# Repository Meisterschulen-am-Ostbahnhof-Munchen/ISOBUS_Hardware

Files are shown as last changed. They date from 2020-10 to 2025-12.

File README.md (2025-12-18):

# ISOBUS Hardware

Welcome to the **ISOBUS Hardware** repository by **Meisterschulen am Ostbahnhof, München**. This repository hosts hardware designs for Open Source ISOBUS ECUs.

## 📂 Projects

### [Hutschienenmoped](./Hutschienenmoped)
The **Hutschienenmoped** is an Open Source ISOBUS ECU designed for DIN rail mounting.

* **📂 Source Code:** [View Directory](./Hutschienenmoped)
* **📖 Documentation:** [Read the Docs](https://install-isobus-environment-docs.readthedocs.io/de/latest/HutschienenMoped.html)

---

### [Hutschienenmoped XL](./Hutschienenmoped-XL)
The **Hutschienenmoped XL** is an extended version of the Open Source ISOBUS ECU.

* **📂 Source Code:** [View Directory](./Hutschienenmoped-XL)
* **🏅 Open Hardware:** Certified under [DE000145](https://certification.oshwa.org/de000145.html)

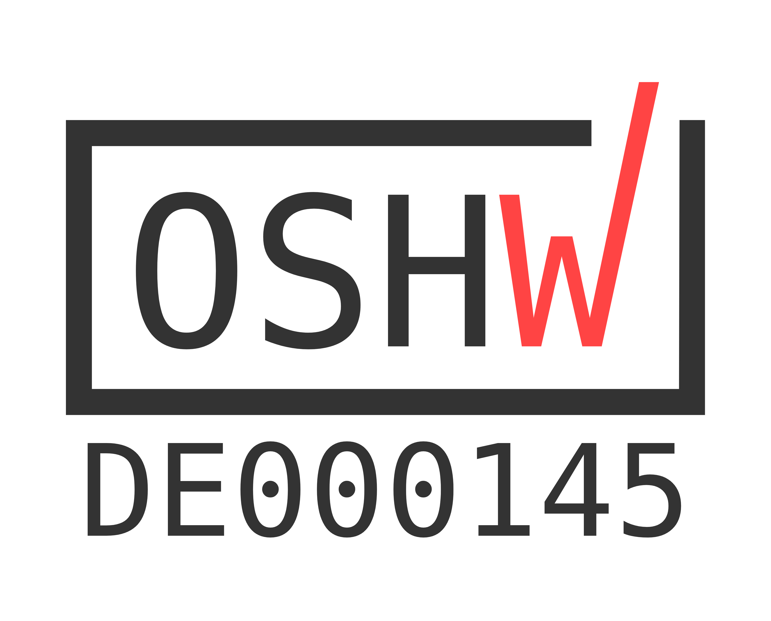
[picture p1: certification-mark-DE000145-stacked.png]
OSHWA Certification DE000145


## 📜 License

This project is licensed under a **Creative Commons Attribution-ShareAlike 4.0 International License (CC BY-SA 4.0)**.

* **Hutschienenmoped** by Meisterschulen am Ostbahnhof, München
* **ISOBUS_Hardware** by Meisterschulen am Ostbahnhof, München



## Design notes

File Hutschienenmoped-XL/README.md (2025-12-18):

# Hutschienenmoped XL

Das **Hutschienenmoped XL** ist ein innovatives Gerät, das speziell für die Integration in ISOBUS-Systeme entwickelt wurde. Es handelt sich dabei um eine Open-Source-ECU (Electronic Control Unit), die mit den Standards **ISO 11783** und **IEC 61499** kompatibel ist. Diese Kompatibilität ermöglicht eine nahtlose Kommunikation und Steuerung von landwirtschaftlichen Maschinen und Anbaugeräten.

### Vorteile
* **Flexibilität:** Durch die Open-Source-Natur des Projekts können Benutzer die Software und Hardware nach ihren Bedürfnissen anpassen und erweitern.
* **Kompatibilität:** Es unterstützt eine Vielzahl von ISOBUS-kompatiblen Geräten, was die Integration in bestehende Systeme erleichtert.
* **Zukunftssicherheit:** Dank der Einhaltung internationaler Standards ist das Gerät zukunftssicher und kann in verschiedenen landwirtschaftlichen Anwendungen eingesetzt werden.

---

## 🛠 CAD & 3D-Design (Fusion 360)

Das Projekt wird derzeit in Fusion 360 migriert. Hier finden Sie die aktuellen Modelle:

* 🔌 **[Hauptplatine (PCB)](https://a360.co/3YcFeBx)**
* 📦 **[Zusammenbau (Assembly)](https://a360.co/4cJ5Ajy)**

### Galerie

Hauptplatine Ansicht 1

Hauptplatine Ansicht 2

Gehäuse Ansicht

---

## 📜 Lizenz

Dieses Projekt ist lizenziert unter einer **Creative Commons Attribution-ShareAlike 4.0 International License (CC BY-SA 4.0)**.

* **Urheber:** [Meisterschulen am Ostbahnhof, München](https://github.com/Meisterschulen-am-Ostbahnhof-Munchen)
* **Projekt:** [Hutschienenmoped](https://github.com/Meisterschulen-am-Ostbahnhof-Munchen/ISOBUS_Hardware)



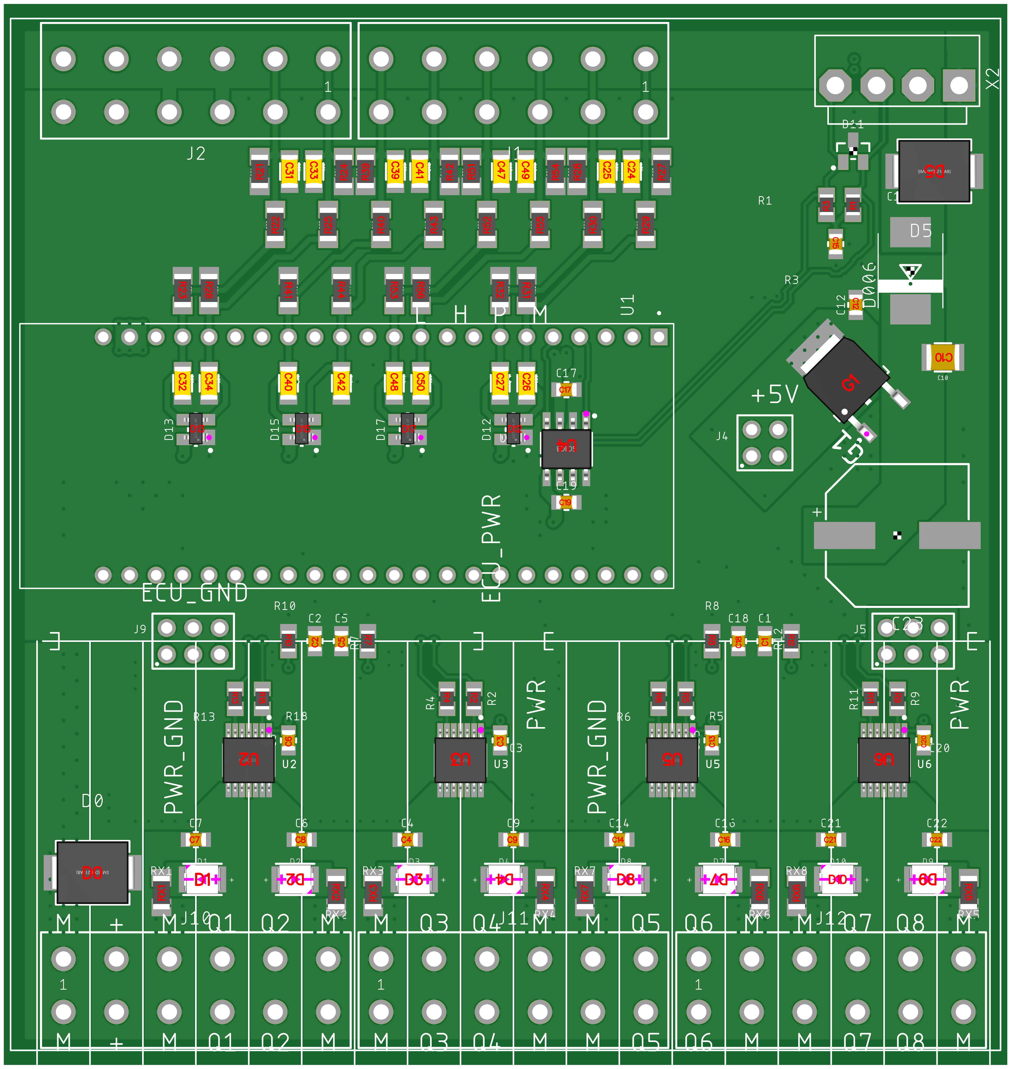
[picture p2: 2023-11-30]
Hutschienenmoped-XL/3ead6b43bb714cc0af7176151830c89e.png

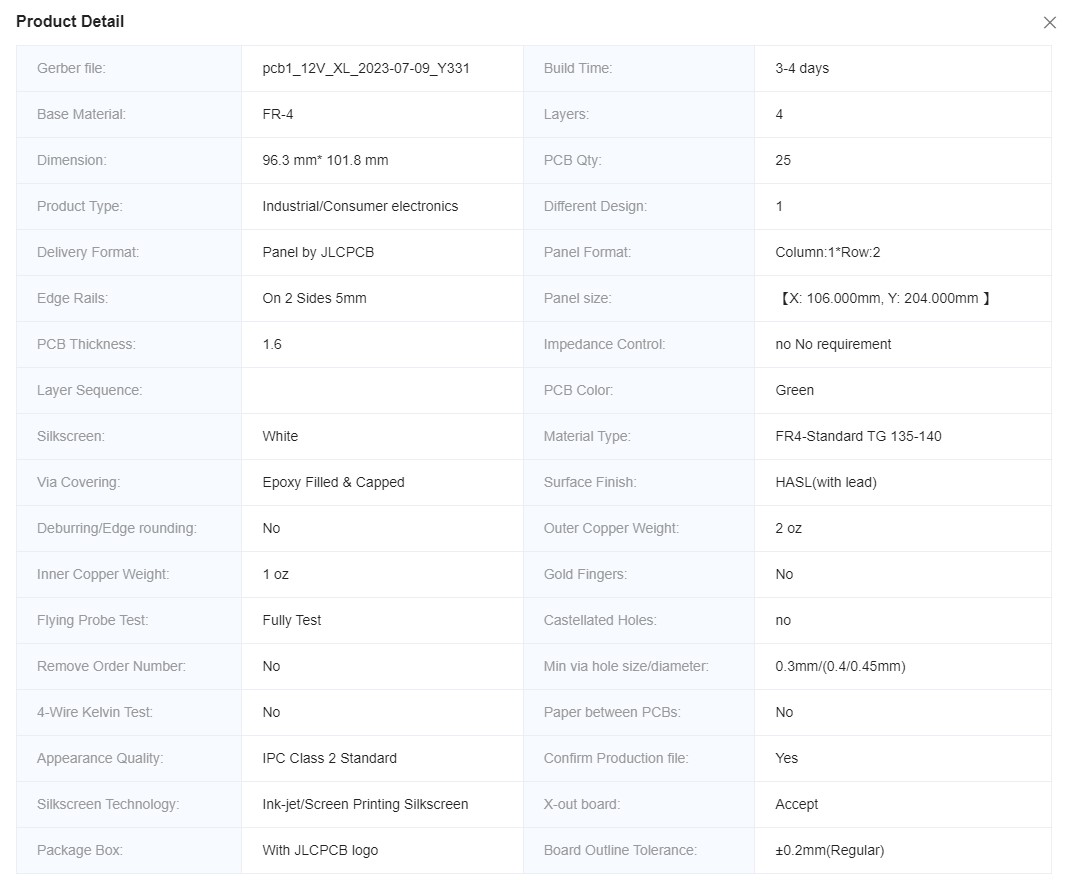
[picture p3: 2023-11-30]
Hutschienenmoped-XL/Screenshot 2023-11-30 084542.jpg

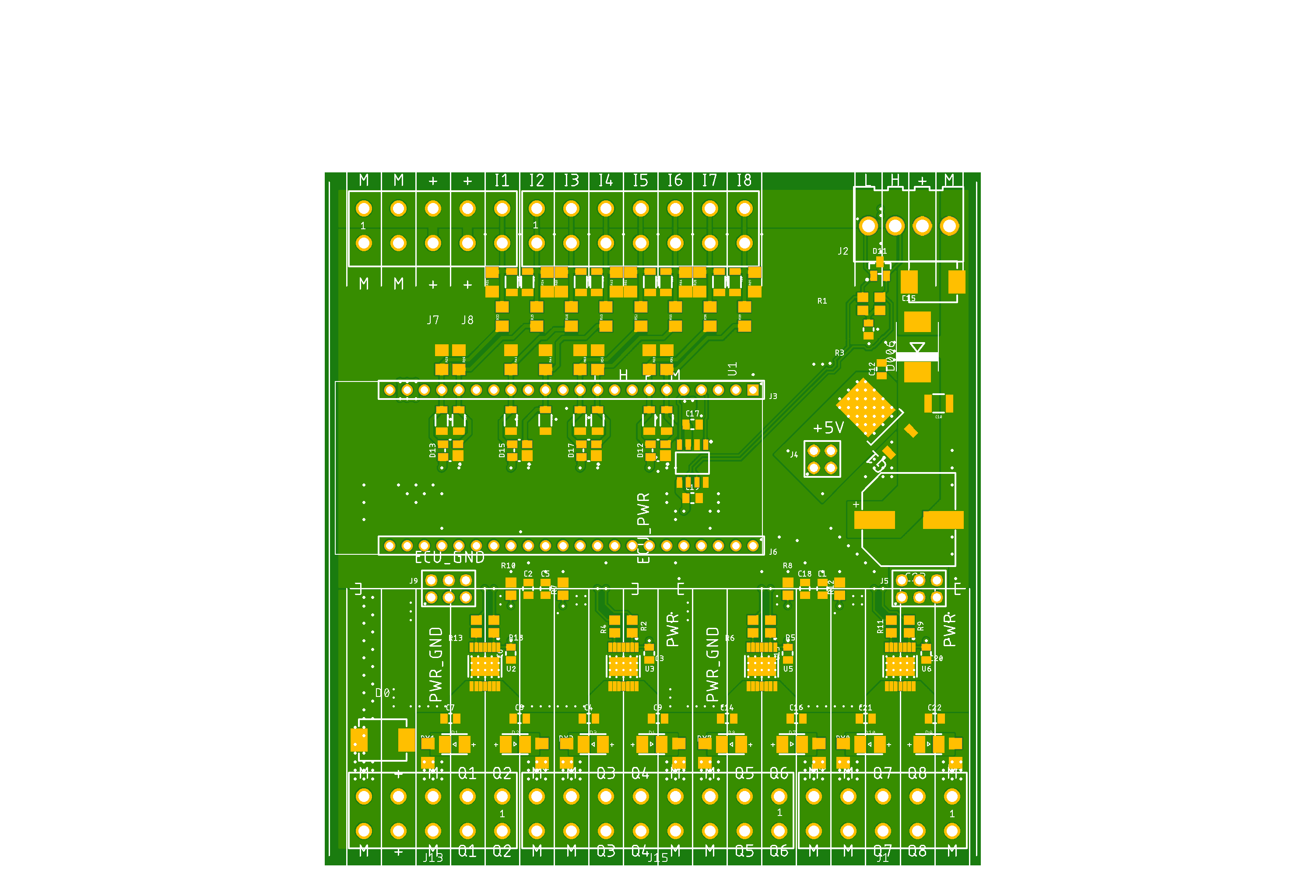
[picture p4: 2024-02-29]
Hutschienenmoped-XL/Hauptplatine/Hauptplatine.png

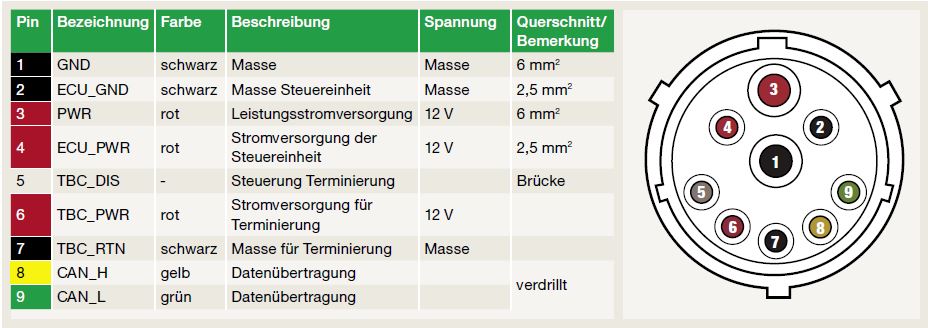
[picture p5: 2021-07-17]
Hutschienenmoped/Übersicht2.jpg

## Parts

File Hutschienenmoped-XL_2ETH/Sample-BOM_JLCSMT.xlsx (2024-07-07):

Comment | Designator | Footprint | JLCPCB Part #（optional）
 | J5, J9 | 61300621121
 | U2, U3, U5, U6 | SOP65P600X115-15N-V
 | G1 | INF-PG-TO252-3-11_N
61300421121 | J4 | 61300421121
61300615721 | W1-J2, W2-J2 | 61300615721
61301015721 | W1-J1, W2-J1 | 61301015721
61302211821 | ESP32-J1, ESP32-J3 | 61302211821
638207222005 | J1, J7, J13 | 638207222005
638207222007 | J8 | 638207222007
638207222008 | J15 | 638207222008
100nF | C1, C2, C3, C5, C6, C13, C17, C18, C19, C20 | WCAP-CSGP_0805_H0.8_R
100nF | C24, C25, C26, C27, C31, C32, C33, C34, C39, C40, C41, C42, C47, C48, C49, C50 | WCAP-CSGP_1206_H0.8
10nF | C4, C7, C8, C9, C14, C16, C21, C22 | WCAP-CSGP_0805_H0.8_R
13K | R14, R15, R23, R26, R31, R32, R41, R44, R53, R56 | R1206
150141VS73100 | D1, D2, D3, D4, D7, D8, D9, D10 | WL-SMTW_3528
1K2 | R21, R24, R27, R28, R39, R42, R51, R54 | R1206
22uF | C12 | WCAP-CSGP_0805_H1.25_R
22uF | C10 | WCAP-CSGP_1210_H2.5
24Vdc | D11 | WE-TVS_SOT23-3L
3.3Vdc | D12, D13, D15, D17 | WE-TVS_SOT143-4L
330 ÂµF | C23 | WCAP-ASLI_12.5X14(DXL)
33V | D0, D5 | WE-TVSP_DO-214AB_BIDIRECTIONAL
470Ohm | RX1, RX2, RX3, RX4, RX5, RX6, RX7, RX8 | R1206
47K | R22, R25, R29, R30, R40, R43, R52, R55 | R1206
47R | R7, R8, R10, R12 | R0805
47nF | C15 | WCAP-CSGP_0805_H0.8_R
4k7 | R2, R4, R5, R6, R9, R11, R13, R18 | R0805
60R | R1, R3 | R0805
645004114822 | J2 | 645004114822
M3 x 2.5mm | MP1, MP2, MP3, MP4, MP5, MP6, MP7, MP8 | WA-SMSI_9774025360
MBRS340T3 | D006 | SMC
TLE9250VSJ | U4 | SOIC127P602X173-8N-V

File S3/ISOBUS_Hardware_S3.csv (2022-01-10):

Qty | Value | Device | Package | Parts | Description | DATASHEET-URL | DESCRIPTION | DF | DIAMETER | GENDER | HEIGHT | I-LEAK | I-OUTPUT | I-RIPPLE | IR | L | MANUFACTURER_NAME | MANUFACTURER_PART_NUMBER | MOUNT | MOUSER_PART_NUMBER | MOUSER_PRICE-STOCK | OPERATING-TEMPERATURE | PACKAGING | PART-NUMBER | PINS | PITCH | ROWS | TECHNICAL-REFERENCE | TYPE | V-INPUT | V-OUTPUT | VALUE | VR
1 |  | MAGI³C-FDSM_SIP-3_173010542_173XXXX42 | MAGI³C-FDSM_173XXXX42 | U1 | MagI³C-FDSM Fixed Step Down Regulator Module | https://www.we-online.de/katalog/datasheet/173010542.pdf |  |  |  |  |  |  | 1A |  |  |  |  |  | THT |  |  |  |  | 173010542 |  |  |  |  |  | 8-42V | 5V
2 |  | R-EU_0204/7 | 0204/7 | R1, R2 | RESISTOR, European symbol
2 | 61304421821 | 6130XX21821_61304421821 | 61304421821 | J1, J2 | WR-PHD 2.54 mm Dual Socket Header | https://www.we-online.com/catalog/datasheet/61304421821.pdf |  |  |  | Socket Header |  |  |  |  | 3A |  |  |  | THT |  |  |  | Tray | 61304421821 | 44 | 2.54mm | Dual |  | Straight |  |  | 61304421821
1 | 220 µF | WCAP-ATG8_6.3X11_860010373010 | WCAP-ATG8_6.3X11(DXL) | C6 | WCAP-ATG8 Aluminium Electrolytic Capacitors | https://www.we-online.com/catalog/datasheet/860010373010.pdf |  | 16% | 6.3mm |  |  | 35.2uA |  | 308mA |  | 11mm |  |  |  |  |  | -40 °C up to +85 °C |  | 860010373010 |  | 2.5mm |  | ATBD110221M016DSPA4B000 |  |  |  | 220 µF | 16V(DC)
1 | DTF13-4P | DTF13-4P | DTF134P | J3 | Automotive Connectors 4P DTF RECP ASM 90 DEG. HEADER |  | Automotive Connectors 4P DTF RECP ASM 90 DEG. HEADER |  |  |  | 20.22mm |  |  |  |  |  | TE Connectivity | DTF13-4P |  | 571-DTF13-4P | https://www.mouser.co.uk/ProductDetail/TE-Connectivity-DEUTSCH/DTF13-4P?qs=vkMqrgFpRaj6YYUKpv5OLg%3D%3D
4 | FG18X7R1H104KNT06 | FG18X7R1H104KNT06 | FG18C0G1H101JNT06 | C1, C2, C4, C5 | Multilayer Ceramic Capacitors MLCC - Leaded RAD 50V 0.1uF X7R 10% LS:2.5mm |  | Multilayer Ceramic Capacitors MLCC - Leaded RAD 50V 0.1uF X7R 10% LS:2.5mm |  |  |  | 5.5mm |  |  |  |  |  | TDK | FG18X7R1H104KNT06 |  | 810-FG18X7R1H104KNT6 | https://www.mouser.co.uk/ProductDetail/TDK/FG18X7R1H104KNT06?qs=qf2ddTMq67WA8sH6FratLA%3D%3D
1 | FG28X7R1H473KNT06 | FG28X7R1H473KNT06 | FG28 | C3 | MLCC with dipped radial lead |  | MLCC with dipped radial lead |  |  |  | 5.5mm |  |  |  |  |  | TDK | FG28X7R1H473KNT06 |  | 810-FG28X7R1H473KNT6 | https://www.mouser.com/Search/Refine.aspx?Keyword=810-FG28X7R1H473KNT6
1 | MCP2562-E_P | MCP2562-E_P | DIP781W56P254L950H533Q8N | IC1 | CAN Transceiver 1Mbps 5V 125degC PDIP8 Microchip MCP2562-E/P, CAN Transceiver 1-channel IEC 61000-4-2, 8-Pin PDIP |  | CAN Transceiver 1Mbps 5V 125degC PDIP8 Microchip MCP2562-E/P, CAN Transceiver 1-channel IEC 61000-4-2, 8-Pin PDIP |  |  |  | 5.334mm |  |  |  |  |  | Microchip | MCP2562-E/P |  | 579-MCP2562-E/P | https://www.mouser.co.uk/ProductDetail/Microchip-Technology/MCP2562-E-P?qs=6qKXPk0vzx1U%252B0h82Z%2Fybg%3D%3D

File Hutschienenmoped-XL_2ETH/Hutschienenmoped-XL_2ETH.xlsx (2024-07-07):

Qty | Value | Device | Package | Parts | Description
2 |  | 6130XX21121_61300621121 | 61300621121 | J5, J9 | WR-PHD 2.54 mm THT Dual Pin Header
4 |  | BTS7030-2EPA | SOP65P600X115-15N-V | U2, U3, U5, U6 | BTS7030-2EPA
1 |  | IFX27001TF_V50 | INF-PG-TO252-3-11_N | G1 | IFX27001TF V50
1 | 61300421121 | 6130XX21121_61300421121 | 61300421121 | J4 | WR-PHD 2.54 mm THT Dual Pin Header
2 | 61300615721 | 6130XX15721_61300615721 | 61300615721 | W1-J2, W2-J2 | WR-PHD 2.54 mm Socket Header Bottom Entry
2 | 61301015721 | 6130XX15721_61301015721 | 61301015721 | W1-J1, W2-J1 | WR-PHD 2.54 mm Socket Header Bottom Entry
2 | 61302211821 | 6130XX11821_61302211821 | 61302211821 | ESP32-J1, ESP32-J3 | WR-PHD 2.54 mm Socket Header
3 | 638207222005 | 638207222005 | 638207222005 | J1, J7, J13 | WR-FAST 5.08 mm THT Male Header Vertical Blade 2863
1 | 638207222007 | 638207222007 | 638207222007 | J8 | WR-FAST 5.08 mm THT Male Header Vertical Blade 2863
1 | 638207222008 | 638207222008 | 638207222008 | J15 | WR-FAST 5.08 mm THT Male Header Vertical Blade 2863
10 | 100nF | WCAP-CSGP_0805_H0.8_885012207098_50V(DC)_R | WCAP-CSGP_0805_H0.8_R | C1, C2, C3, C5, C6, C13, C17, C18, C19, C20 | WCAP-CSGP MLCCs 0805
16 | 100nF | WCAP-CSGP_1206_H0.8_885012208087_50V(DC) | WCAP-CSGP_1206_H0.8 | C24, C25, C26, C27, C31, C32, C33, C34, C39, C40, C41, C42, C47, C48, C49, C50 | WCAP-CSGP MLCCs 1206
8 | 10nF | WCAP-CSGP_0805_H0.8_885012207092_50V(DC)_R | WCAP-CSGP_0805_H0.8_R | C4, C7, C8, C9, C14, C16, C21, C22 | WCAP-CSGP MLCCs 0805
10 | 13K | R-EU_R1206 | R1206 | R14, R15, R23, R26, R31, R32, R41, R44, R53, R56 | RESISTOR, European symbol
8 | 150141VS73100 | WL-SMTW_3528_150141VS73100 | WL-SMTW_3528 | D1, D2, D3, D4, D7, D8, D9, D10 | WL-SMTW SMT Mono-color TOP LED Waterclear
8 | 1K2 | R-EU_R1206 | R1206 | R21, R24, R27, R28, R39, R42, R51, R54 | RESISTOR, European symbol
1 | 22uF | WCAP-CSGP_0805_H1.25_885012107011_10V(DC) | WCAP-CSGP_0805_H1.25_R | C12 | WCAP-CSGP MLCCs 0805
1 | 22uF | WCAP-CSGP_1210_H2.5_885012109014_25V(DC) | WCAP-CSGP_1210_H2.5 | C10 | WCAP-CSGP MLCCs 1210
1 | 24Vdc | WE-TVS_SOT23-3L_824094024 | WE-TVS_SOT23-3L | D11 | WE-TVS TVS Diode â€“ Standard Series
4 | 3.3Vdc | WE-TVS-HS_SOT143-4L_8240136 | WE-TVS_SOT143-4L | D12, D13, D15, D17 | WE-TVS TVS Diode â€“ High Speed Series
1 | 330 ÂµF | WCAP-ASLI_12.5X14_865080662019 | WCAP-ASLI_12.5X14(DXL) | C23 | WCAP-ASLI Aluminium Electrolytic Capacitors
2 | 33V | WE-TVSP_DO-214AB_3000W_BI_824551331 | WE-TVSP_DO-214AB_BIDIRECTIONAL | D0, D5 | WE-TVSP Power TVS Diode
8 | 470Ohm | R-EU_R1206 | R1206 | RX1, RX2, RX3, RX4, RX5, RX6, RX7, RX8 | RESISTOR, European symbol
8 | 47K | R-EU_R1206 | R1206 | R22, R25, R29, R30, R40, R43, R52, R55 | RESISTOR, European symbol
4 | 47R | R-EU_R0805 | R0805 | R7, R8, R10, R12 | RESISTOR, European symbol
1 | 47nF | WCAP-CSGP_0805_H0.8_885012207096_50V(DC)_R | WCAP-CSGP_0805_H0.8_R | C15 | WCAP-CSGP MLCCs 0805
8 | 4k7 | R-EU_R0805 | R0805 | R2, R4, R5, R6, R9, R11, R13, R18 | RESISTOR, European symbol
2 | 60R | R-EU_R0805 | R0805 | R1, R3 | RESISTOR, European symbol
1 | 645004114822 | 645004114822 | 645004114822 | J2 | WR-WTB 3.96 mm Male Vertical Locking Header
8 | M3 x 2.5mm | WA-SMSI_9774XXX360_9774025360R | WA-SMSI_9774025360 | MP1, MP2, MP3, MP4, MP5, MP6, MP7, MP8 | WA-SMSI SMT Steel Spacer with internal Thread M3
1 | MBRS340T3 | MBRS340T3 | SMC | D006 | SCHOTTKY BARRIER RECTIFIER 3.0 AMPERES 20, 30, 40 VOLT
1 | TLE9250VSJ | TLE9250VSJ | SOIC127P602X173-8N-V | U4 | TLE9250VSJ

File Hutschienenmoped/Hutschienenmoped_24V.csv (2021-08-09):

Qty | Value | Device | Package | Parts | Description | ALLIED_NUMBER | ALLIED_PRICE-STOCK | ARTIKEL_NR | CERAMIC-TYPE | CHIP-TECHNOLOGY | CONTACT-RESISTANCE | DATASHEET-URL | DESCRIPTION | DF | DIGI-KEY_PART_NUMBER | EMITTING-COLOR | GENDER | H | HEIGHT | I-V-TYP | IPEAK | IR | KOMPONENTENNUMMER | LAMDA-DOM-TYP | LAMDA-PEAK-TYP | MANUFACTURER_NAME | MANUFACTURER_PART_NUMBER | MATES | MF | MOUNT | MOUSER_PART_NUMBER | MOUSER_PRICE-STOCK | MP | OPERATING-TEMPERATURE | PACKAGE | PACKAGING | PART-NUMBER | PDISS | PHI-V-TYP | PINS | PITCH | PRATED | QMIN | RISO | ROWS | RS_PART_NUMBER | RS_PRICE-STOCK | TCR | TECHNICAL-REFERENCE | TOL-VALUE | TYPE | V-F-TYP | VALUE | VBR | VCLAMP | VIEWING-ANGLE | VR | WE-NUMBER | WORKING-VOLTAGE
1 |  | 6130XX11121_61300411121 | 61300411121 | J2 | WR-PHD 2.54 mm THT Pin Header |  |  |  |  |  |  | https://katalog.we-online.com/em/datasheet/61300411121.pdf |  |  |  |  | Pin Header |  |  |  |  | 3A |  |  |  |  |  | WR-PHD 2.54mm Angled Socket Header /SMT Socket Header/Socket Header |  |  |  |  |  |  |  | Bag | 61300411121 |  |  | 4 |  |  |  |  | Single |  |  |  |  |  | Straight
1 |  | 6130XX11121_61300511121 | 61300511121 | J3 | WR-PHD 2.54 mm THT Pin Header |  |  |  |  |  |  | https://katalog.we-online.com/em/datasheet/61300511121.pdf |  |  |  |  | Pin Header |  |  |  |  | 3A |  |  |  |  |  | WR-PHD 2.54mm Angled Socket Header /SMT Socket Header/Socket Header |  |  |  |  |  |  |  | Bag | 61300511121 |  |  | 5 |  |  |  |  | Single |  |  |  |  |  | Straight
2 |  | 6130XX21121_61300621121 | 61300621121 | J5, J9 | WR-PHD 2.54 mm THT Dual Pin Header |  |  |  |  |  |  | https://katalog.we-online.com/em/datasheet/61300621121.pdf |  |  |  |  | Pin Header |  |  |  |  | 3A |  |  |  |  |  | WR-PHD 2.54mm Angled DualSocket Header/Dual Socket Header/Dual Socket Header Bottom Entry/Dual Socket Header Bottom Entry Large/SMT Dual Socket Header/SMT Dual Socket Header Bottom Entry |  |  |  |  |  |  |  | Bag | 61300621121 |  |  | 6 |  |  |  |  | Dual |  |  |  |  |  | Board Stacker
1 |  | 6130XX21121_61301821121 | 61301821121 | J1 | WR-PHD 2.54 mm THT Dual Pin Header |  |  |  |  |  |  | https://katalog.we-online.com/em/datasheet/61301821121.pdf |  |  |  |  | Pin Header |  |  |  |  | 3A |  |  |  |  |  | WR-PHD 2.54mm Angled DualSocket Header/Dual Socket Header/Dual Socket Header Bottom Entry/Dual Socket Header Bottom Entry Large/SMT Dual Socket Header/SMT Dual Socket Header Bottom Entry |  |  |  |  |  |  |  | Bag | 61301821121 |  |  | 18 |  |  |  |  | Dual |  |  |  |  |  | Board Stacker
2 | 638207222005 | 638207222005 | 638207222005 | J6, J7 | WR-FAST 5.08 mm THT Male Header Vertical Blade 2863 |  |  |  |  |  | 20mOhm | https://www.we-online.com/catalog/datasheet/638207222005.pdf |  |  |  |  | Male |  |  |  |  | 16A |  |  |  |  |  |  |  | THT |  |  |  |  |  |  | 638207222005 |  |  | 5 | 5.08mm |  |  |  |  |  |  |  |  |  | Vertical |  | 638207222005 |  |  |  |  |  | 300V(AC)
4 | 10 nF | WCAP-CSGP_0805_H0.8_885012207092_50V(DC)_R | WCAP-CSGP_0805_H0.8_R | C4, C7, C8, C9 | WCAP-CSGP MLCCs 0805 |  |  |  | X7R Class II |  |  | https://www.we-online.com/catalog/datasheet/885012207092.pdf |  | 0.025 |  |  |  | 0.8mm |  |  |  |  |  |  |  |  |  |  |  |  |  |  |  | -55 °C up to +125 °C |  |  | 885012207092 |  |  |  |  |  | - | 10GOhm |  |  |  |  | X7R0805103K050DFCT10000 | ±10% |  |  | 10 nF |  |  |  | 50V(DC)
4 | 100 nF | WCAP-CSGP_0805_H0.8_885012207098_50V(DC)_R | WCAP-CSGP_0805_H0.8_R | C2, C5, C17, C19 | WCAP-CSGP MLCCs 0805 |  |  |  | X7R Class II |  |  | https://www.we-online.com/catalog/datasheet/885012207098.pdf |  | 0.025 |  |  |  | 0.8mm |  |  |  |  |  |  |  |  |  |  |  |  |  |  |  | -55 °C up to +125 °C |  |  | 885012207098 |  |  |  |  |  | - | 5GOhm |  |  |  |  | X7R0805104K050DFCT10000 | ±10% |  |  | 100 nF |  |  |  | 50V(DC)
1 | 100 nF | WCAP-CSGP_0402_885012205037_16V(DC) | WCAP-CSGP_0402 | C11 | WCAP-CSGP MLCCs 0402 |  |  | 545504 | X7R Class II |  |  |  |  |  |  |  |  |  |  |  |  |  |  |  |  |  |  |  |  |  |  |  |  |  |  |  | 885012205037 |  |  |  |  |  |  |  |  |  |  |  |  | ±10% |  |  | 100 nF |  |  |  | 16V(DC)
4 | 150141VS73100 | WL-SMTW_3528_150141VS73100 | WL-SMTW_3528 | D1, D2, D3, D4 | WL-SMTW SMT Mono-color TOP LED Waterclear |  |  |  |  | AlInGaP |  | https://www.we-online.com/catalog/datasheet/150141VS73100.pdf |  |  |  | Bright Green |  |  |  | 90mcd |  |  |  | 570nm | 572nm |  |  |  |  |  |  |  |  |  |  |  | 150141VS73100 |  | - |  |  |  |  |  |  |  |  |  |  |  |  | 2V | 150141VS73100 |  |  | 120°
1 | 22 µF | WCAP-CSGP_0805_H1.25_885012107011_10V(DC) | WCAP-CSGP_0805_H1.25_R | C12 | WCAP-CSGP MLCCs 0805 |  |  |  | X5R Class II |  |  | https://www.we-online.com/catalog/datasheet/885012107011.pdf |  | 0.1 |  |  |  | 1.25mm |  |  |  |  |  |  |  |  |  |  |  |  |  |  |  | -55 °C up to +85 °C |  |  | 885012107011 |  |  |  |  |  | - | 0,005GOhm |  |  |  |  | X5R0805226M010DFCT10000 | ±20% |  |  | 22 µF |  |  |  | 10V(DC)
1 | 22µF | WCAP-CSGP_1210_H2.5_885012109014_25V(DC) | WCAP-CSGP_1210_H2.5 | C10 | WCAP-CSGP MLCCs 1210 |  |  |  | X5R Class II |  |  | https://www.we-online.com/catalog/datasheet/885012109014.pdf |  | 0.05 |  |  |  | 2.5mm |  |  |  |  |  |  |  |  |  |  |  |  |  |  |  | -55 °C up to +85 °C |  |  | 885012109014 |  |  |  |  |  | - | 0,005G Ohm |  |  |  |  | X5R1210226M025DFCT10000 | ±20% |  |  | 22µF |  |  |  | 25V(DC)
1 | 26.2V / 35pF | WE-TVS_SOT23-3L_824098024 | WE-TVS_SOT23-3L | D6 | WE-TVS TVS Diode Standard Series |  |  | 531887 |  |  |  |  |  |  |  |  |  |  |  |  |  |  | 617684 |  |  |  |  |  |  |  |  |  |  |  |  |  |  |  |  |  |  |  |  |  |  |  |  |  |  |  |  |  | 26.2V / 35pF |  |  |  |  | 824098024
2 | 27R | R-EU_R0805 | R0805 | R7, R10 | RESISTOR, European symbol
2 | 2k2 | R-EU_R0805 | R0805 | R5, R6 | RESISTOR, European symbol
2 | 33V | WE-TVSP_DO-214AB_3000W_BI_824551331 | WE-TVSP_DO-214AB_BIDIRECTIONAL | D0, D5 | WE-TVSP Power TVS Diode |  |  |  |  |  |  | https://www.we-online.com/catalog/datasheet/824551331.pdf |  |  |  |  |  |  |  |  | 56.3A |  |  |  |  |  |  |  |  | SMT |  |  |  |  |  |  | 824551331 | 3000W |  |  |  |  |  |  |  |  |  |  |  |  |  |  | 33V | 38.65V | 53.3V
1 | 47 nF | WCAP-CSGP_0805_H0.8_885012207096_50V(DC)_R | WCAP-CSGP_0805_H0.8_R | C15 | WCAP-CSGP MLCCs 0805 |  |  |  | X7R Class II |  |  | https://www.we-online.com/catalog/datasheet/885012207096.pdf |  | 0.025 |  |  |  | 0.8mm |  |  |  |  |  |  |  |  |  |  |  |  |  |  |  | -55 °C up to +125 °C |  |  | 885012207096 |  |  |  |  |  | - | 10GOhm |  |  |  |  | X7R0805473K050DFCT10000 | ±10% |  |  | 47 nF |  |  |  | 50V(DC)
4 | 470Ohm | WRIS-KWKB_0612_561020132023 | WRIS-KWKB_0612 | RX1, RX2, RX3, RX4 | WRIS-KWKB Thick Film Resistors |  |  |  |  |  |  | https://katalog.we-online.de/pbs/datasheet/561020132023.pdf |  |  |  |  |  |  |  |  |  | 39.9mA |  |  |  |  |  |  |  | SMT |  |  |  |  |  |  | 561020132023 |  |  |  |  | 0.75W |  |  |  |  |  | ±200ppm/ °C | KB06124700J304DAATP0000 |  |  |  | 470Ohm
4 | 4k7 | R-EU_R0805 | R0805 | R2, R4, R13, R18 | RESISTOR, European symbol
2 | 60R | R-EU_R0805 | R0805 | R1, R3 | RESISTOR, European symbol
2 | ITS4040DEPDXUMA1 | ITS4040DEPDXUMA1 | SOP65P600X115-15N | U2, U3 | Power Switch/Driver 1:1 N-Channel 2.6A PG-TSDSO-14 |  |  |  |  |  |  |  | Power Switch/Driver 1:1 N-Channel 2.6A PG-TSDSO-14 |  | ITS4040DEPDXUMA1TR-ND |  |  |  |  |  |  |  |  |  |  |  |  |  | Infineon Technologies |  |  |  | ITS4040DEPDXUMA1 |  | TSSOP-14 Infineon Technologies
1 | S4P-VH | S4P-VH | S4P-VH | X1 | JST VH Series header 3.96mm pitch disconnectable crimp style connectors, horizontal (side entry type), 4 pins
1 | TLE4270-2D-INF-PG-TO252-5-11_L_1 | TLE4270-2D-INF-PG-TO252-5-11_L_1 | INF-PG-TO252-5-11_L_1PRIMARY | G1
1 | TLE9250VSJ | TLE9250VSJ | SOIC127P602X173-8N-V | U4 | TLE9250VSJ |  |  | 545599
2 | TS4148_RYG | TS4148_RYG | DIOC2012X95N | D007, D049 | TAIWAN SEMICONDUCTOR - TS4148 RYG - DIODE, SMALL SIGNAL, 75V, 0.15A, 0805 | 70439260 | https://www.alliedelec.com/taiwan-semiconductor-ts4148-ryg/70439260/ |  |  |  |  |  | TAIWAN SEMICONDUCTOR - TS4148 RYG - DIODE, SMALL SIGNAL, 75V, 0.15A, 0805 |  |  |  |  |  | 0.95mm |  |  |  |  |  |  | Taiwan Semiconductor | TS4148 RYG |  |  |  | 821-TS4148RYG | https://www.mouser.com/Search/Refine.aspx?Keyword=821-TS4148RYG

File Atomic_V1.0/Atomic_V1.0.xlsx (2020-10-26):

Qty | Value | Device | Package | Parts | Description | ARTIKEL_NR | CERAMIC-TYPE | DATASHEET-URL | DF | GENDER | H | I-OUTPUT | IPEAK | IR | KOMPONENTENNUMMER | MATES | MOUNT | N | OC | OPERATING-TEMPERATURE | PACKAGING | PART-NUMBER | PDISS | PINS | QMIN | RISO | ROWS | TECHNICAL-REFERENCE | TOL-VALUE | TYPE | V-INPUT | V-OUTPUT | VALUE | VBR | VCLAMP | VR | WE-NUMBER
1 |  | 6130XX11121_61300411121 | 61300411121 | J1 | WR-PHD 2.54 mm THT Pin Header |  |  | https://katalog.we-online.com/em/datasheet/61300411121.pdf |  | Pin Header |  |  |  | 3A |  | WR-PHD 2.54mm Angled Socket Header /SMT Socket Header/Socket Header |  |  |  |  | Bag | 61300411121 |  | 4 |  |  | Single |  |  | Straight
1 |  | 6130XX11121_61300511121 | 61300511121 | J2 | WR-PHD 2.54 mm THT Pin Header |  |  | https://katalog.we-online.com/em/datasheet/61300511121.pdf |  | Pin Header |  |  |  | 3A |  | WR-PHD 2.54mm Angled Socket Header /SMT Socket Header/Socket Header |  |  |  |  | Bag | 61300511121 |  | 5 |  |  | Single |  |  | Straight
1 |  | MAGIÂ³C-FDSM_SIP-3_173010542_173XXXX42 | MAGIÂ³C-FDSM_173XXXX42 | U1 | MagIÂ³C-FDSM Fixed Step Down Regulator Module |  |  | https://www.we-online.de/katalog/datasheet/173010542.pdf |  |  |  | 1A |  |  |  |  | THT |  |  |  |  | 173010542 |  |  |  |  |  |  |  |  | 8-42V | 5V
2 | 100 nF | WCAP-CSGP_0402_885012205037_16V(DC) | WCAP-CSGP_0402 | C17, C19 | WCAP-CSGP MLCCs 0402 | 545504 | X7R Class II |  |  |  |  |  |  |  |  |  |  |  |  |  |  | 885012205037 |  |  |  |  |  |  | Â±10% |  |  |  | 100 nF |  |  | 16V(DC)
1 | 26.2V / 35pF | WE-TVS_SOT23-3L_824098024 | WE-TVS_SOT23-3L | D6 | WE-TVS TVS Diode Â– Standard Series | 531887 |  |  |  |  |  |  |  |  | 617684 |  |  |  |  |  |  |  |  |  |  |  |  |  |  |  |  |  | 26.2V / 35pF |  |  |  | 824098024
1 | 26V | WE-TVSP_DO-214AC_400W_BI_824501261 | WE-TVSP_DO-214AC_BIDIRECTIONAL | D1 | WE-TVSP Power TVS Diode |  |  | https://katalog.we-online.com/pbs/datasheet/824501261.pdf |  |  |  |  | 9.5A |  |  |  | SMT |  |  |  |  | 824501261 | 400W |  |  |  |  |  |  |  |  |  | 26V | 30.4V | 42.1V
1 | 47 nF | WCAP-CSGP_0402_885012205054_25V(DC) | WCAP-CSGP_0402 | C15 | WCAP-CSGP MLCCs 0402 | 545508 | X7R Class II |  |  |  |  |  |  |  |  |  |  |  |  |  |  | 885012205054 |  |  |  |  |  |  | Â±10% |  |  |  | 47 nF |  |  | 25V(DC)
1 | 47uF | WCAP-CSGP_1210_H2.5_885012109014_25V(DC) | WCAP-CSGP_1210_H2.5 | C1 | WCAP-CSGP MLCCs 1210 |  | X5R Class II | https://www.we-online.com/catalog/datasheet/885012109014.pdf | 0.05 |  | 2.5mm |  |  |  |  |  |  |  |  | -55 Â°C up to +85 Â°C |  | 885012109014 |  |  | - | 0,005G Ohm |  | X5R1210226M025DFCT10000 | Â±20% |  |  |  | 22ÂµF |  |  | 25V(DC)
2 | 60.4R 1% | R-0402_60.4OHMS_1%_AEC-Q200 | WCAP-CSRF_0402 | R21, R22 | RESISTOR, European symbol | 546940 |  |  |  |  |  |  |  |  |  |  |  | SMD 0402 60.4ohms 1% AEC-Q200 |  |  |  |  |  |  |  |  |  |  |  |  |  |  | 60.4R 1%
1 | S4P-VH | S4P-VH | S4P-VH | X1 | JST VH Series header 3.96mm pitch disconnectable crimp style connectors, horizontal (side entry type), 4 pins
1 | SS12L R3 | S1ML | SMA | D2 | DIODE | 505165 |  |  |  |  |  |  |  |  |  |  |  |  | Farnell 1559155
1 | TLE9250VSJ | TLE9250VSJ | SOIC127P602X173-8N-V | U4 | TLE9250VSJ | 545599

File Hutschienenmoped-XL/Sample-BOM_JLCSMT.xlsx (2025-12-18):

Comment | Designator | Footprint | JLCPCB Part #（optional）
 | RESET | 4312560837X6
 | J5, J9 | 61300621121
 | U2, U3 | SOP65P600X115-15N-V
638207222005 | J1, J7, J13 | 638207222005
638207222007 | J8 | 638207222007
638207222008 | J15 | 638207222008
0R | R62, R63 | RESC1608X60
1 nF | C13, C20 | WCAP-CSGP_0603_H0.8_R
100 nF | C11, C26, C27, C28, C32, C34, C40, C42, C48, C50 | WCAP-CSGP_0603_H0.8_R
100 nF | C1, C2, C3, C5, C6, C17, C18, C19, C35, C36 | WCAP-CSGP_0603_H0.8_R
10K | R21, R24, R27, R28, R39, R42, R51, R54 | RESC1608X60
13K | R14, R15, R16, R17, R19, R20, R33, R34 | RESC1608X60
150141VS73100 | D1, D2, D3, D4, D7, D8, D9, D10 | WL-SMTW_3528
1k2 | R35, R36 | RESC1005X40
22 µF | C12 | WCAP-CSGP_0805_H1.25_R
22 µF | C10 | WCAP-CSGP_1210_H2.5
22K | R23, R26, R31, R32, R41, R44, R53, R56 | RESC1608X60
24Vdc | D11 | WE-TVS_SOT23-3L
33 nF | C4, C7, C8, C9, C14, C16, C21, C22, C24, C25, C31, C33, C39, C41, C47, C49 | WCAP-CSGP_0603_H0.8_R
330 µF | C23 | WCAP-ASLI_12.5X14(DXL)
330 µF | C29, C30 | WCAP-ASLI_8X10.5(DXL)
33V | D0, D5 | WE-TVSP_DO-214AB_BIDIRECTIONAL
47 nF | C15 | WCAP-CSGP_0603_H0.8_R
470Ohm | RX1, RX2, RX3, RX4, RX5, RX6, RX7, RX8 | RESC3216X70
47K | R22, R25, R29, R30, R40, R43, R52, R55 | RESC1608X60
47R | R7, R10 | RESC1005X40
4k7 | R2, R4, R5, R6, R9, R11, R13, R18, R37, R38 | RESC1005X40
510R | R45, R46, R47, R48, R49, R50, R57, R58 | RESC3216X70
60R | R1, R3 | RESC2012X65
61300421121 | J4 | 61300421121
61302211821 | ESP32-J1, ESP32-J3 | 61302211821
62100421021 | J3, J6, J10, J11 | 62100421021
645004114822 | J2 | 645004114822
820R | R8, R12 | RESC1005X40
BAS70-04 | D012, D015, D024, D026, D028, D030, D032, D034 | SOT23
BTM9010EP | U1, U5 | BTM9010EP
DMT6007LFG-7 | Q1 | DMP4013LFG7
EDZVT2R3.3B | D013, D017, D025, D027, D029, D031, D033, D035 | SODFL1608X70N
GS1J-L | D014, D016, D018, D019, D020, D021, D022, D023 | DIOM5226X290N
LM74700QDBVTQ1 | IC1 | SOT95P280X145-6N
MBRS340T3 | D006 | SMC
NCV1117DT50RKG | IC2 | NCV1117DT50RKG
SMD3216-090N | U6, U8, U9, U10, U11, U12, U13, U14 | SMD3216-090N
TLE9250VSJ | U4 | SOIC127P602X173-8N-V

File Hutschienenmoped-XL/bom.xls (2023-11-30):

Comment | Designator | Footprint | JLCPCB Part #
100nF | C24,C25,C26,C27,C31,C32,C33,C34,C39,C40,C41,C42,C47,C48,C49,C50 | WCAP-CSGP_1206_H0.8 | C24497
13K | R23,R26,R31,R32,R41,R44,R53,R56 | R1206 | C294765
330?μF | C23 | WCAP-ASLI_12.5X14(DXL) | C5155336
10nF | C4,C7,C8,C9,C14,C16,C21,C22 | WCAP-CSGP_0805_H0.8_R | C1710
4k7 | R2,R4,R5,R6,R9,R11,R13,R18 | R0805 | C17673
22uF | C12 | WCAP-CSGP_0805_H1.25_R | C45783
100nF | C1,C2,C3,C5,C6,C13,C17,C18,C19,C20 | WCAP-CSGP_0805_H0.8_R | C49678
3.3Vdc | D12,D13,D15,D17 | WE-TVS_SOT143-4L | C512377
IFX27001TF_V50 | G1 | INF-PG-TO252-3-11_N | C152661
1K2 | R21,R24,R27,R28,R39,R42,R51,R54 | R1206 | C17891
470Ohm | RX1,RX2,RX3,RX4,RX5,RX6,RX7,RX8 | R1206 | C4502
60R | R1,R3 | R0805 | C2683110
24Vdc | D11 | WE-TVS_SOT23-3L | C3711787
47K | R22,R25,R29,R30,R40,R43,R52,R55 | R1206 | C25833
BTS7030-2EPA | U2,U3,U5,U6 | SOP65P600X115-15N-V | C534839
TLE9250VSJ | U4 | SOIC127P602X173-8N-V | C189937
47R | R7,R8,R10,R12 | R0805 | C17714
33V | D0,D5 | WE-TVSP_DO-214AB_BIDIRECTIONAL | C693622
MBRS340T3 | D006 | SMC | C5338043
22uF | C10 | WCAP-CSGP_1210_H2.5 | C309062
150141VS73100 | D1,D2,D3,D4,D7,D8,D9,D10 | WL-SMTW_3528 | C516138
47nF | C15 | WCAP-CSGP_0805_H0.8_R | C53134

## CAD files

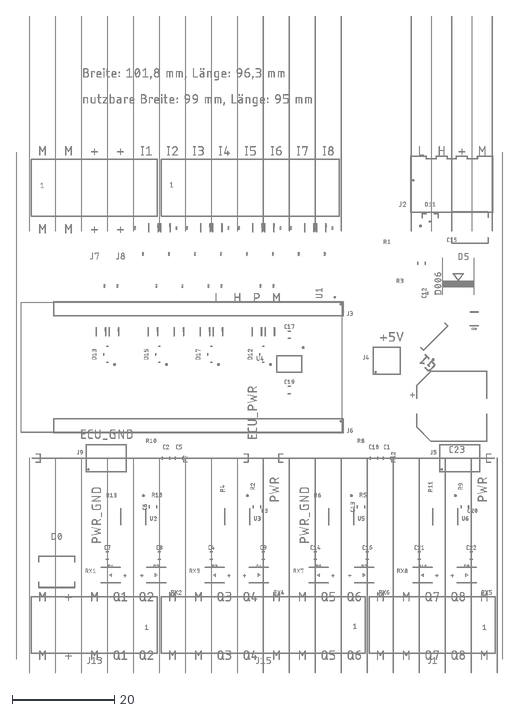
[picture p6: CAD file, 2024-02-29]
Hutschienenmoped-XL/Hauptplatine/Hauptplatine.dxf
95.2 x 128.4

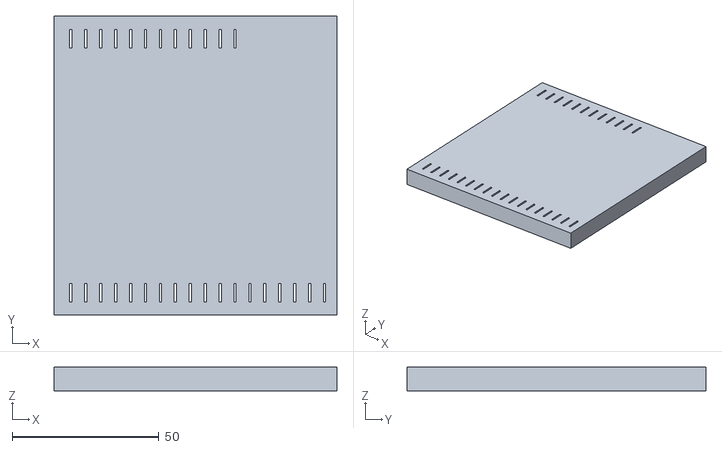
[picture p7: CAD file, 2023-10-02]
Hutschienenmoped-XL/Montagehilfe/Montagehilfe.stl
96.3 x 101.8 x 8.14

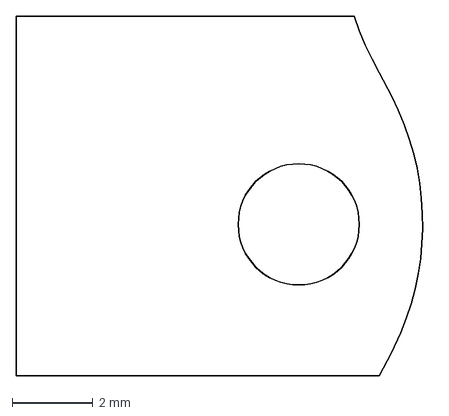
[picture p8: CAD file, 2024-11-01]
Hutschienenmoped-XL/Riegel links oben A (1)/Riegel links oben A (1).dxf
10.3 x 8.90 mm

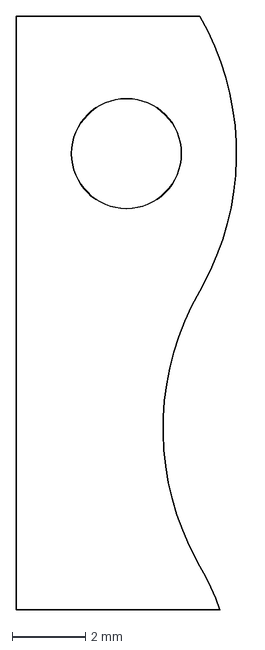
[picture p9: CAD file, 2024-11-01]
Hutschienenmoped-XL/Riegel links oben B (1)/Riegel links oben B (1).dxf
6.33 x 16.2 mm

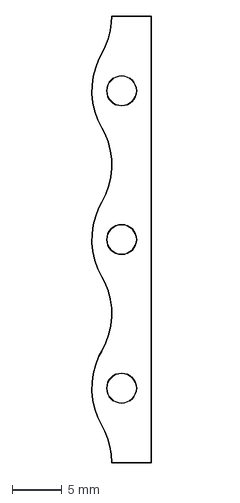
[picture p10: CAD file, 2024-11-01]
Hutschienenmoped-XL/Riegel rechts oben (1)/Riegel rechts oben (1).dxf
6.33 x 45.0 mm

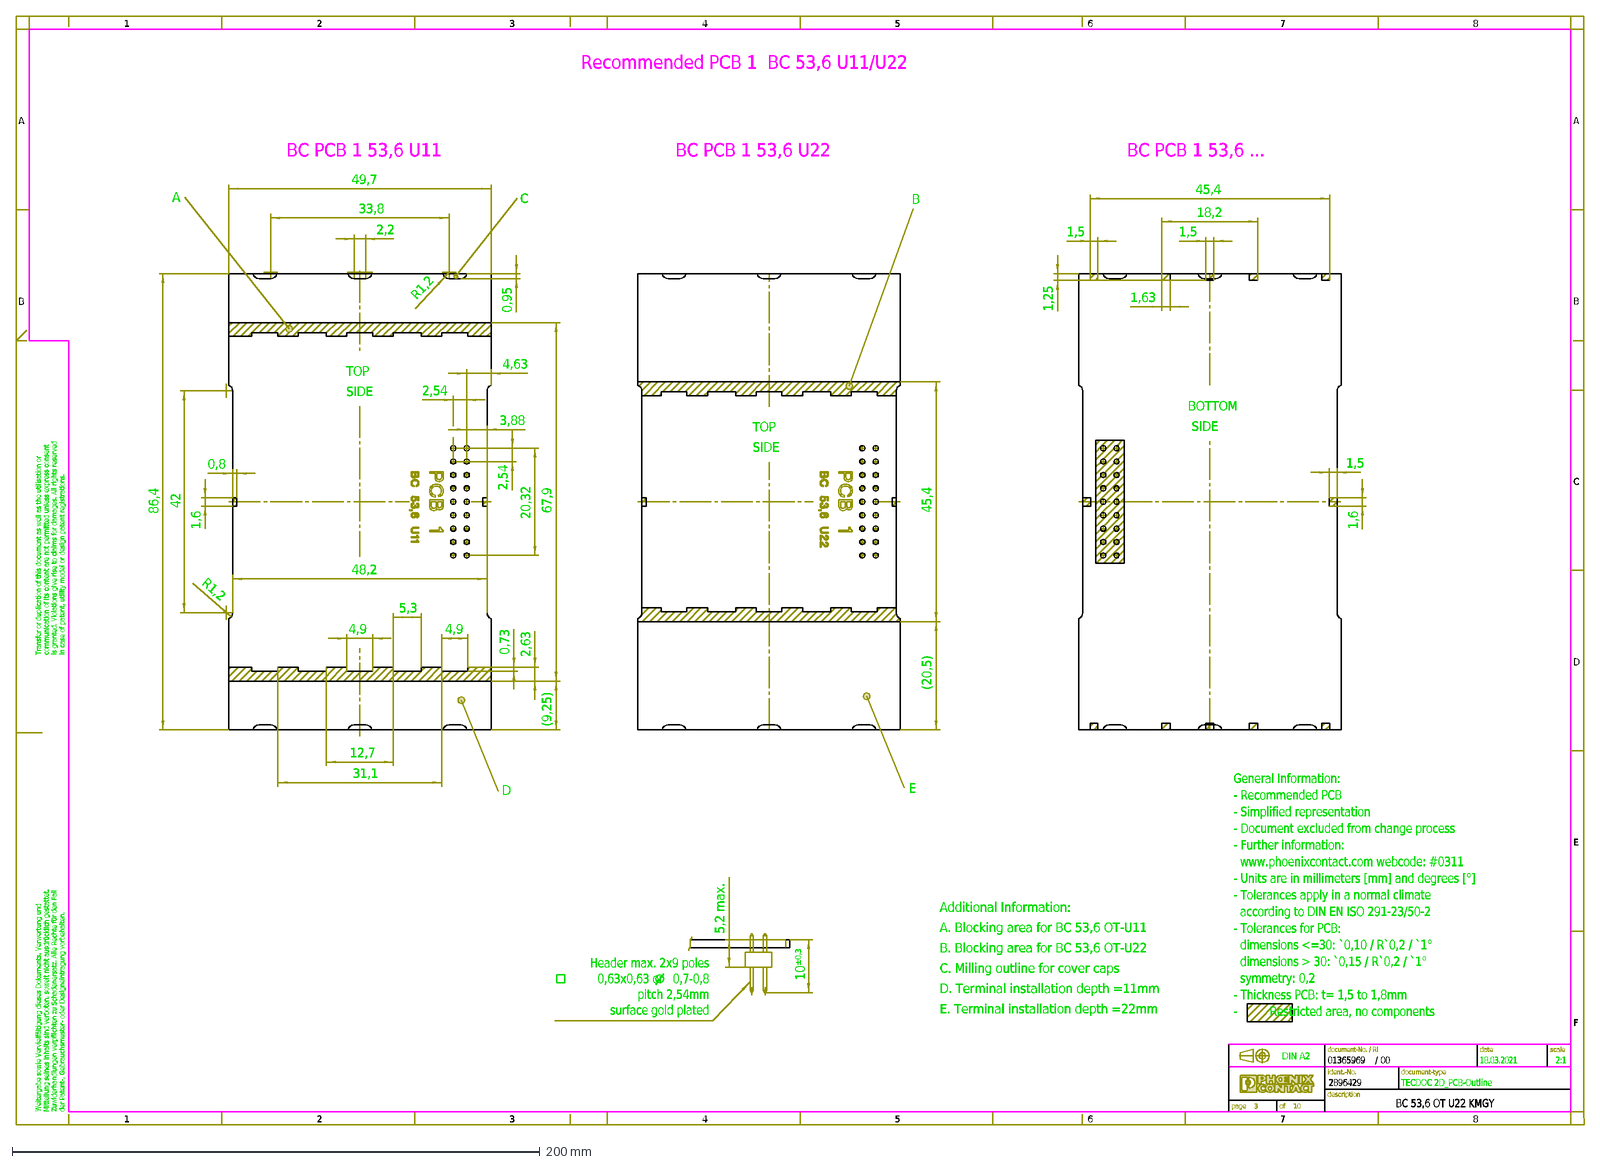
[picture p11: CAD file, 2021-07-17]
Hutschienenmoped/pxc_2896429_01_BC-53-6-OT-U22-KMGY_PCB2D_BC-PCB-1-11-EXAMPLE-BC-35-6-U11_3.dxf
BC PCB 1 53,6 ...
BOTTOM SIDE
1,5
1,63
18,2
45,4
1,6
1,25
E
B
BC PCB 1 53,6 U22
TOP SIDE
(20,5)
D
A
BC PCB 1 53,6 U11
C
4,63
4,9
31,1
(9,25)
67,9
2,54
3,88
42
0,95
86,4
12,7
5,3
0,73
2,63
0,8
48,2
2,2
33,8
20,32
49,7
R1,2
Header max. 2x9 poles 0,63x0,63 or 0,7-0,8 pitch 2,54mm surface gold plated
10±0,3
5,2 max.
1
2
3
4
5
6
7
8
F
in case of patent, utility model or design patent registrations.
is granted. Violations give rise to claims for damages. All rights reserved
communication of its content are not permitted unless express consent
Transfer or duplication of this document as well as the utilisation or
der Patent-, Gebrauchsmuster- oder Designeintragung vorbehalten.
Zuwiderhandlungen verpflichten zu Schadenersatz. Alle Rechte für den Fall
Mitteilung seines Inhalts sind verboten, soweit nicht ausdrücklich gestattet.
Weitergabe sowie Vervielfältigung dieses Dokuments, Verwertung und
/
00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

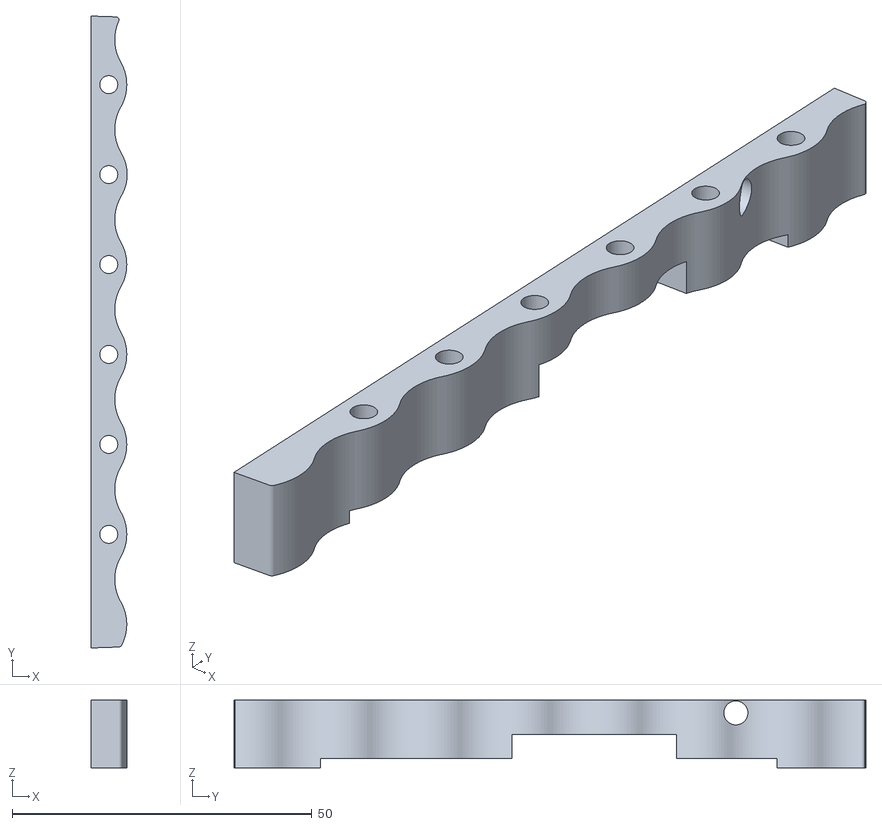
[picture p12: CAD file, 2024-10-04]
XL-accessories/Board_4_Buttons/3D/Riegel Links unten.stl
6.07 x 105.4 x 11.3

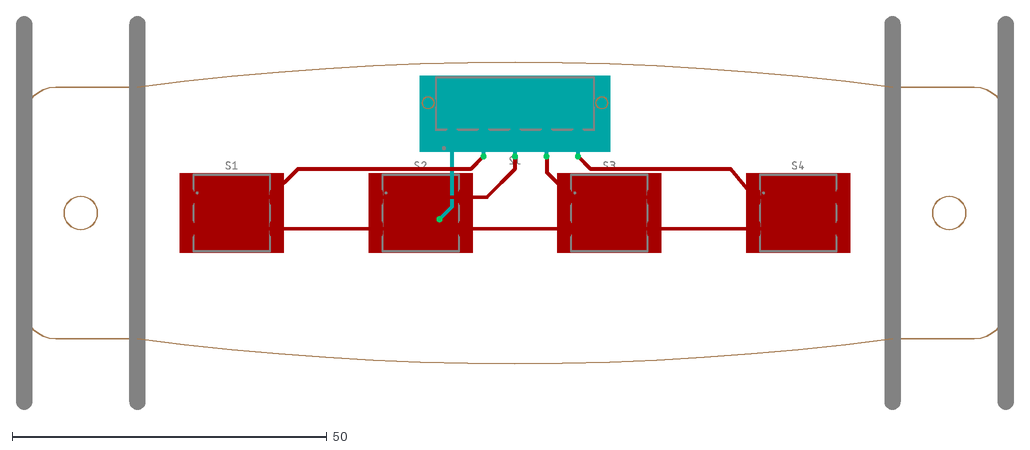
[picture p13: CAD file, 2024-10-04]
XL-accessories/Board_4_Buttons/Board_4_Buttons_WS-TASV_ SMD Plug.dxf
158.5 x 62.5

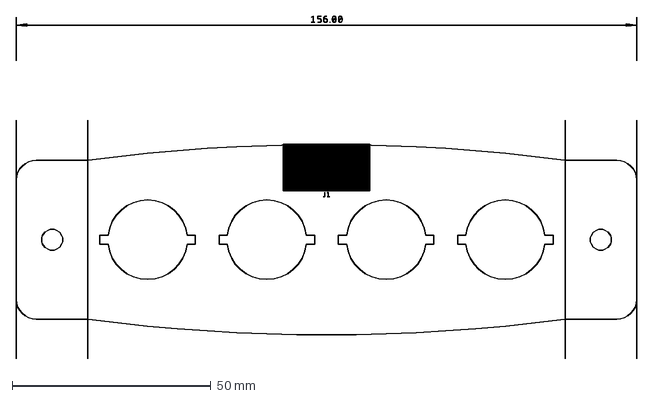
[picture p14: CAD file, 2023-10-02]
XL-accessories/Board_4_Wippen/Board_4_Wippen.dxf
156.0 x 86.3 mm

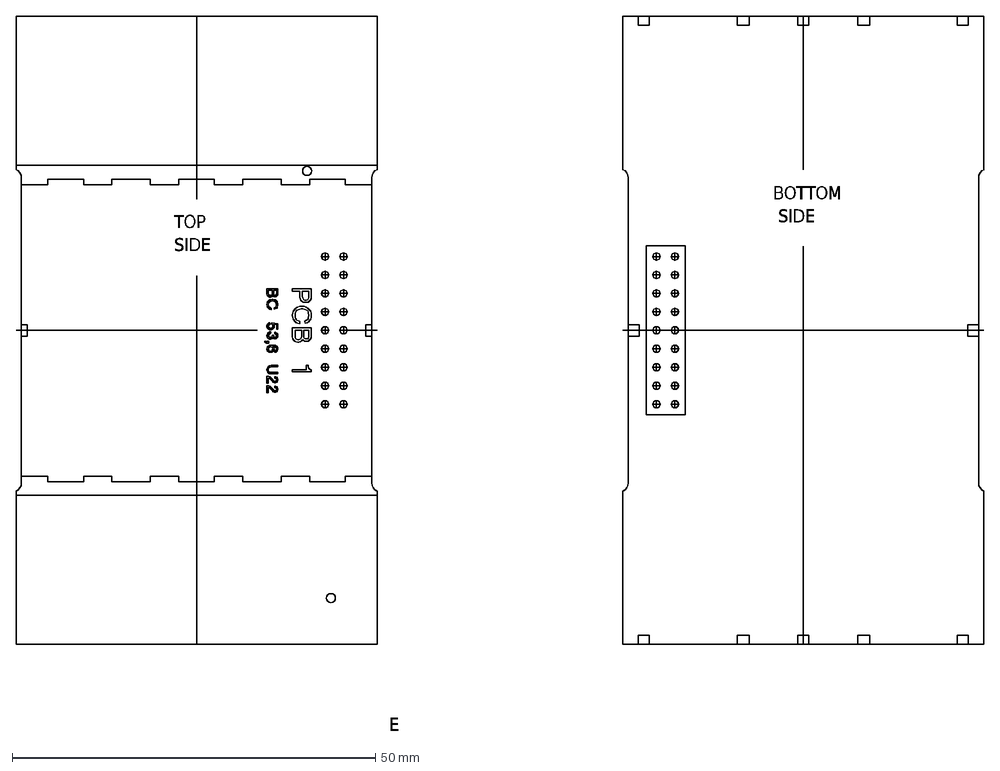
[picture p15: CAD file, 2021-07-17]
Hutschienenmoped/Hutschienenmoped.dxf
BOTTOM
SIDE
E
TOP

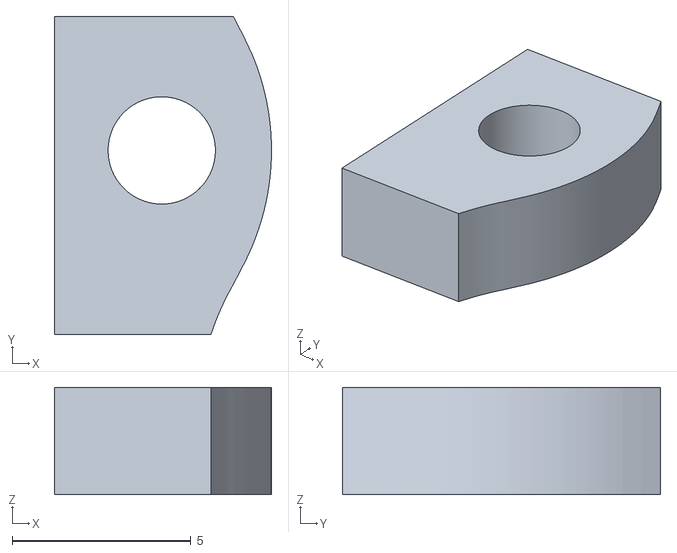
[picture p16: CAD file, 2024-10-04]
XL-accessories/Board_4_Buttons/3D/Riegel rechts oben A.stl
6.07 x 8.90 x 3.00

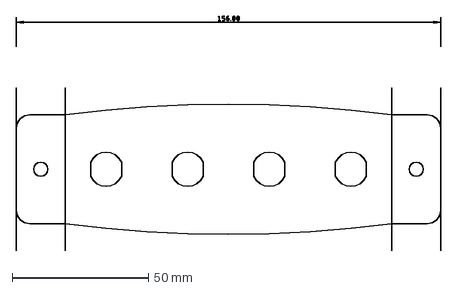
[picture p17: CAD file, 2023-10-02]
XL-accessories/Board_4_Buttons/Board_4_Buttons.dxf
156.0 x 86.3 mm

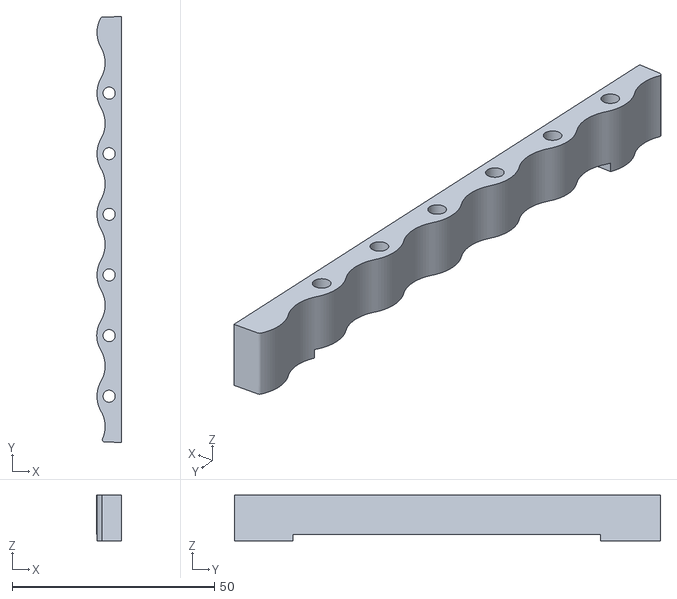
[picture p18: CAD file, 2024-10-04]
XL-accessories/Board_4_Buttons/3D/Riegel Rechts unten.stl
6.07 x 105.4 x 11.3

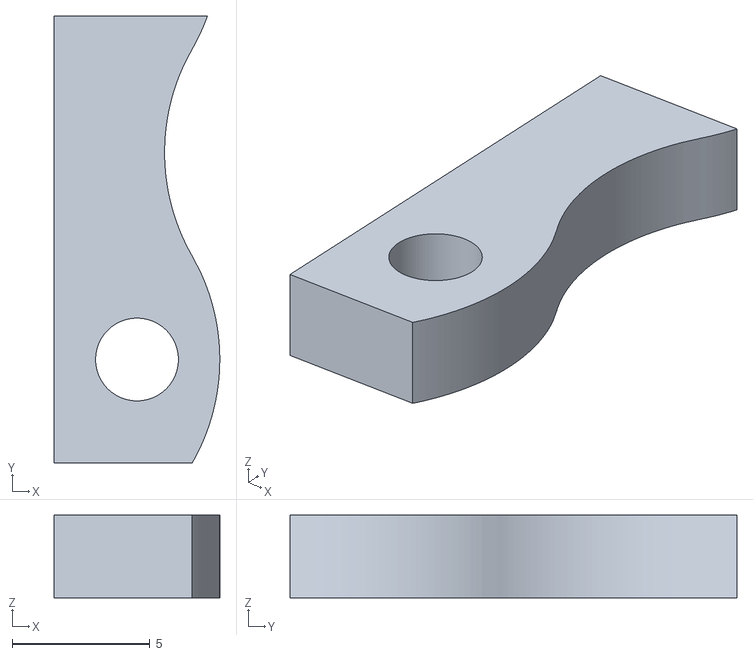
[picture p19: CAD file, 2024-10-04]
XL-accessories/Board_4_Buttons/3D/Riegel rechts oben B.stl
6.00 x 16.2 x 3.00

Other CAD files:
XL-accessories/Board_4_Buttons/3D/Riegel rechts oben.stl

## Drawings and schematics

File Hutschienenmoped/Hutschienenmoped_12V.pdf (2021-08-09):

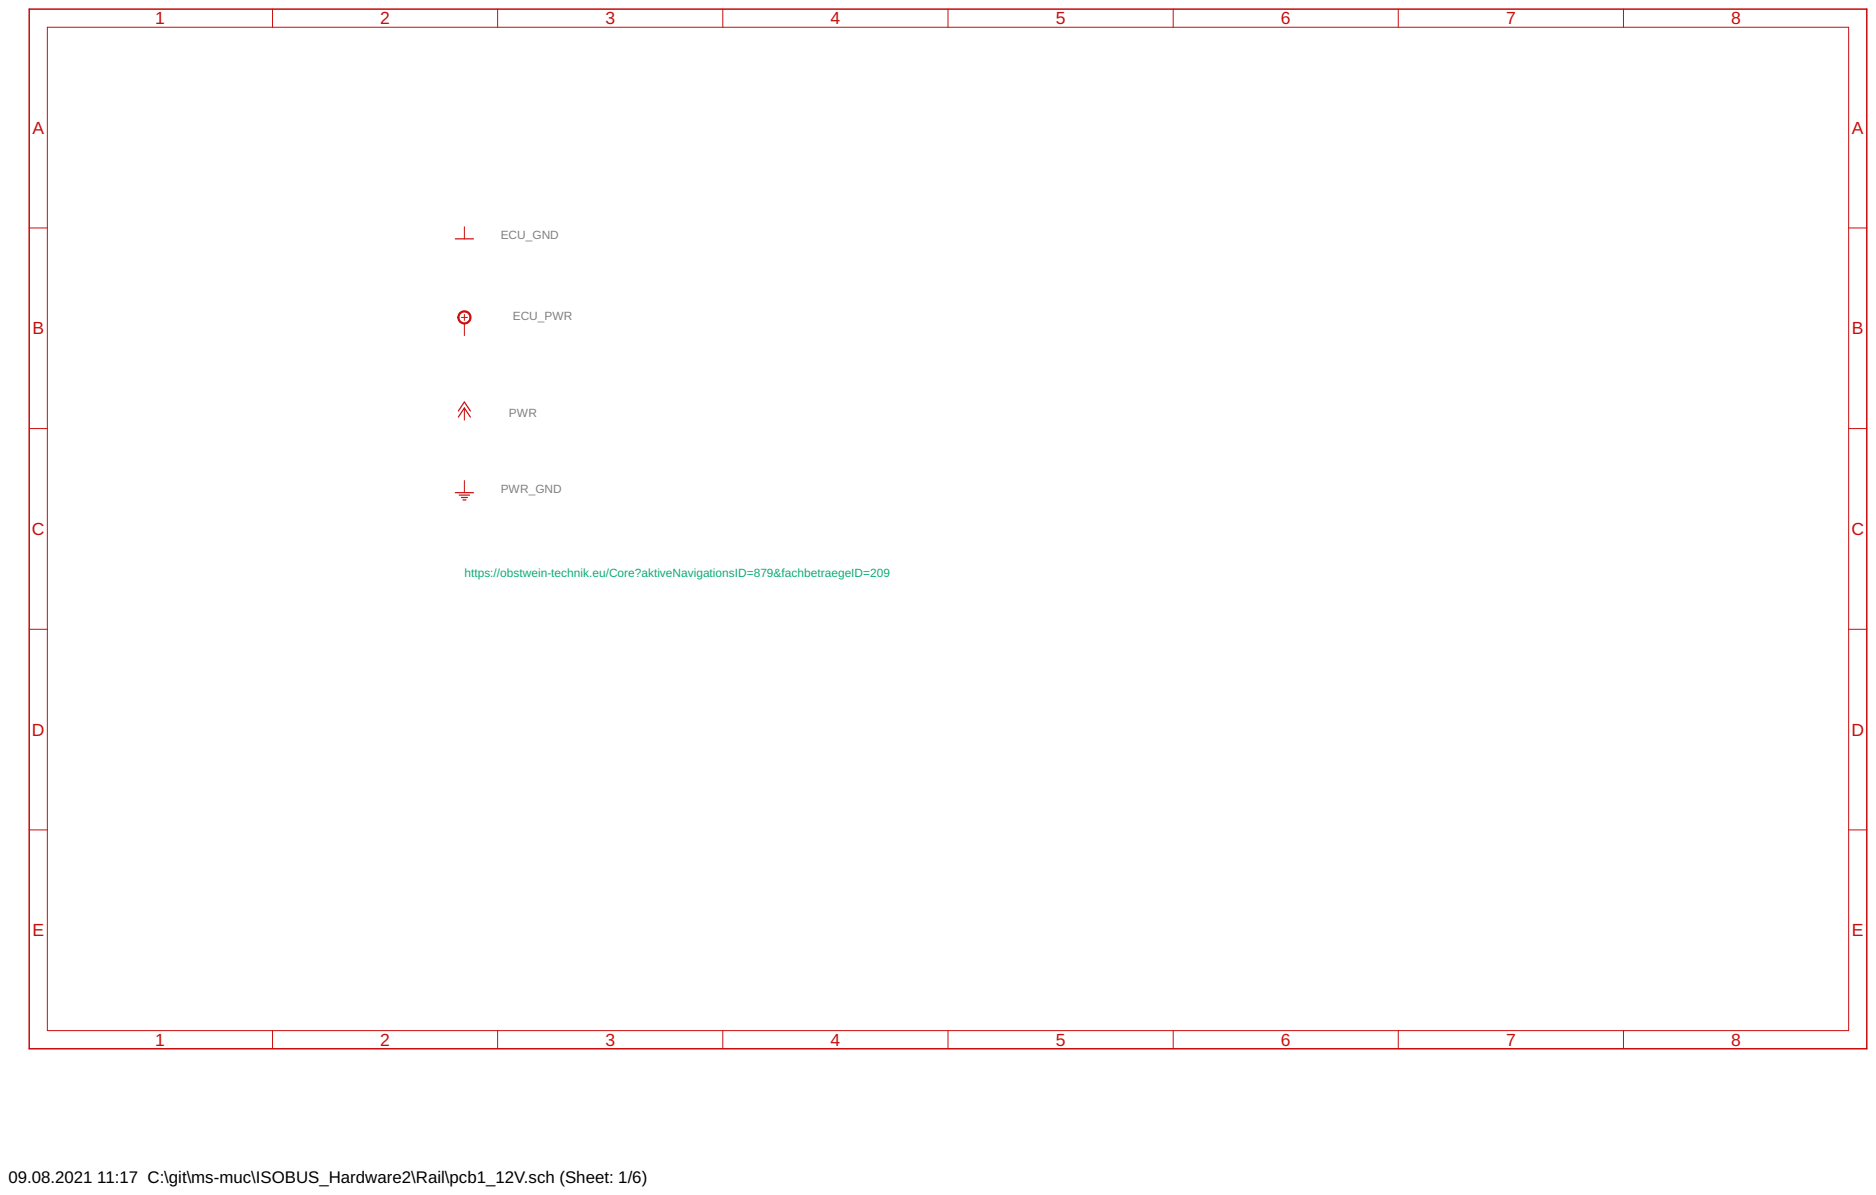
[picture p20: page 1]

https://obstwein-technik.eu/Core?aktiveNavigationsID=879&fachbetraegeID=209

09.08.2021 11:17 C:\git\ms-muc\ISOBUS_Hardware2\Rail\pcb1_12V.sch (Sheet: 1/6)

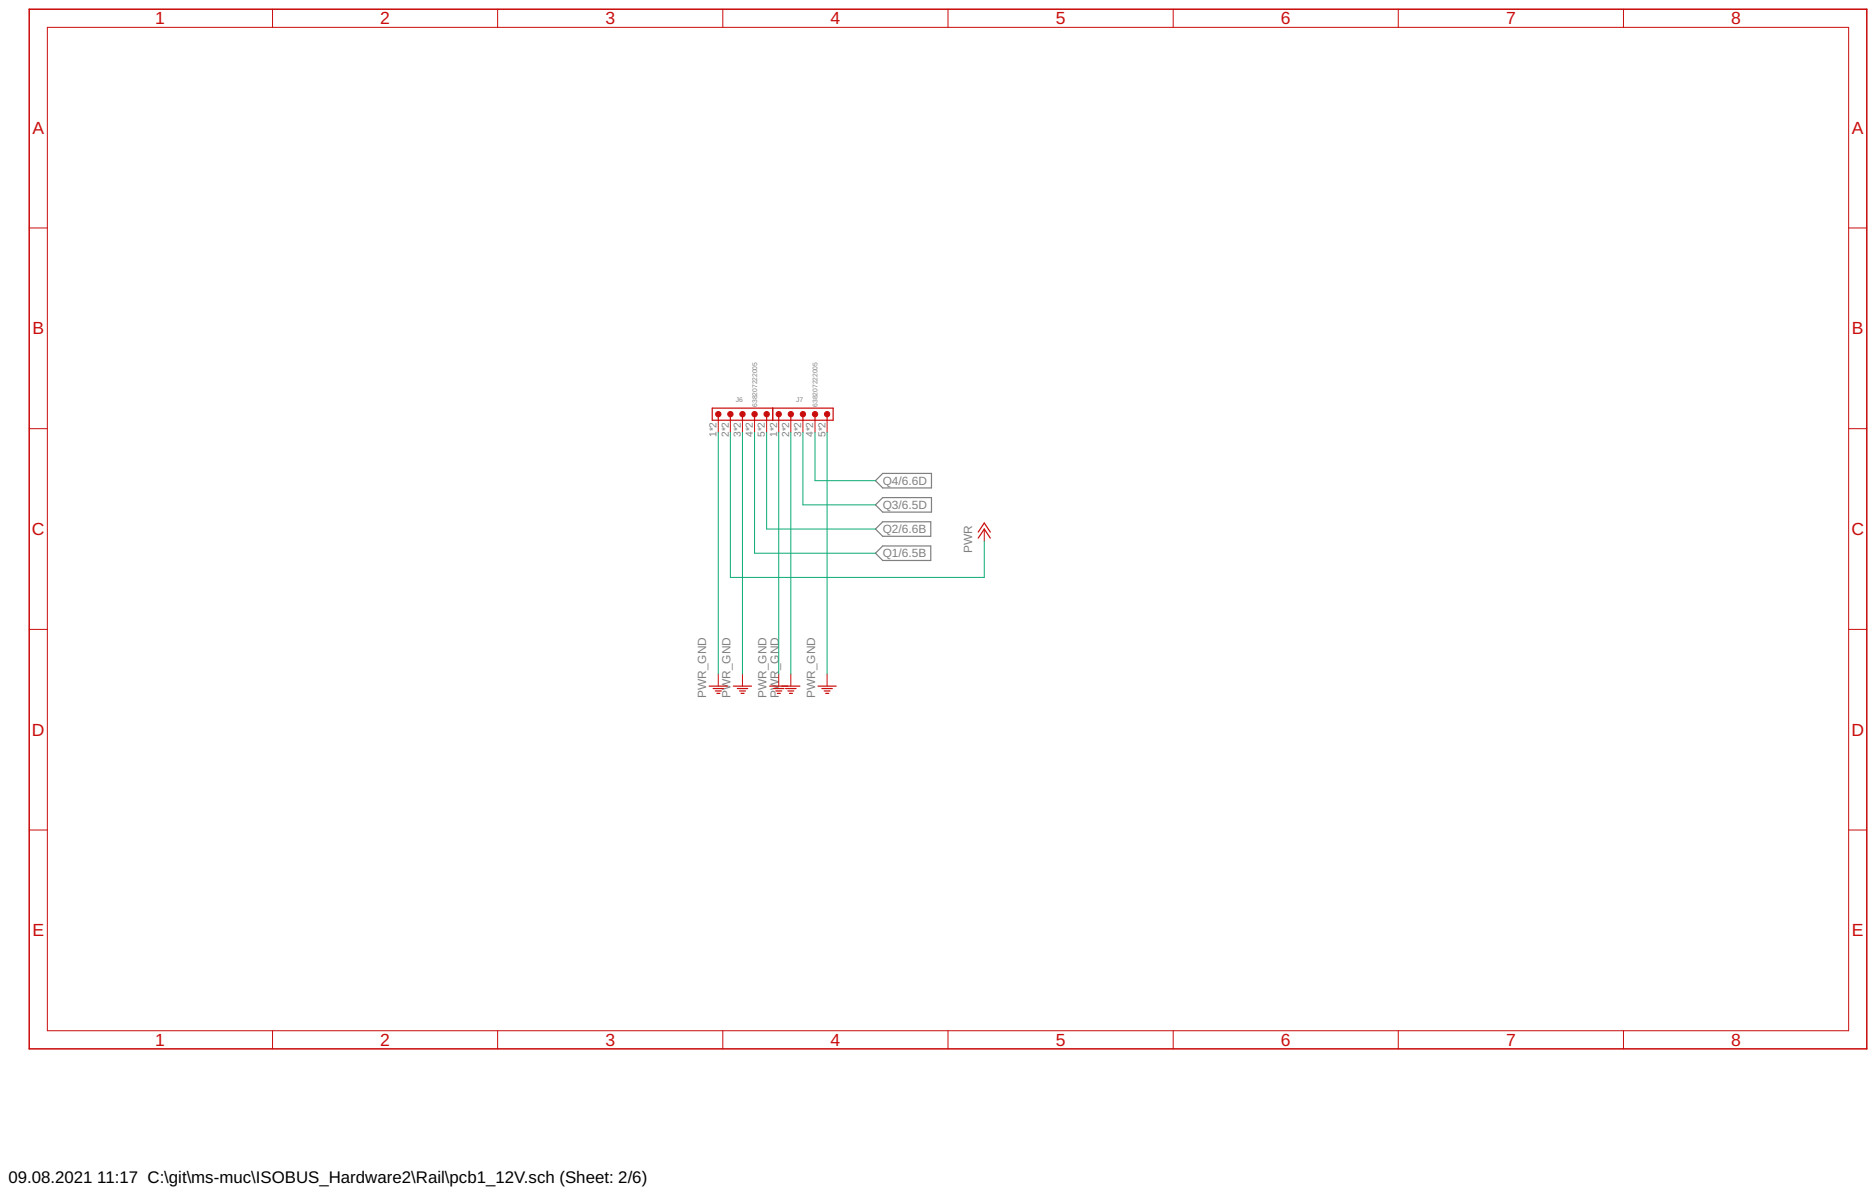
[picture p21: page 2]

09.08.2021 11:17 C:\git\ms-muc\ISOBUS_Hardware2\Rail\pcb1_12V.sch (Sheet: 2/6)

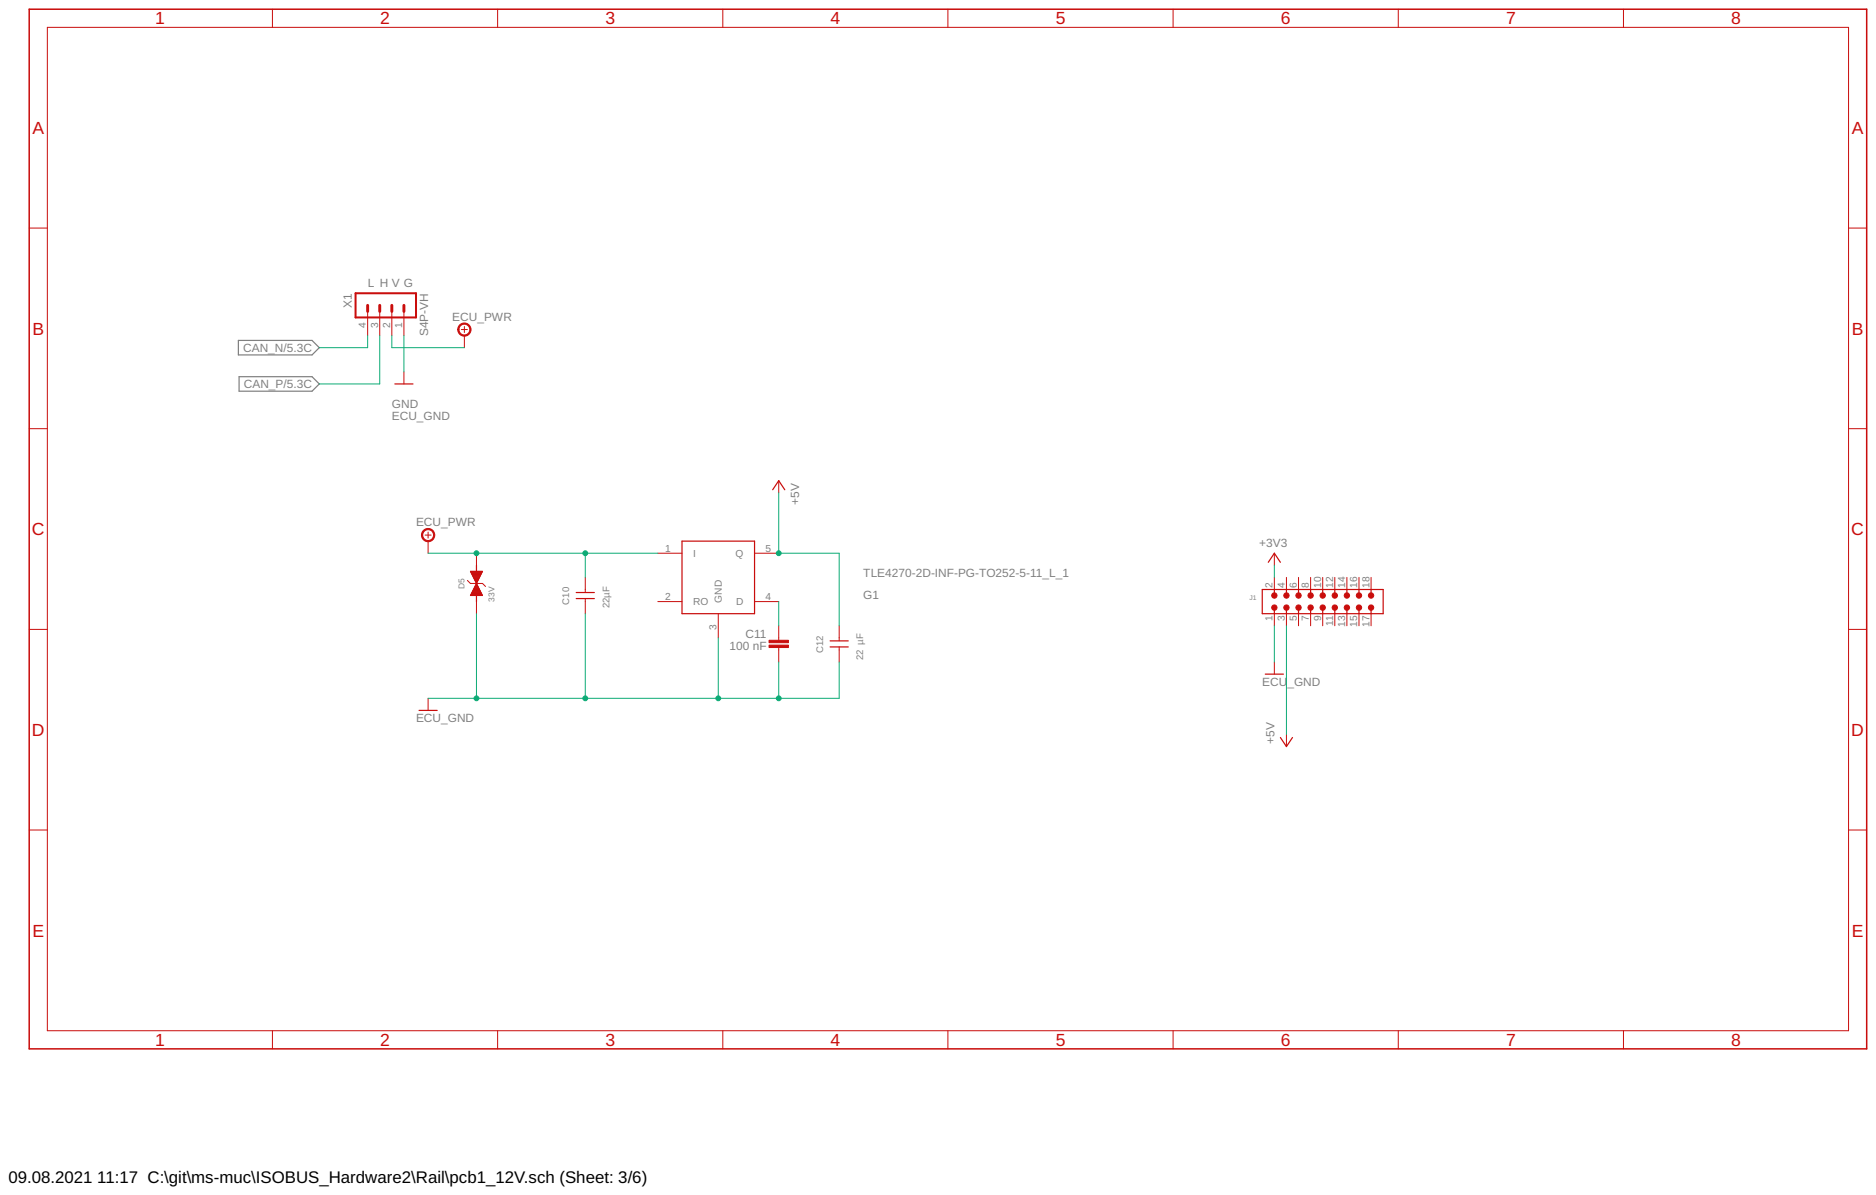
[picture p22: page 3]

09.08.2021 11:17 C:\git\ms-muc\ISOBUS_Hardware2\Rail\pcb1_12V.sch (Sheet: 3/6)

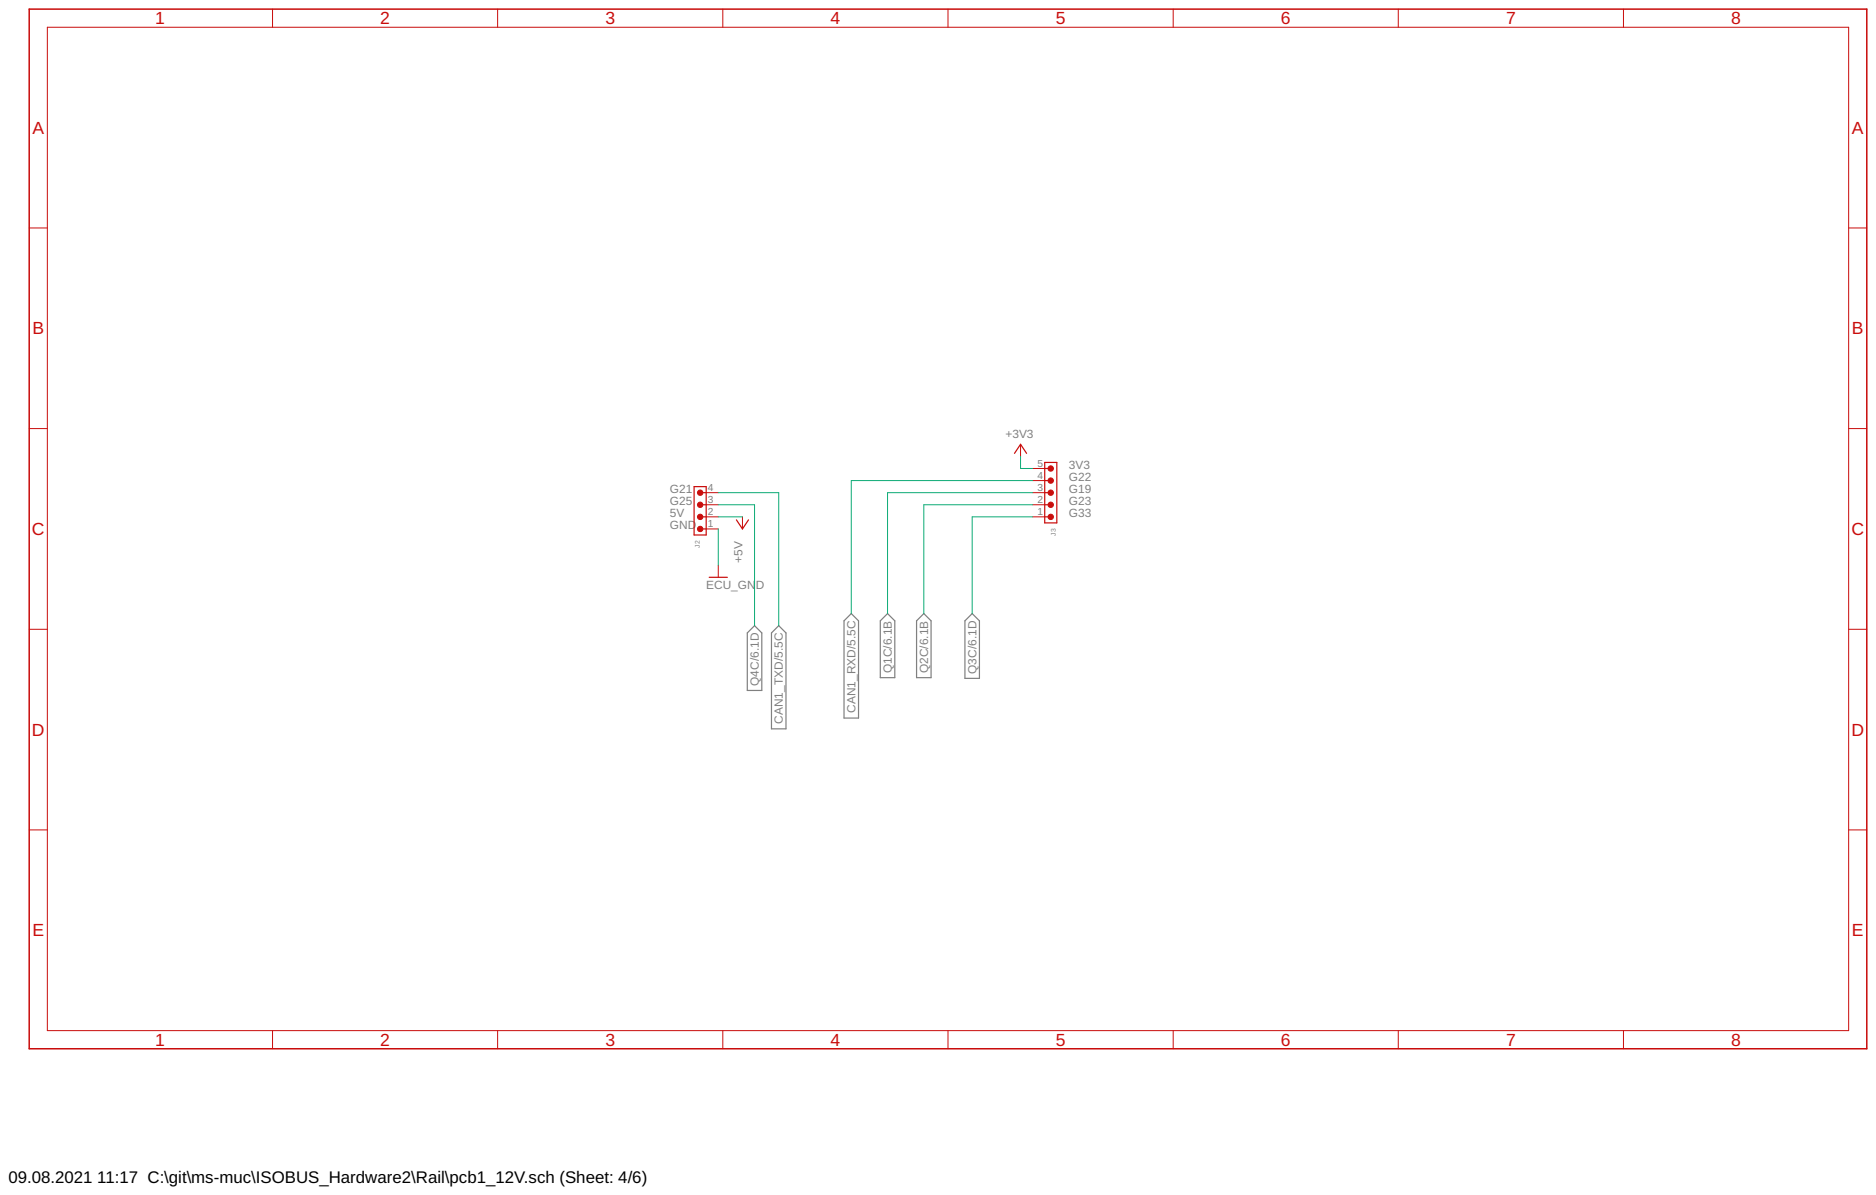
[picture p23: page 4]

09.08.2021 11:17 C:\git\ms-muc\ISOBUS_Hardware2\Rail\pcb1_12V.sch (Sheet: 4/6)

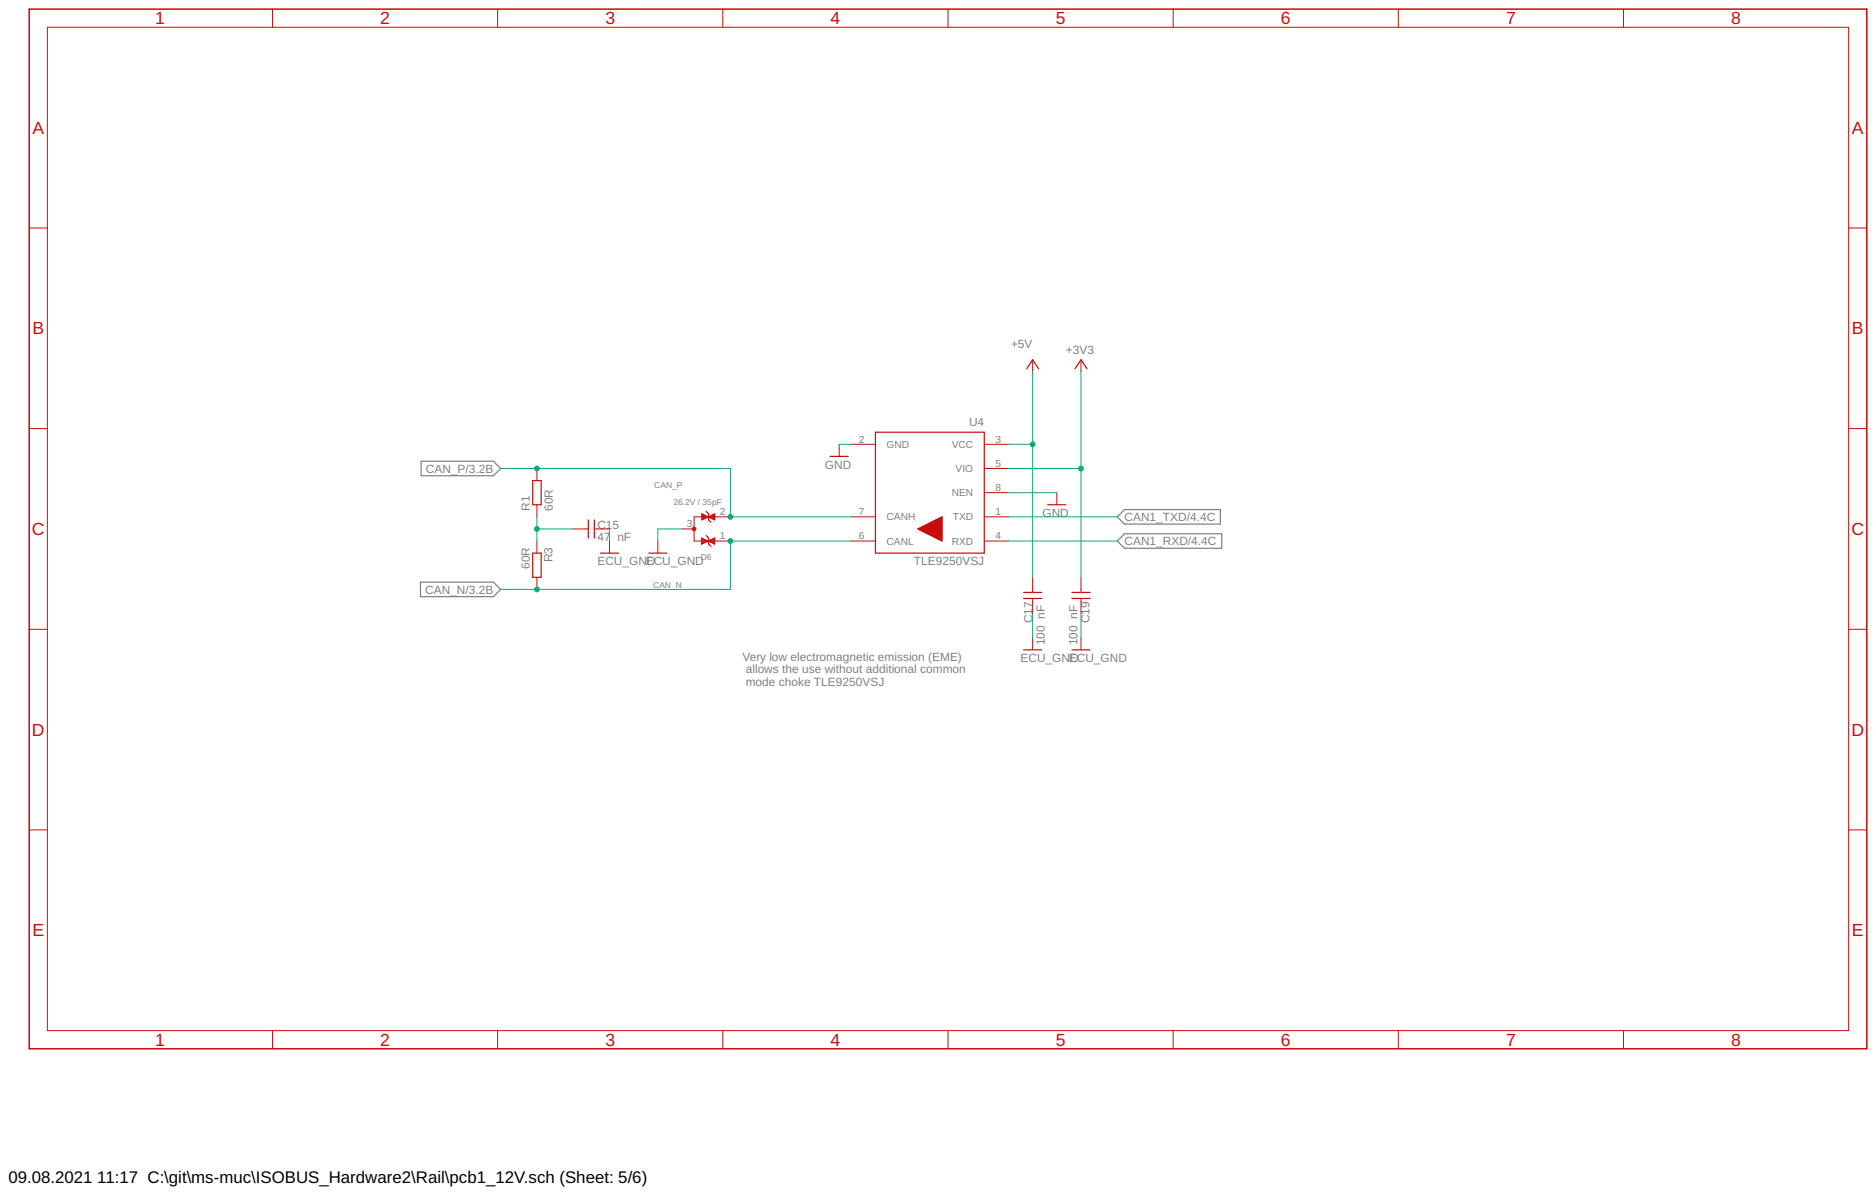
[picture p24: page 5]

Very low electromagnetic emission (EME) allows the use without additional common mode choke TLE9250VSJ

09.08.2021 11:17 C:\git\ms-muc\ISOBUS_Hardware2\Rail\pcb1_12V.sch (Sheet: 5/6)

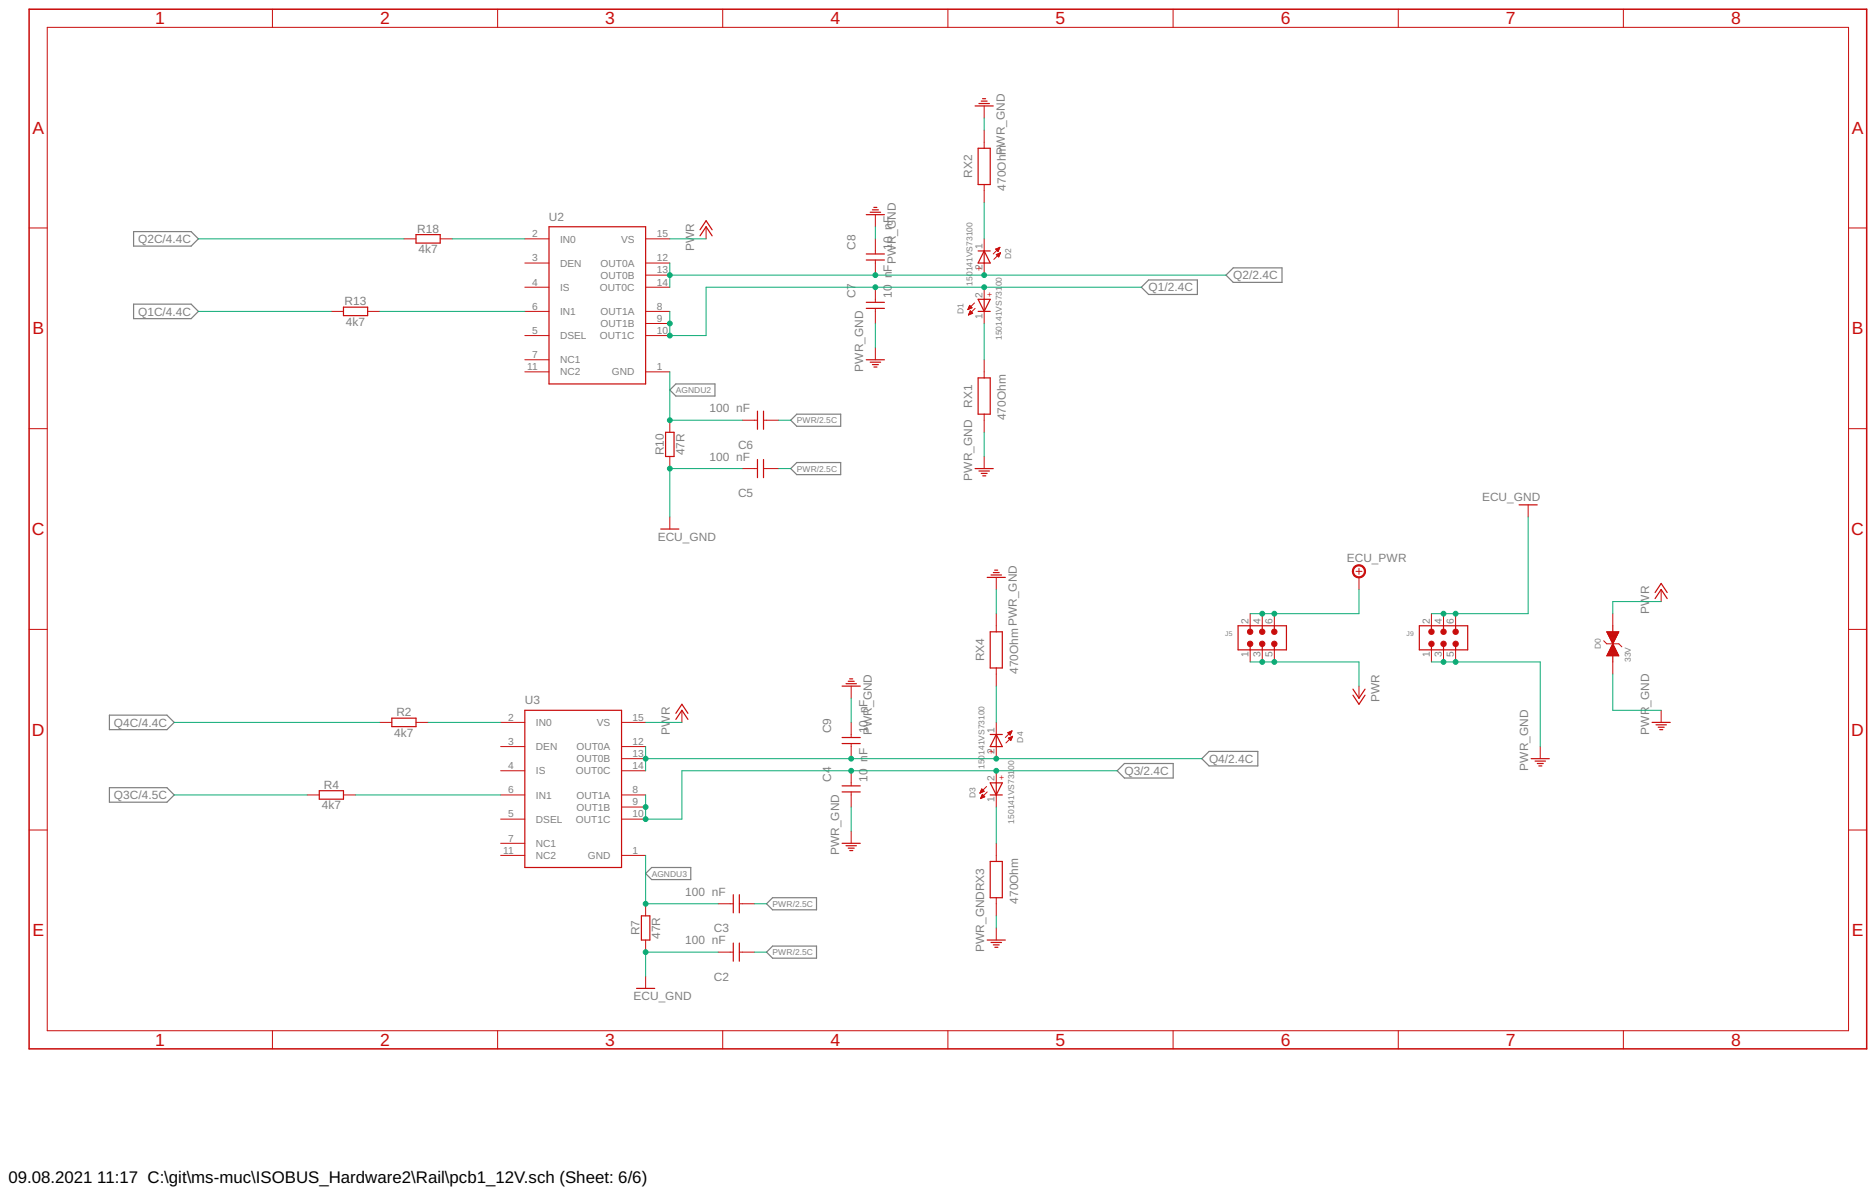
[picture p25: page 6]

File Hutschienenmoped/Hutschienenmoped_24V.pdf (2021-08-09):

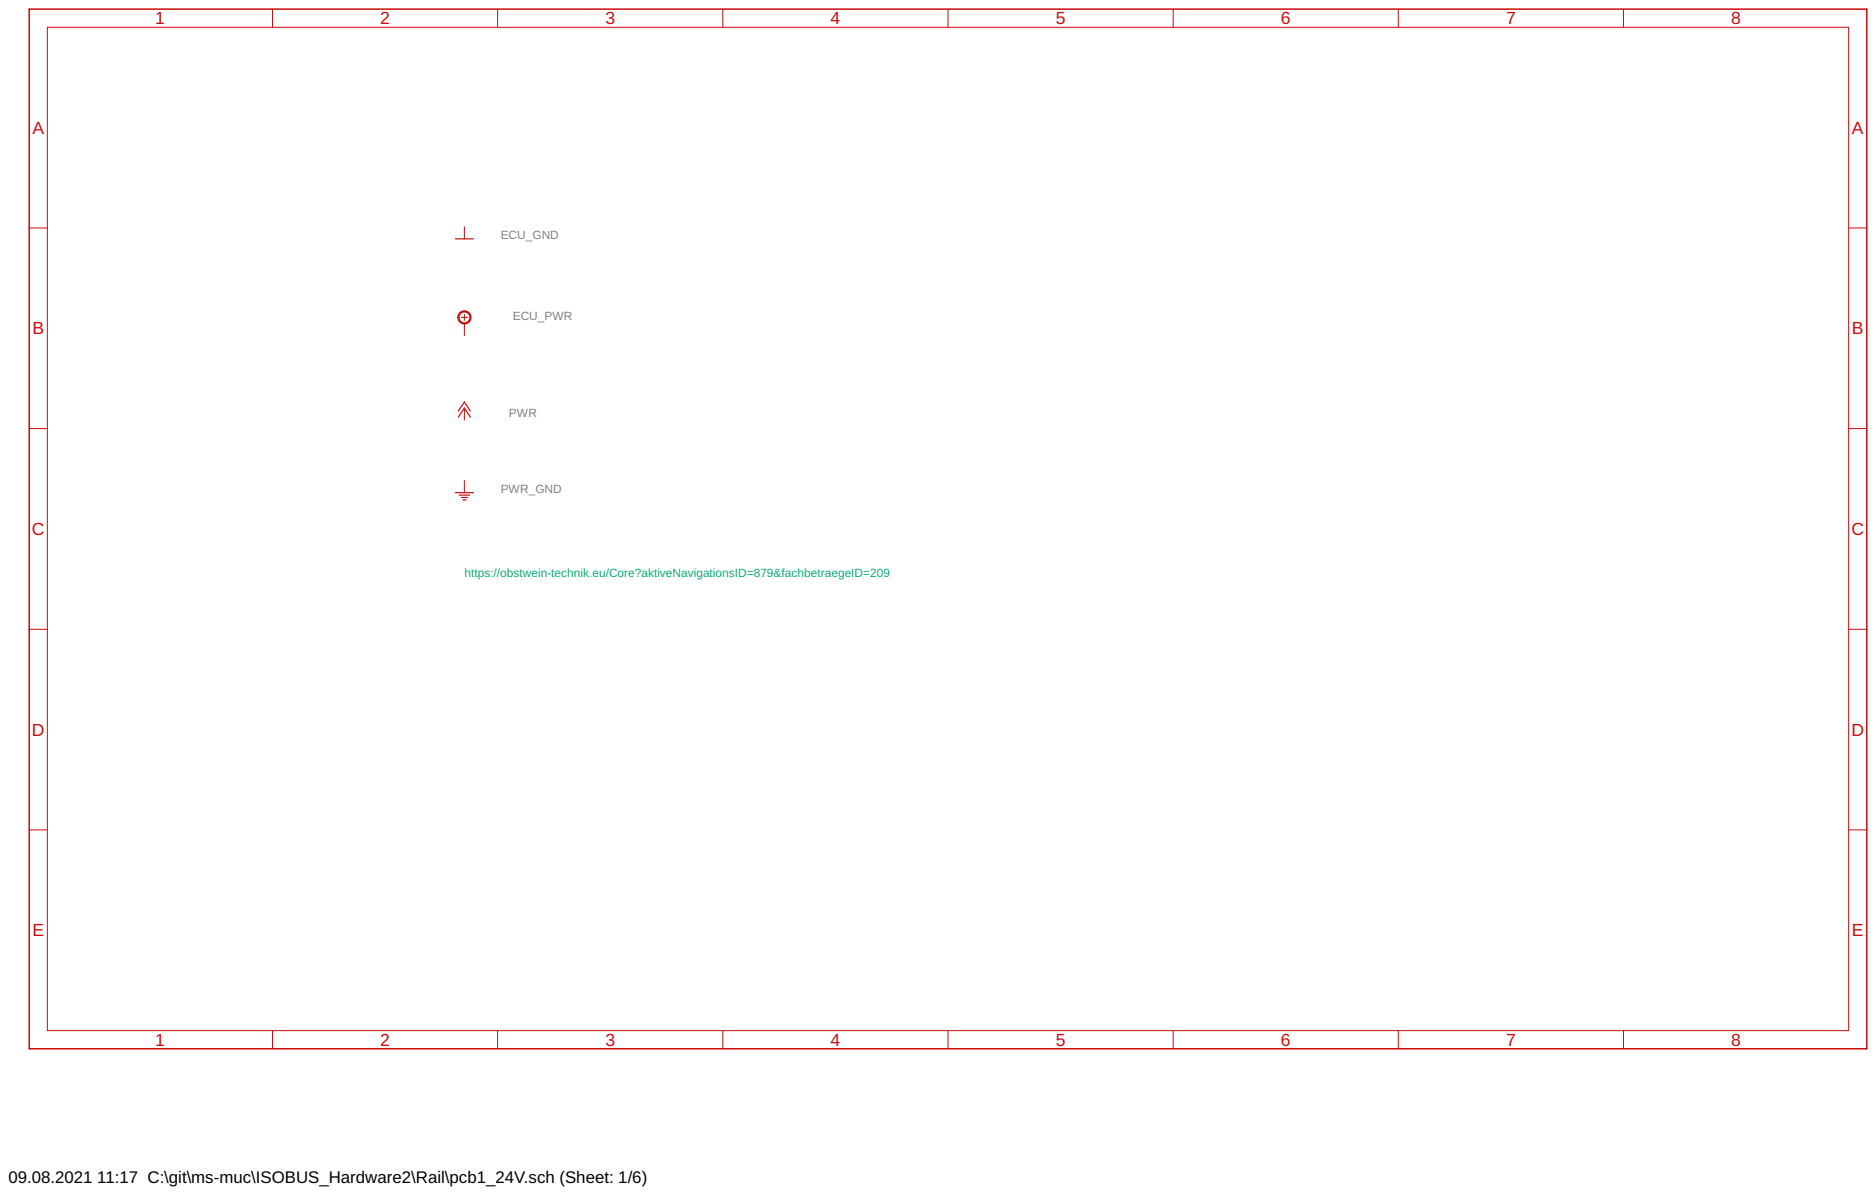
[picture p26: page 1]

https://obstwein-technik.eu/Core?aktiveNavigationsID=879&fachbetraegeID=209

09.08.2021 11:17 C:\git\ms-muc\ISOBUS_Hardware2\Rail\pcb1_24V.sch (Sheet: 1/6)

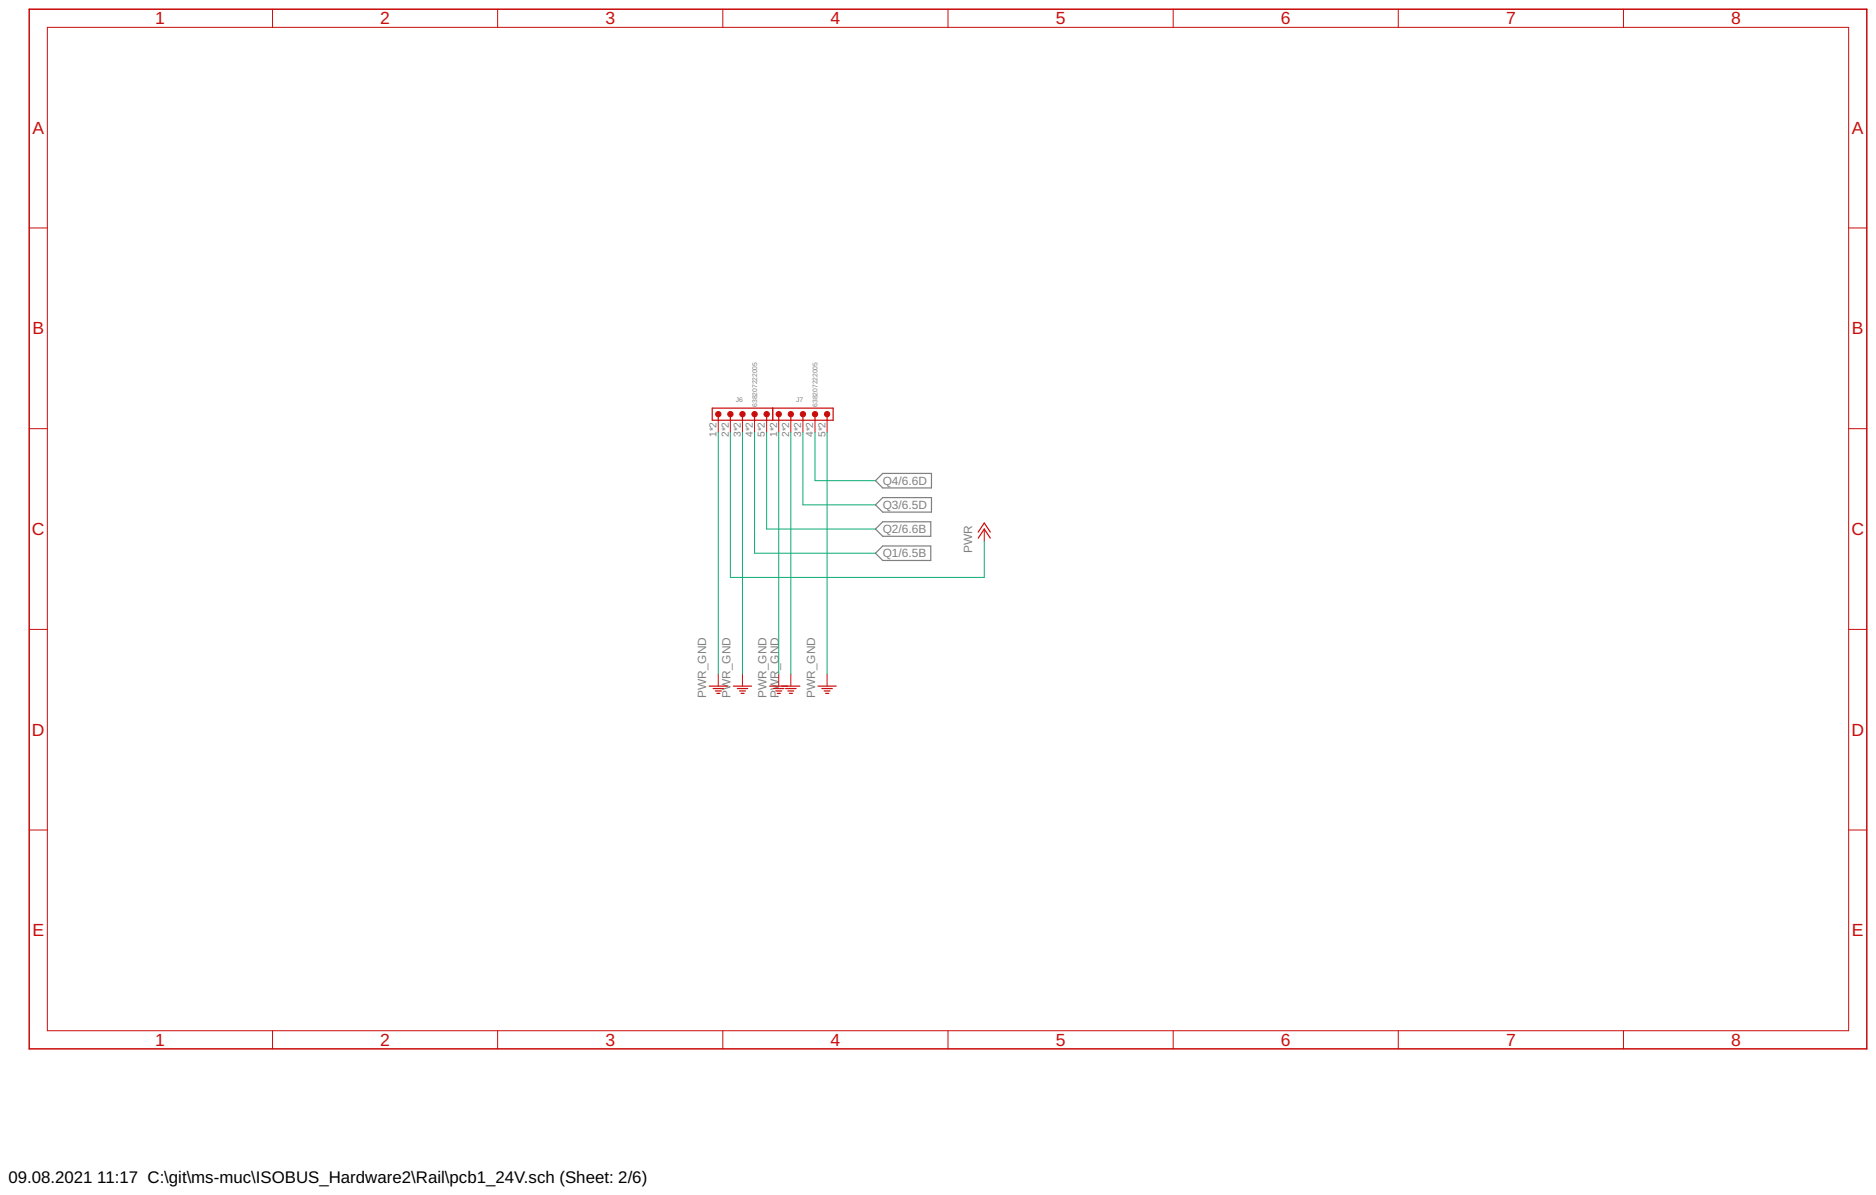
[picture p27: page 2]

09.08.2021 11:17 C:\git\ms-muc\ISOBUS_Hardware2\Rail\pcb1_24V.sch (Sheet: 2/6)

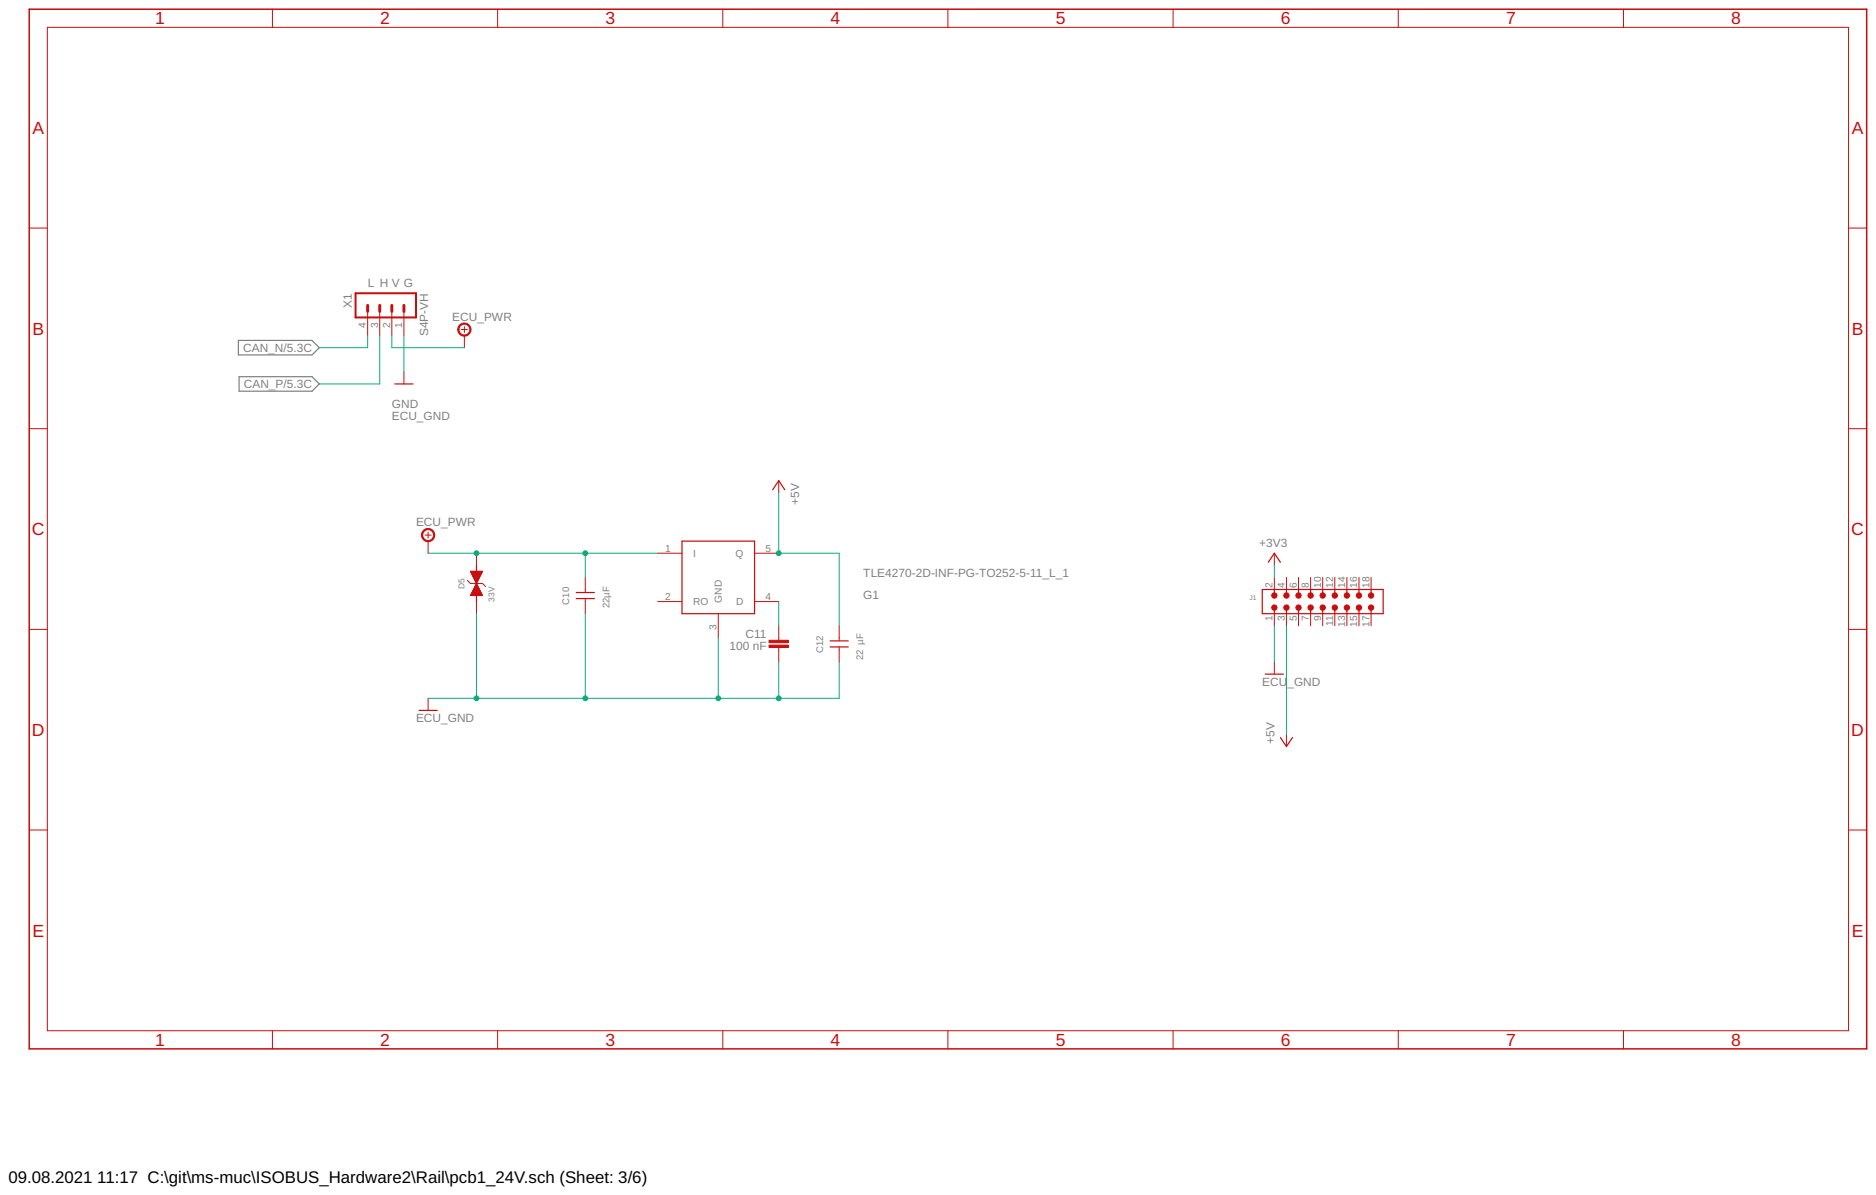
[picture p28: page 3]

09.08.2021 11:17 C:\git\ms-muc\ISOBUS_Hardware2\Rail\pcb1_24V.sch (Sheet: 3/6)

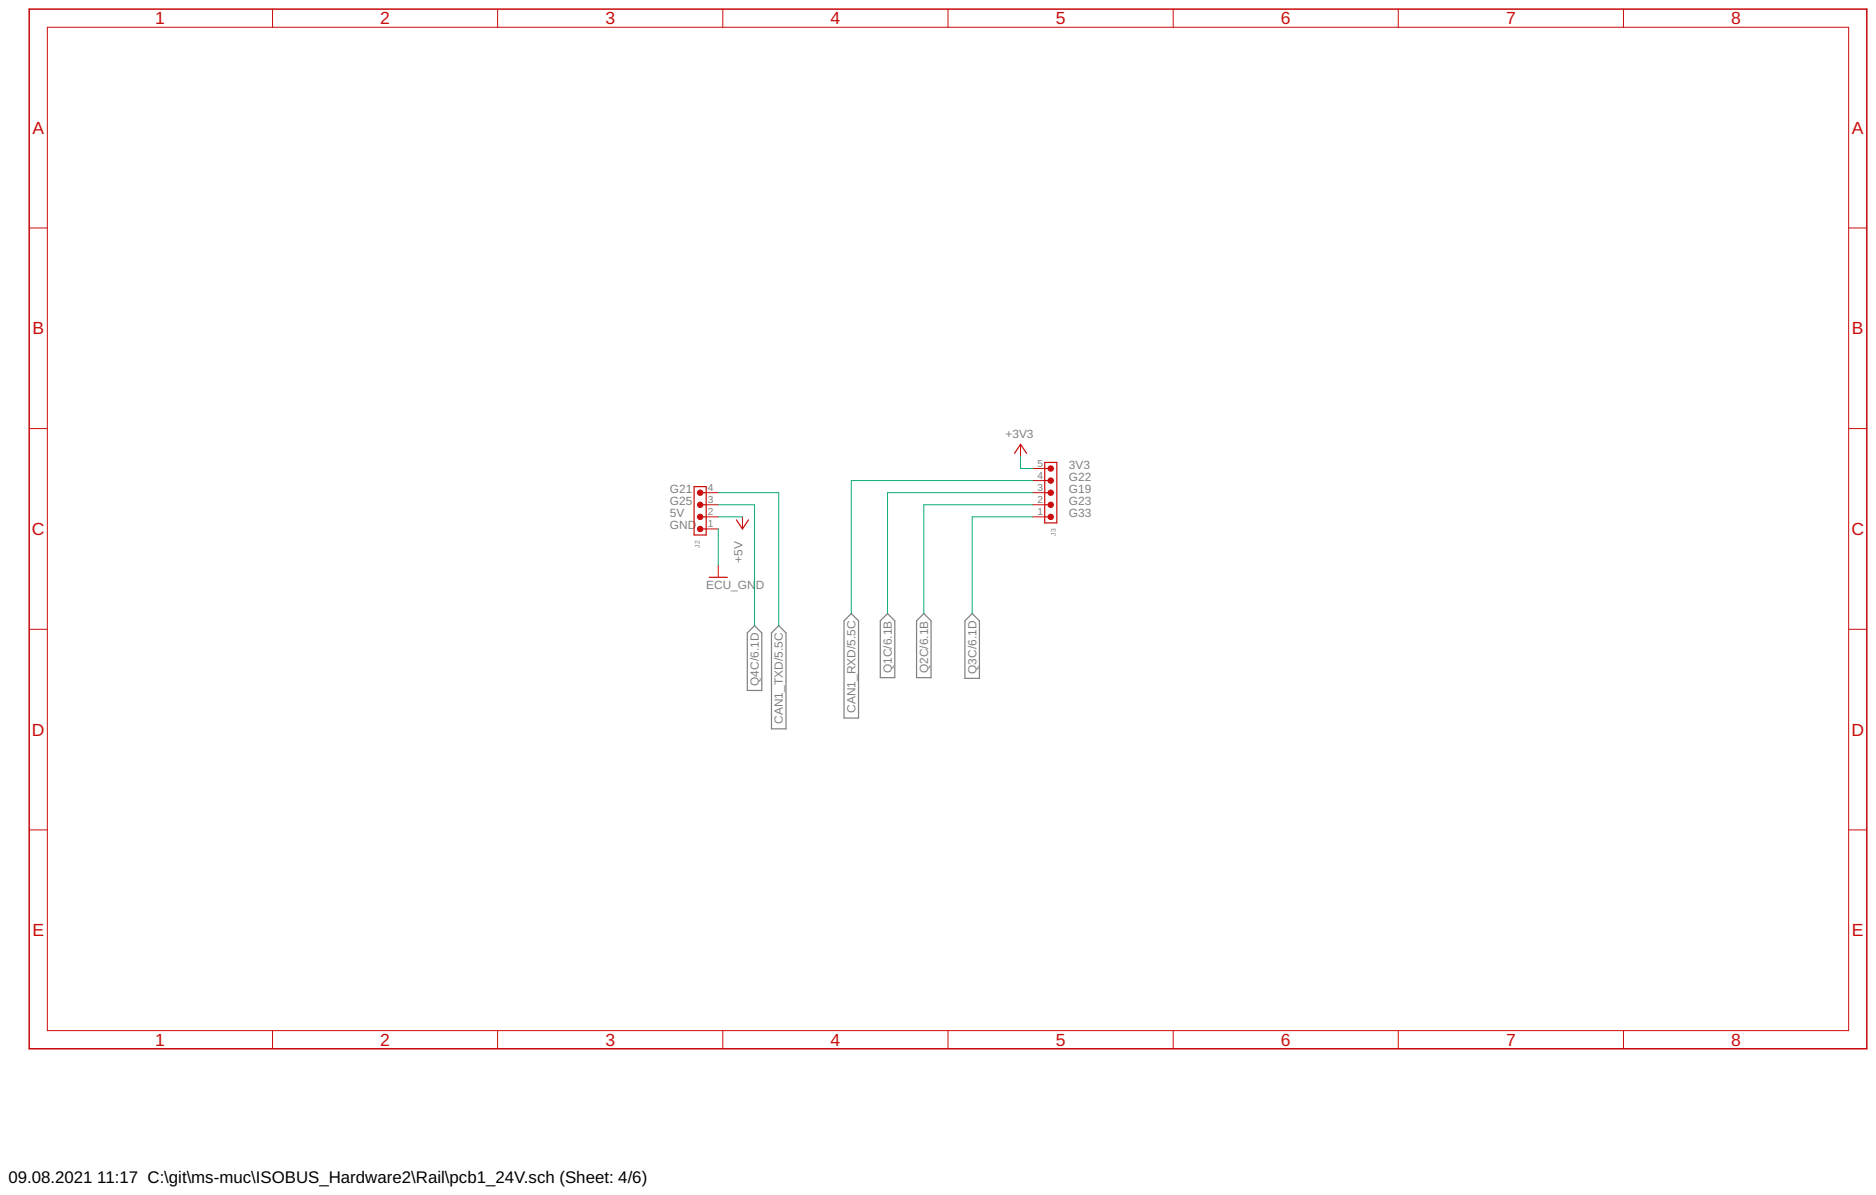
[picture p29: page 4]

09.08.2021 11:17 C:\git\ms-muc\ISOBUS_Hardware2\Rail\pcb1_24V.sch (Sheet: 4/6)

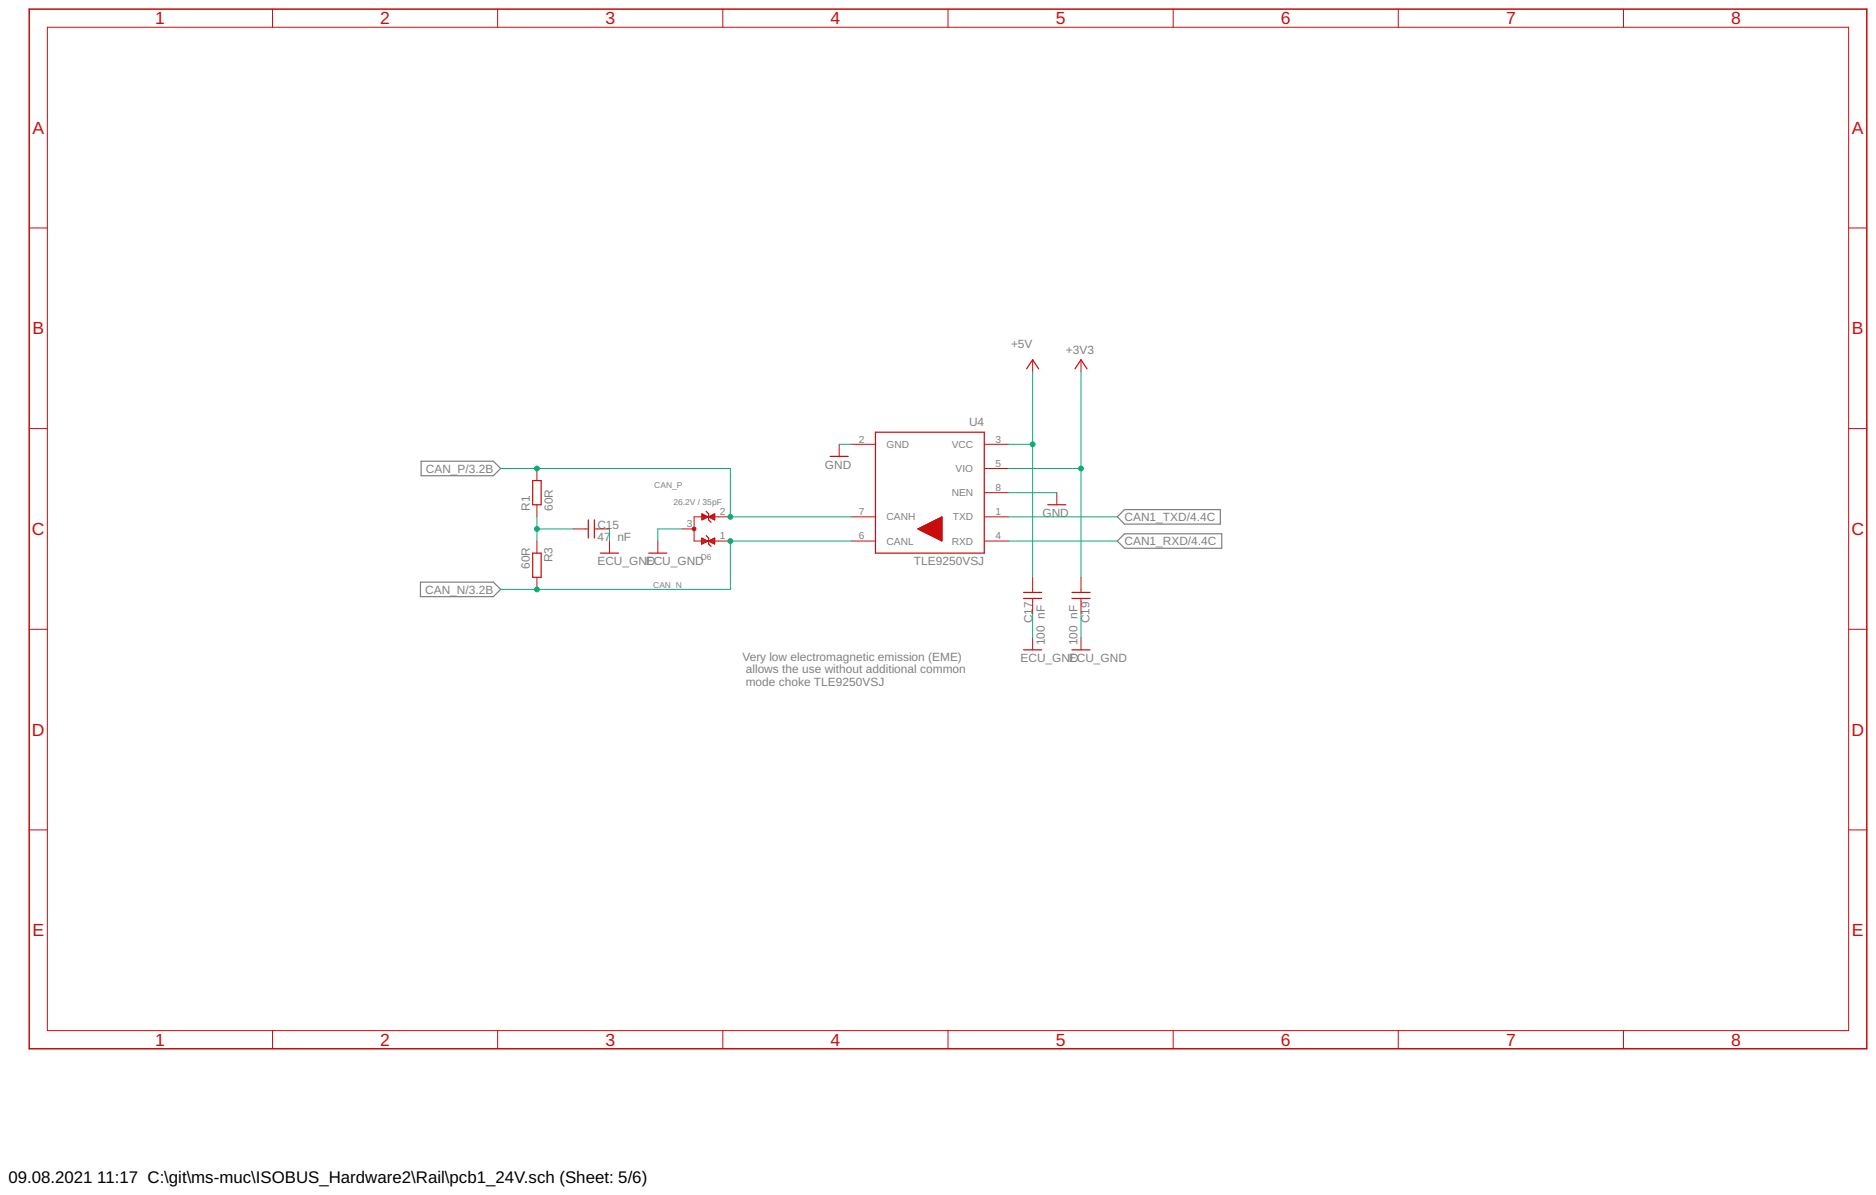
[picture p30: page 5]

Very low electromagnetic emission (EME) allows the use without additional common mode choke TLE9250VSJ

09.08.2021 11:17 C:\git\ms-muc\ISOBUS_Hardware2\Rail\pcb1_24V.sch (Sheet: 5/6)

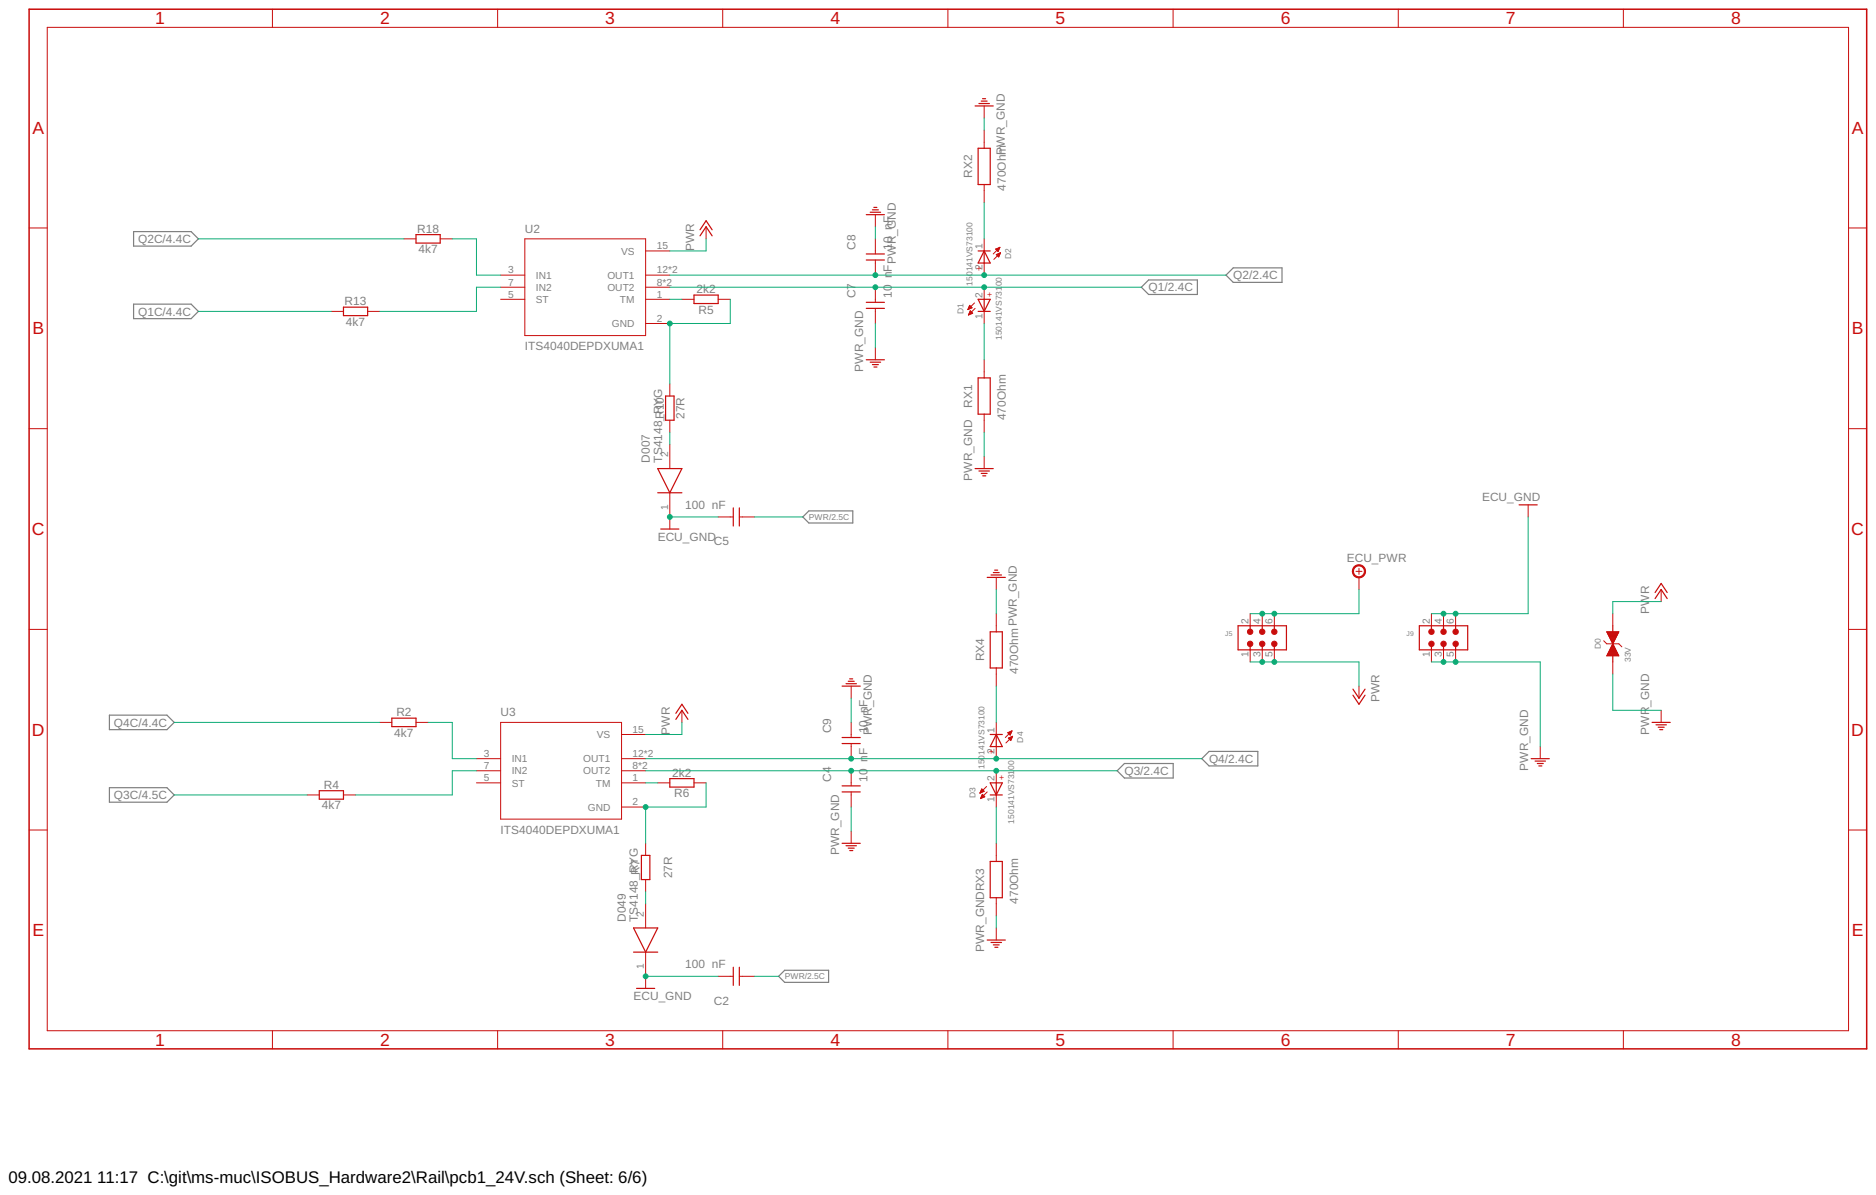
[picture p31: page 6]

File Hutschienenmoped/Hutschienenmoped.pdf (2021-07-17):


https://obstwein-technik.eu/Core?aktiveNavigationsID=879&fachbetraegeID=209

12.07.2021 12:07 C:\git\ms-muc\ISOBUS_Hardware\Rail\pcb1.sch (Sheet: 1/6)


12.07.2021 12:07 C:\git\ms-muc\ISOBUS_Hardware\Rail\pcb1.sch (Sheet: 2/6)


12.07.2021 12:07 C:\git\ms-muc\ISOBUS_Hardware\Rail\pcb1.sch (Sheet: 3/6)


12.07.2021 12:07 C:\git\ms-muc\ISOBUS_Hardware\Rail\pcb1.sch (Sheet: 4/6)


Very low electromagnetic emission (EME) allows the use without additional common mode choke TLE9250VSJ

12.07.2021 12:07 C:\git\ms-muc\ISOBUS_Hardware\Rail\pcb1.sch (Sheet: 5/6)


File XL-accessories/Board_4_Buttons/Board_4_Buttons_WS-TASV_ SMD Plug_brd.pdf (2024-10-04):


16.07.2024 15:32 c:\git\ms\ISOBUS_Hardware\XL-accessories\Board_4_Buttons\Board_4_Buttons_WS-TASV_ SMD Plug.brd

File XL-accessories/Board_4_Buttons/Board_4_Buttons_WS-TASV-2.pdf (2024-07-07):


26.03.2024 12:44 C:\git\ms\ISOBUS_Hardware\XL-accessories\Board_4_Buttons\Board_4_Buttons_WS-TASV-2.brd

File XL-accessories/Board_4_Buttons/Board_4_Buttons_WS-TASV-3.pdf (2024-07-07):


26.03.2024 12:44 C:\git\ms\ISOBUS_Hardware\XL-accessories\Board_4_Buttons\Board_4_Buttons_WS-TASV-3.brd

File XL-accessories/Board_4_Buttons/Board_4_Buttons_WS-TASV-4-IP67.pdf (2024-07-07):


26.03.2024 12:44 C:\git\ms\ISOBUS_Hardware\XL-accessories\Board_4_Buttons\Board_4_Buttons_WS-TASV-4-IP67.brd

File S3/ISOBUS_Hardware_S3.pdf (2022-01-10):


26.11.2021 11:03 C:\git\ms-muc\ISOBUS_Hardware\S3\ISOBUS_Hardware_S3.sch (Sheet: 1/5)


26.11.2021 11:03 C:\git\ms-muc\ISOBUS_Hardware\S3\ISOBUS_Hardware_S3.sch (Sheet: 2/5)


26.11.2021 11:03 C:\git\ms-muc\ISOBUS_Hardware\S3\ISOBUS_Hardware_S3.sch (Sheet: 3/5)


26.11.2021 11:03 C:\git\ms-muc\ISOBUS_Hardware\S3\ISOBUS_Hardware_S3.sch (Sheet: 4/5)


26.11.2021 11:03 C:\git\ms-muc\ISOBUS_Hardware\S3\ISOBUS_Hardware_S3.sch (Sheet: 5/5)

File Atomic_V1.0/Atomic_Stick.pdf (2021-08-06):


06.08.2021 09:49 C:\git\ms-muc\ISOBUS_Hardware\Atomic_V1.0\Atomic_Stick.sch (Sheet: 1/3)


06.08.2021 09:49 C:\git\ms-muc\ISOBUS_Hardware\Atomic_V1.0\Atomic_Stick.sch (Sheet: 2/3)


pas 1 pas 1

Very low electromagnetic emission (EME) allows the use without additional common mode choke TLE9250VSJ

06.08.2021 09:49 C:\git\ms-muc\ISOBUS_Hardware\Atomic_V1.0\Atomic_Stick.sch (Sheet: 3/3)

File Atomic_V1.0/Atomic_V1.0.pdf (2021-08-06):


06.08.2021 09:43 C:\git\ms-muc\ISOBUS_Hardware\Atomic_V1.0\Atomic_V1.0.sch (Sheet: 1/3)


06.08.2021 09:43 C:\git\ms-muc\ISOBUS_Hardware\Atomic_V1.0\Atomic_V1.0.sch (Sheet: 2/3)


Very low electromagnetic emission (EME) allows the use without additional common mode choke TLE9250VSJ

06.08.2021 09:43 C:\git\ms-muc\ISOBUS_Hardware\Atomic_V1.0\Atomic_V1.0.sch (Sheet: 3/3)

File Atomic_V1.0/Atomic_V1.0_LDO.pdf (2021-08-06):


06.08.2021 09:44 C:\git\ms-muc\ISOBUS_Hardware\Atomic_V1.0\Atomic_V1.0_LDO.sch (Sheet: 1/3)


06.08.2021 09:44 C:\git\ms-muc\ISOBUS_Hardware\Atomic_V1.0\Atomic_V1.0_LDO.sch (Sheet: 2/3)


pas 1 pas 1

Very low electromagnetic emission (EME) allows the use without additional common mode choke TLE9250VSJ

06.08.2021 09:44 C:\git\ms-muc\ISOBUS_Hardware\Atomic_V1.0\Atomic_V1.0_LDO.sch (Sheet: 3/3)


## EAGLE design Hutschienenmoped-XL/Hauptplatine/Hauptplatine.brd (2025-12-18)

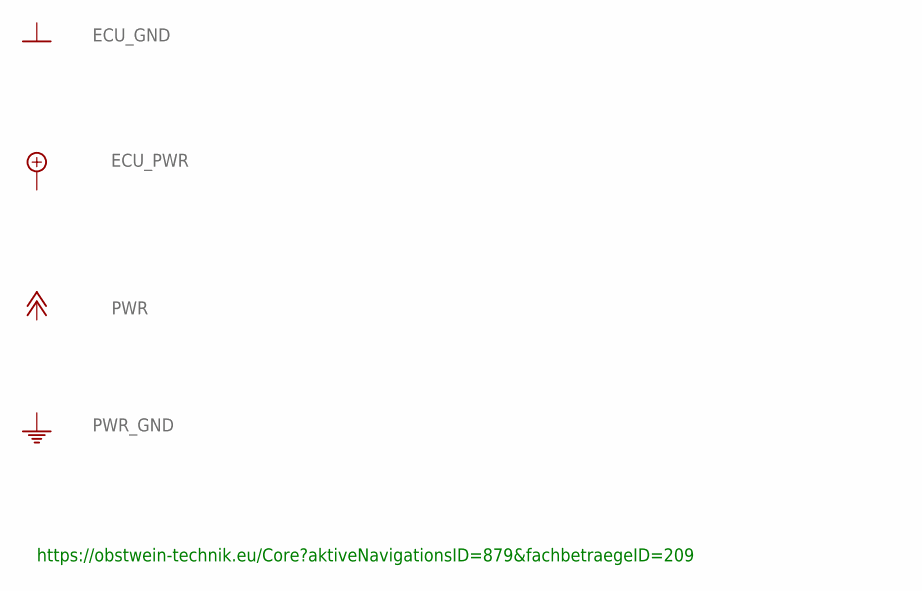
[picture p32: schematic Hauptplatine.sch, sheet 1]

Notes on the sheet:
https://obstwein-technik.eu/Core?aktiveNavigationsID=879&fachbetraegeID=209

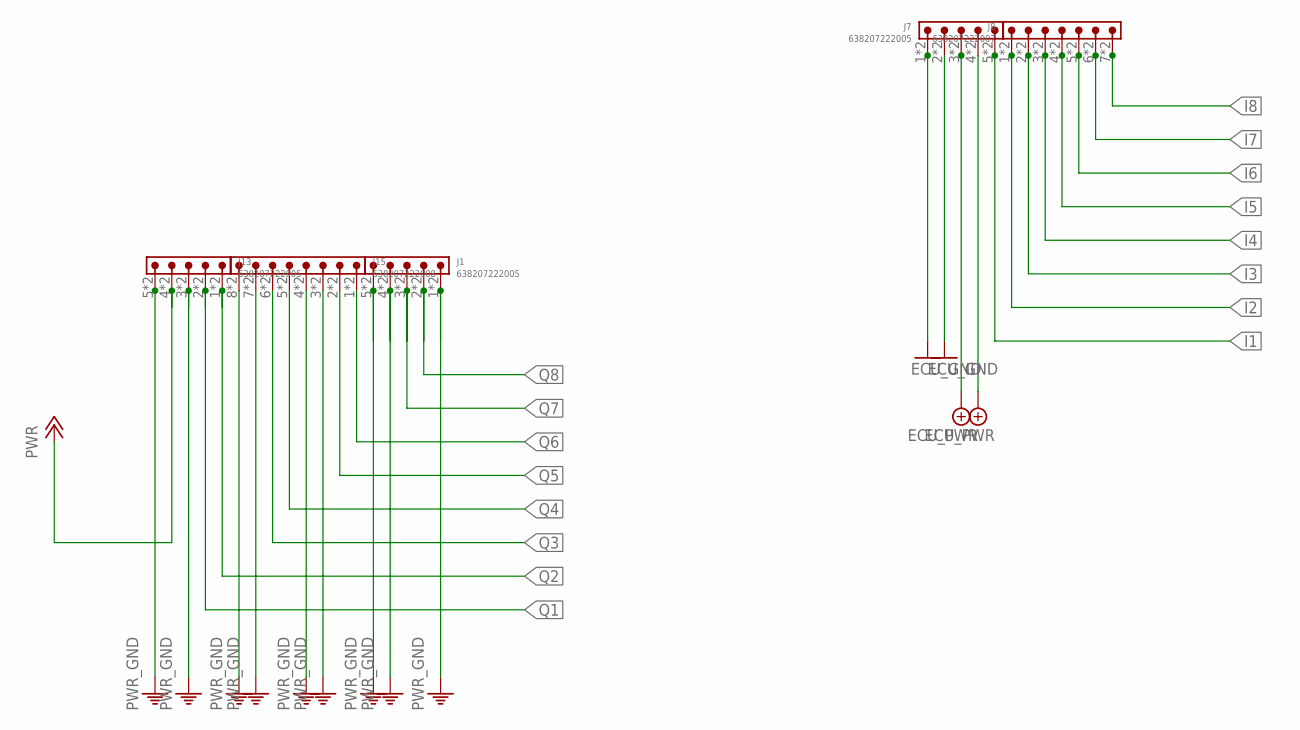
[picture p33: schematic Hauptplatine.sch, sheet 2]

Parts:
J1, J7, J13: 638207222005
J8: 638207222007
J15: 638207222008

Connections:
ECU_GND: J7.1, J7.2, J7.A1 (1), J7.A2 (2); also elsewhere on the board
ECU_PWR: J7.3, J7.4, J7.A3 (3), J7.A4 (4); also elsewhere on the board
I1: J7.5, J7.A5 (5); also elsewhere on the board
I2: J8.1, J8.A1 (1); also elsewhere on the board
I3: J8.2, J8.A2 (2); also elsewhere on the board
I4: J8.3, J8.A3 (3); also elsewhere on the board
I5: J8.4, J8.A4 (4); also elsewhere on the board
I6: J8.5, J8.A5 (5); also elsewhere on the board
I7: J8.6, J8.A6 (6); also elsewhere on the board
I8: J8.7, J8.A7 (7); also elsewhere on the board
PWR: J13.4, J13.A4 (4); also elsewhere on the board
PWR_GND: J1.1, J1.4, J1.5, J1.A1 (1), J1.A4 (4), J1.A5 (5), J13.3, J13.5, J13.A3 (3), J13.A5 (5), J15.3, J15.4, J15.7, J15.8, J15.A3 (3), J15.A4 (4), J15.A7 (7), J15.A8 (8); also elsewhere on the board
Q1: J13.2, J13.A2 (2); also elsewhere on the board
Q2: J13.1, J13.A1 (1); also elsewhere on the board
Q3: J15.6, J15.A6 (6); also elsewhere on the board
Q4: J15.5, J15.A5 (5); also elsewhere on the board
Q5: J15.2, J15.A2 (2); also elsewhere on the board
Q6: J15.1, J15.A1 (1); also elsewhere on the board
Q7: J1.3, J1.A3 (3); also elsewhere on the board
Q8: J1.2, J1.A2 (2); also elsewhere on the board

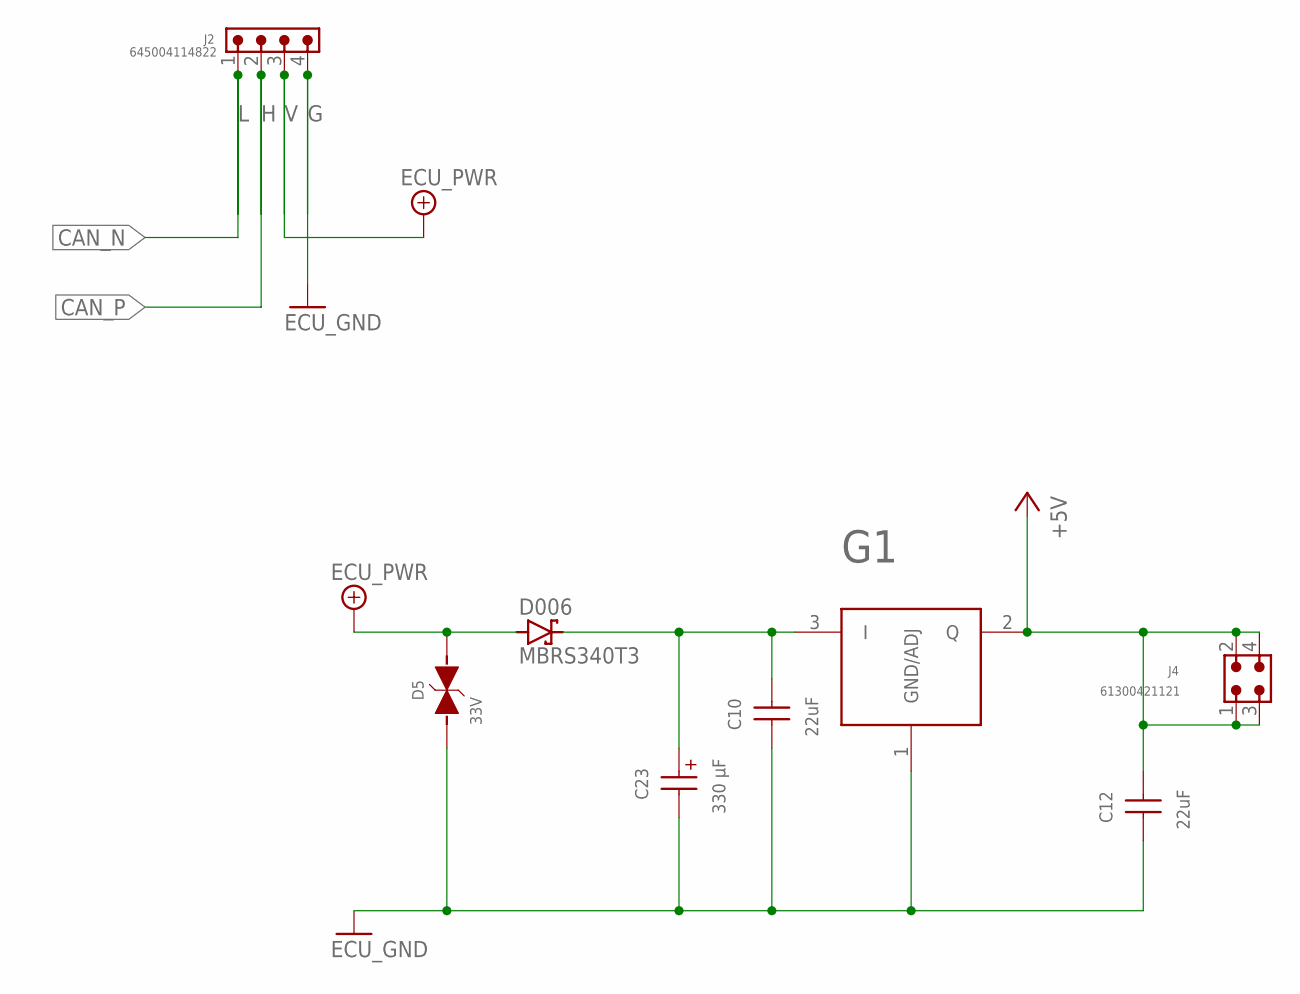
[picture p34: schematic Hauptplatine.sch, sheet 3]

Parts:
C10: 22uF; WCAP-CSGP_1210_H2.5
C12: 22uF; WCAP-CSGP_0805_H1.25_R
C23: 330 µF; WCAP-ASLI_12.5X14(DXL)
D5: 33V; WE-TVSP_DO-214AB_BIDIRECTIONAL
D006: MBRS340T3; SMC
G1: IFX27001TF_V50; INF-PG-TO252-3-11_N
J2: 645004114822
J4: 61300421121

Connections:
+5V: C12.2, G1.2 (Q), J4.1, J4.2, J4.3, J4.4; also elsewhere on the board
CAN_N: J2.1; also elsewhere on the board
CAN_P: J2.2; also elsewhere on the board
ECU_GND: C10.1, C12.1, C23.2 (-), D5.1, G1.1 (GND/ADJ), J2.4; also elsewhere on the board
ECU_PWR: D5.2, D006.A, J2.3; also elsewhere on the board
unnamed: C10.2, C23.1 (+), D006.C, G1.3 (I)

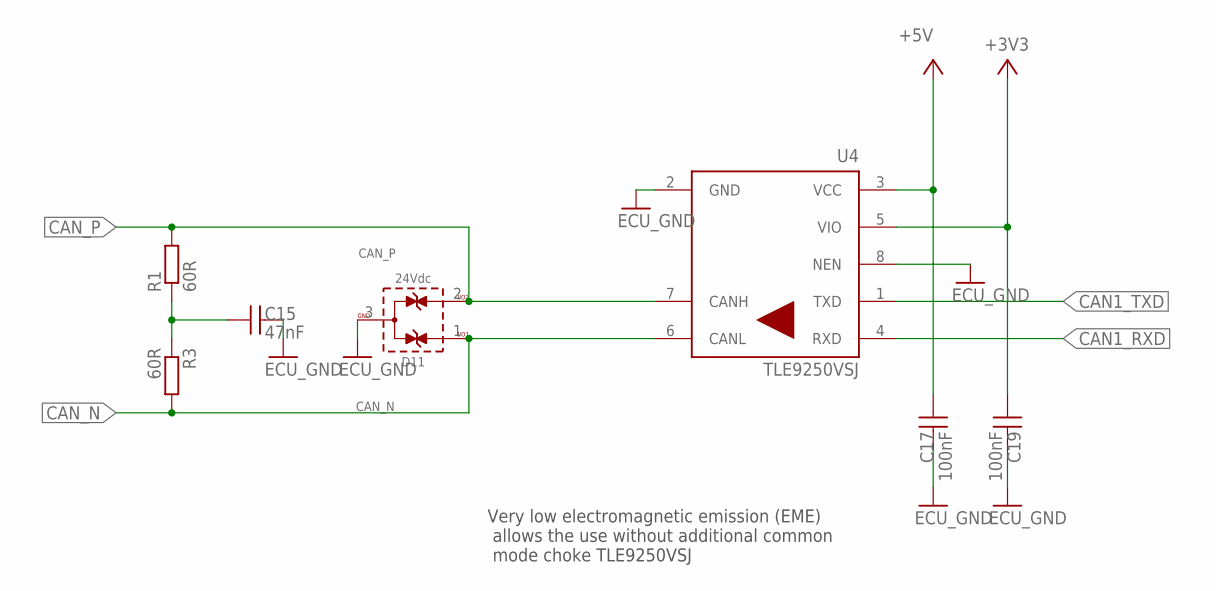
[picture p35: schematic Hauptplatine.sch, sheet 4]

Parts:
C15: 47nF; WCAP-CSGP_0805_H0.8_R
C17, C19: 100nF; WCAP-CSGP_0805_H0.8_R
D11: 24Vdc; WE-TVS_SOT23-3L
R1, R3: 60R; R0805
U4: TLE9250VSJ; SOIC127P602X173-8N-V

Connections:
+3V3: C19.1, U4.5 (VIO); also elsewhere on the board
+5V: C17.1, U4.3 (VCC); also elsewhere on the board
CAN1_RXD: U4.4 (RXD); also elsewhere on the board
CAN1_TXD: U4.1 (TXD); also elsewhere on the board
CAN_N: D11.1 (I/O1), R3.2, U4.6 (CANL); also elsewhere on the board
CAN_P: D11.2 (I/O2), R1.2, U4.7 (CANH); also elsewhere on the board
ECU_GND: C15.2, C17.2, C19.2, D11.3 (GND), U4.2 (GND), U4.8 (NEN); also elsewhere on the board
unnamed: C15.1, R1.1, R3.1

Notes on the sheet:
Very low electromagnetic emission (EME) allows the use without additional common mode choke TLE9250VSJ

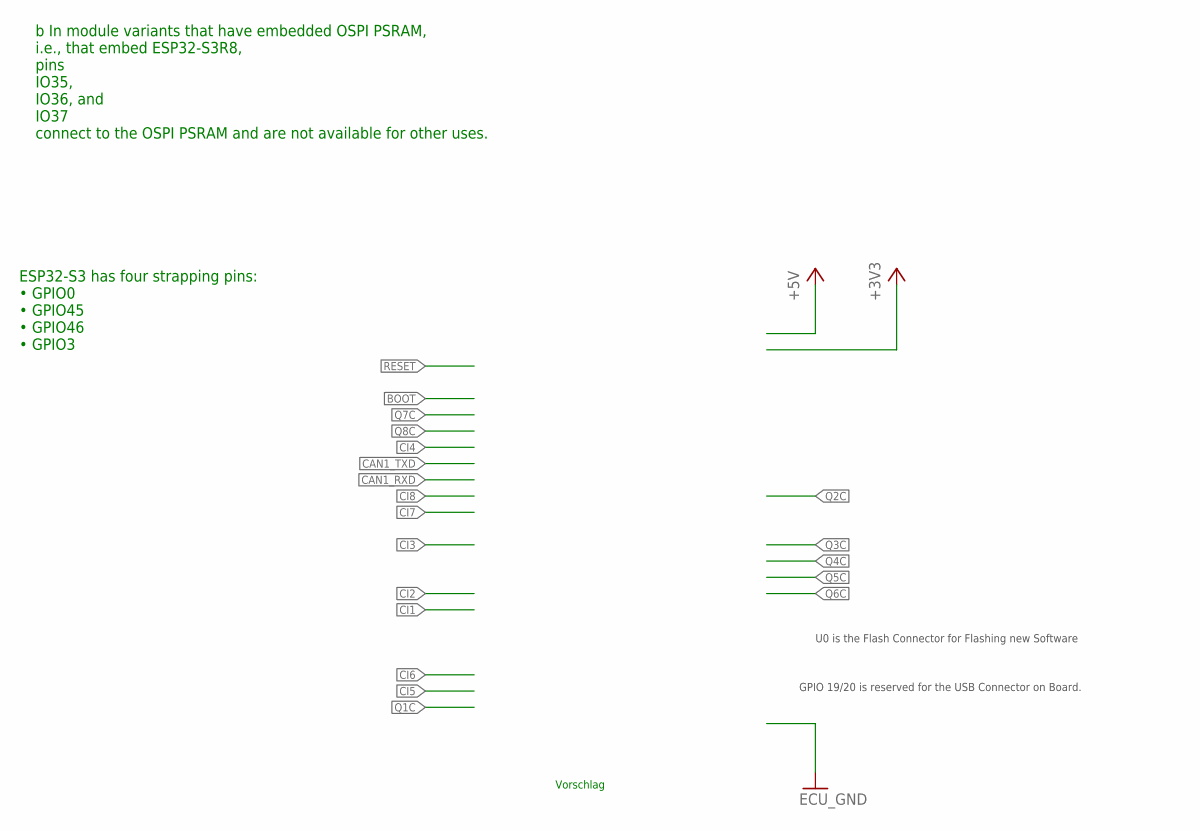
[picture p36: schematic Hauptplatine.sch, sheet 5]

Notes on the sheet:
Vorschlag
ESP32-S3 has four strapping pins: • GPIO0 • GPIO45 • GPIO46 • GPIO3
b In module variants that have embedded OSPI PSRAM, i.e., that embed ESP32-S3R8, pins IO35, IO36, and IO37 connect to the OSPI PSRAM and are not available for other uses.
GPIO 19/20 is reserved for the USB Connector on Board.
U0 is the Flash Connector for Flashing new Software

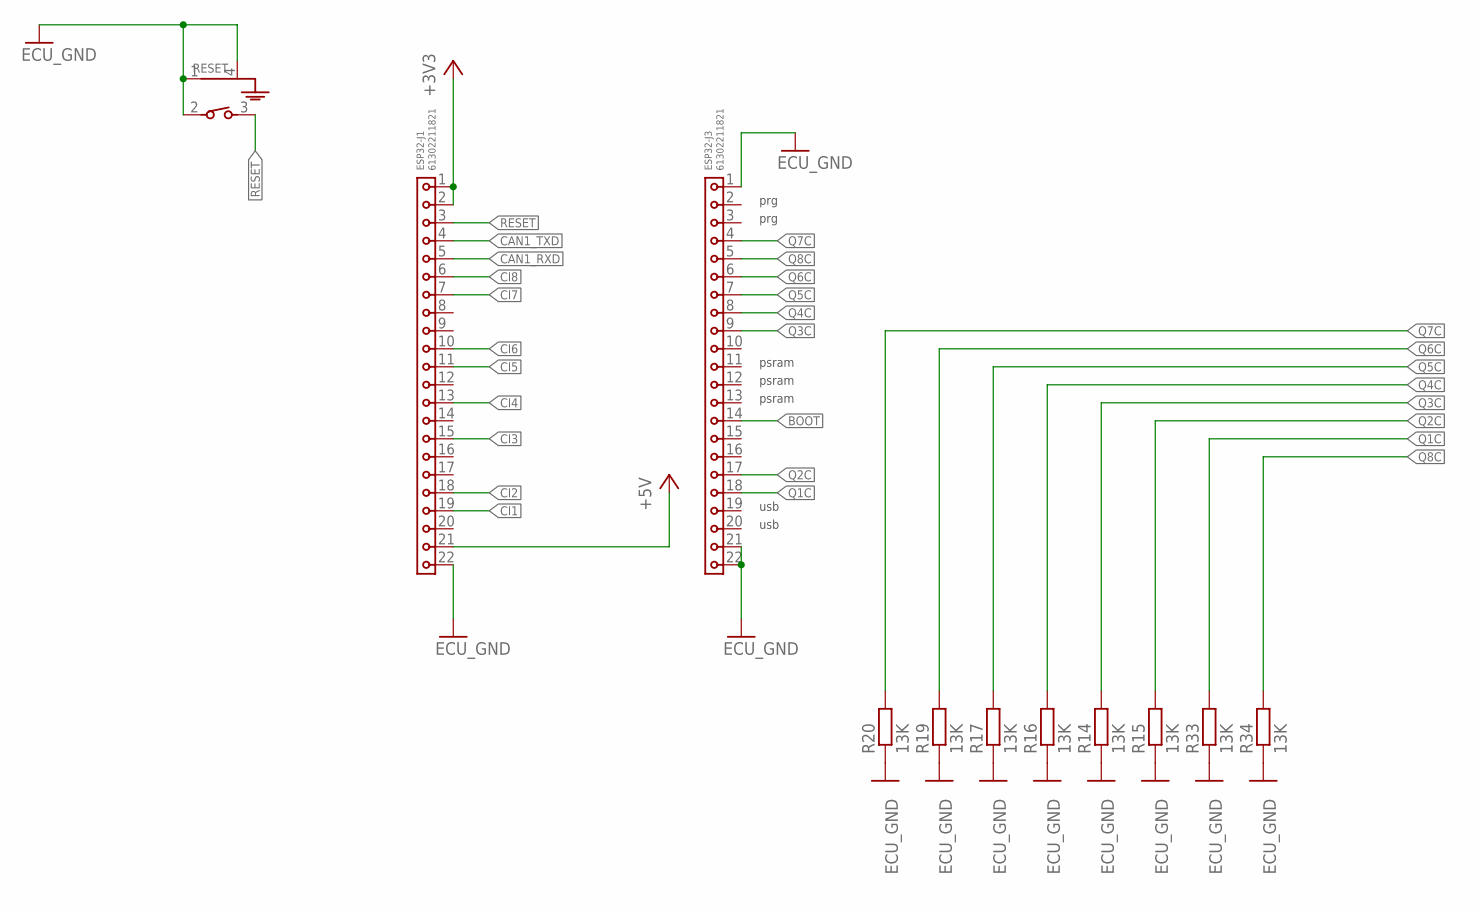
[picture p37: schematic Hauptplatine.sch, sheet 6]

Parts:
ESP32-J1, ESP32-J3: 61302211821
R14, R15, R16, R17, R19, R20, R33, R34: 13K; R1206
RESET: 431256083736; 4312560837X6

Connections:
+3V3: ESP32-J1.1, ESP32-J1.2; also elsewhere on the board
+5V: ESP32-J1.21; also elsewhere on the board
BOOT: ESP32-J3.14
CAN1_RXD: ESP32-J1.5; also elsewhere on the board
CAN1_TXD: ESP32-J1.4; also elsewhere on the board
CI1: ESP32-J1.19; also elsewhere on the board
CI2: ESP32-J1.18; also elsewhere on the board
CI3: ESP32-J1.15; also elsewhere on the board
CI4: ESP32-J1.13; also elsewhere on the board
CI5: ESP32-J1.11; also elsewhere on the board
CI6: ESP32-J1.10; also elsewhere on the board
CI7: ESP32-J1.7; also elsewhere on the board
CI8: ESP32-J1.6; also elsewhere on the board
ECU_GND: ESP32-J1.22, ESP32-J3.1, ESP32-J3.21, ESP32-J3.22, R14.1, R15.1, R16.1, R17.1, R19.1, R20.1, R33.1, R34.1, RESET.1 (GND1), RESET.2, RESET.4 (GND); also elsewhere on the board
Q1C: ESP32-J3.18, R33.2; also elsewhere on the board
Q2C: ESP32-J3.17, R15.2; also elsewhere on the board
Q3C: ESP32-J3.9, R14.2; also elsewhere on the board
Q4C: ESP32-J3.8, R16.2; also elsewhere on the board
Q5C: ESP32-J3.7, R17.2; also elsewhere on the board
Q6C: ESP32-J3.6, R19.2; also elsewhere on the board
Q7C: ESP32-J3.4, R20.2; also elsewhere on the board
Q8C: ESP32-J3.5, R34.2; also elsewhere on the board
RESET: ESP32-J1.3, RESET.3

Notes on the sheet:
usb
prg
psram

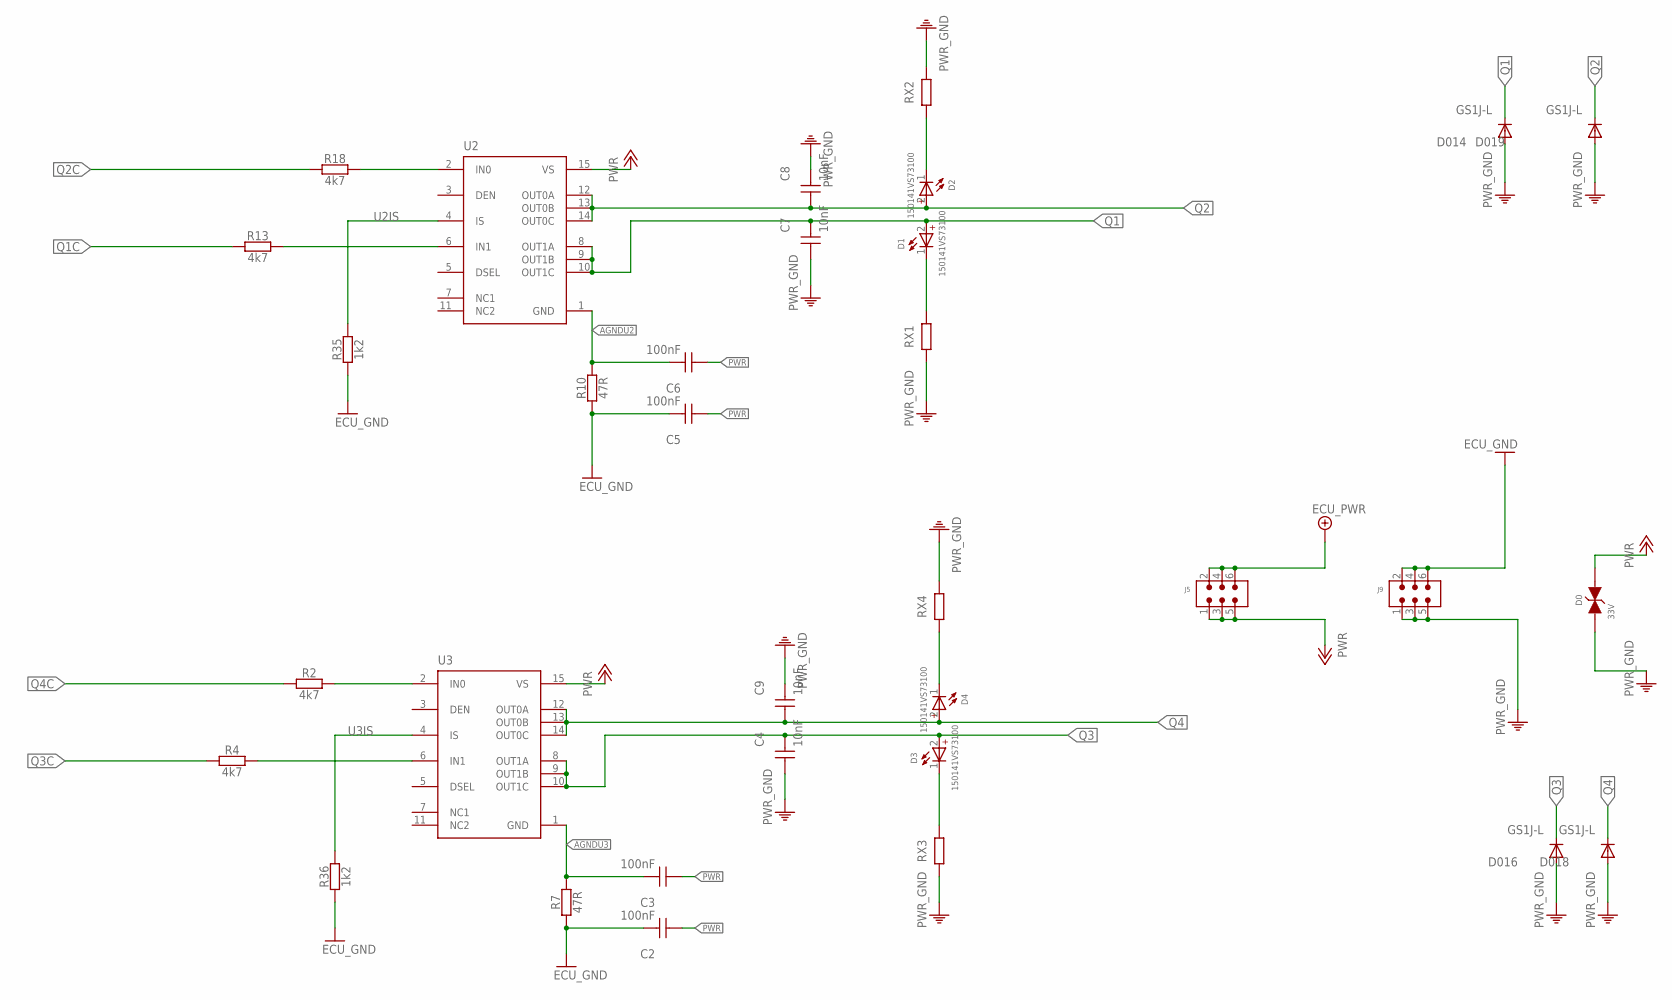
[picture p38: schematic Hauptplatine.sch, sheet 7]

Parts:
C2, C3, C5, C6: 100nF; WCAP-CSGP_0805_H0.8_R
C4, C7, C8, C9: 10nF; WCAP-CSGP_0805_H0.8_R
D0: 33V; WE-TVSP_DO-214AB_BIDIRECTIONAL
D1, D2, D3, D4: 150141VS73100; WL-SMTW_3528
D014, D016, D018, D019: GS1J-L; SMA_DO-214AC
J5, J9: 6130XX21121_61300621121; 61300621121
R2, R4, R13, R18: 4k7; R0805
R7, R10: 47R; R0805
R35, R36: 1k2; R0805
RX1, RX2, RX3, RX4: 470Ohm; R1206
U2, U3: BTS7030-2EPA; SOP65P600X115-15N-V

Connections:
AGNDU2: C6.2, R10.2, U2.1 (GND)
AGNDU3: C3.2, R7.2, U3.1 (GND)
ECU_GND: C2.2, C5.2, J9.2, J9.4, J9.6, R7.1, R10.1, R35.1, R36.1; also elsewhere on the board
ECU_PWR: J5.2, J5.4, J5.6; also elsewhere on the board
unnamed: D4.1 (-), RX4.1
unnamed: R2.2, U3.2 (IN0)
unnamed: R4.2, U3.6 (IN1)
unnamed: D2.1 (-), RX2.1
unnamed: D1.1 (-), RX1.2
unnamed: D3.1 (-), RX3.2
unnamed: R18.2, U2.2 (IN0)
unnamed: R13.2, U2.6 (IN1)
PWR: C2.1, C3.1, C5.1, C6.1, D0.2, J5.1, J5.3, J5.5, U2.15 (VS), U3.15 (VS); also elsewhere on the board
PWR_GND: C4.1, C7.1, C8.2, C9.2, D0.1, D014.A, D016.A, D018.A, D019.A, J9.1, J9.3, J9.5, RX1.1, RX2.2, RX3.1, RX4.2; also elsewhere on the board
Q1: C7.2, D1.2 (+), D014.C, U2.8 (OUT1A), U2.9 (OUT1B), U2.10 (OUT1C); also elsewhere on the board
Q1C: R13.1; also elsewhere on the board
Q2: C8.1, D2.2 (+), D019.C, U2.12 (OUT0A), U2.13 (OUT0B), U2.14 (OUT0C); also elsewhere on the board
Q2C: R18.1; also elsewhere on the board
Q3: C4.2, D3.2 (+), D016.C, U3.8 (OUT1A), U3.9 (OUT1B), U3.10 (OUT1C); also elsewhere on the board
Q3C: R4.1; also elsewhere on the board
Q4: C9.1, D4.2 (+), D018.C, U3.12 (OUT0A), U3.13 (OUT0B), U3.14 (OUT0C); also elsewhere on the board
Q4C: R2.1; also elsewhere on the board
U2IS: R35.2, U2.4 (IS)
U3IS: R36.2, U3.4 (IS)

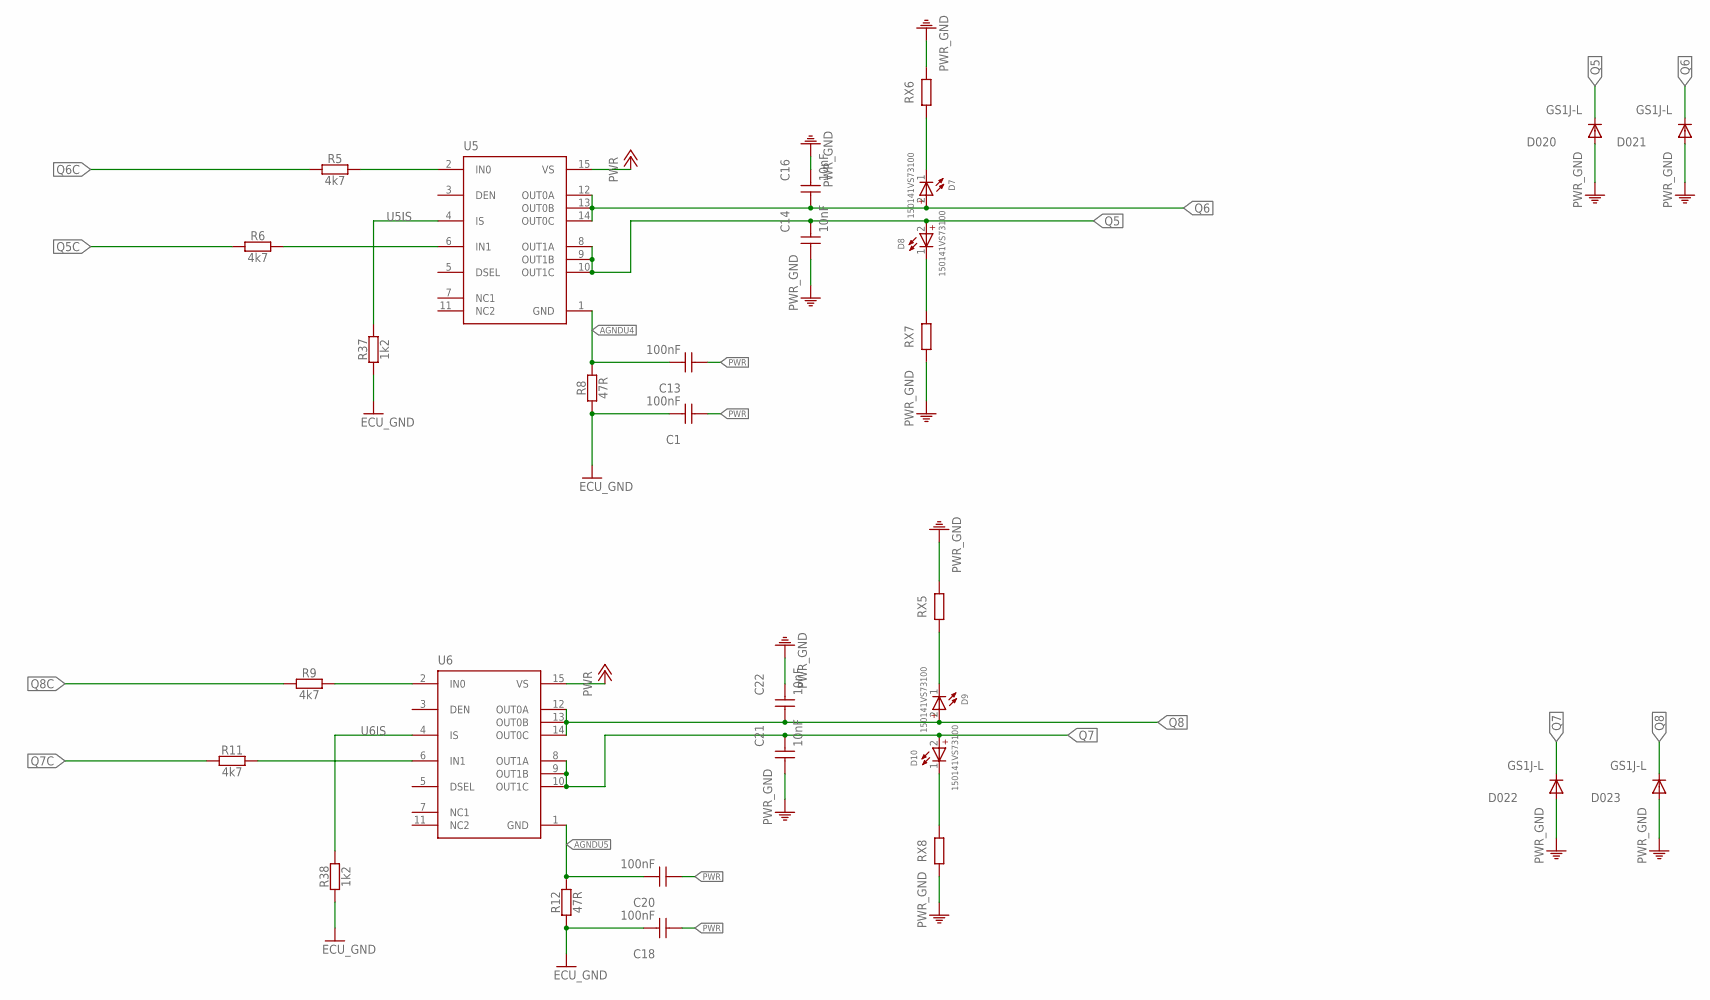
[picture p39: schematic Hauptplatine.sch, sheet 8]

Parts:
C1, C13, C18, C20: 100nF; WCAP-CSGP_0805_H0.8_R
C14, C16, C21, C22: 10nF; WCAP-CSGP_0805_H0.8_R
D7, D8, D9, D10: 150141VS73100; WL-SMTW_3528
D020, D021, D022, D023: GS1J-L; SMA_DO-214AC
R5, R6, R9, R11: 4k7; R0805
R8, R12: 47R; R0805
R37, R38: 1k2; R0805
RX5, RX6, RX7, RX8: 470Ohm; R1206
U5, U6: BTS7030-2EPA; SOP65P600X115-15N-V

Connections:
+6V: D7.1 (-), RX6.1
AGNDU4: C13.2, R8.2, U5.1 (GND)
AGNDU5: C20.2, R12.2, U6.1 (GND)
ECU_GND: C1.2, C18.2, R8.1, R12.1, R37.1, R38.1; also elsewhere on the board
unnamed: R5.2, U5.2 (IN0)
unnamed: R6.2, U5.6 (IN1)
unnamed: R9.2, U6.2 (IN0)
unnamed: R11.2, U6.6 (IN1)
unnamed: D9.1 (-), RX5.1
unnamed: D8.1 (-), RX7.2
unnamed: D10.1 (-), RX8.2
PWR: C1.1, C13.1, C18.1, C20.1, U5.15 (VS), U6.15 (VS); also elsewhere on the board
PWR_GND: C14.1, C16.2, C21.1, C22.2, D020.A, D021.A, D022.A, D023.A, RX5.2, RX6.2, RX7.1, RX8.1; also elsewhere on the board
Q5: C14.2, D8.2 (+), D020.C, U5.8 (OUT1A), U5.9 (OUT1B), U5.10 (OUT1C); also elsewhere on the board
Q5C: R6.1; also elsewhere on the board
Q6: C16.1, D7.2 (+), D021.C, U5.12 (OUT0A), U5.13 (OUT0B), U5.14 (OUT0C); also elsewhere on the board
Q6C: R5.1; also elsewhere on the board
Q7: C21.2, D10.2 (+), D022.C, U6.8 (OUT1A), U6.9 (OUT1B), U6.10 (OUT1C); also elsewhere on the board
Q7C: R11.1; also elsewhere on the board
Q8: C22.1, D9.2 (+), D023.C, U6.12 (OUT0A), U6.13 (OUT0B), U6.14 (OUT0C); also elsewhere on the board
Q8C: R9.1; also elsewhere on the board
U5IS: R37.2, U5.4 (IS)
U6IS: R38.2, U6.4 (IS)

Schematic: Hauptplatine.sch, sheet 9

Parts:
C31, C32, C33, C34: 100nF; WCAP-CSGP_1206_H0.8
D13: 3.3Vdc; WE-TVS_SOT143-4L
R21, R24: 1K2; R1206
R22, R25: 47K; R1206
R23, R26: 22K; R1206

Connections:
+3V3: D13.4 (VDD); also elsewhere on the board
CI1: C32.1, D13.3 (2), R22.1, R23.2; also elsewhere on the board
CI2: C34.1, D13.2 (1), R25.1, R26.2; also elsewhere on the board
ECU_GND: C31.2, C32.2, C33.2, C34.2, D13.1 (GND), R21.1, R23.1, R24.1, R26.1; also elsewhere on the board
I1: C31.1, R21.2, R22.2; also elsewhere on the board
I2: C33.1, R24.2, R25.2; also elsewhere on the board

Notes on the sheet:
Symbol Parameter Min Typ Max Unit CIN Pin capacitance - 2 - pF VIH High-level input voltage 0.75×VDD1 - VDD1+0.3 V (‭2,475‬V - 3.6V) VIL Low-level input voltage –0.3 - 0.25×VDD1 V (-0,3 - ‭0,825‬V)
2.6V bei 12V 3.07 bei 14.2V

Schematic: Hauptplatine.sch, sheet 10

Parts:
C39, C40, C41, C42: 100nF; WCAP-CSGP_1206_H0.8
D15: 3.3Vdc; WE-TVS_SOT143-4L
R39, R42: 1K2; R1206
R40, R43: 47K; R1206
R41, R44: 22K; R1206

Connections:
+3V3: D15.4 (VDD); also elsewhere on the board
CI3: C40.1, D15.3 (2), R40.1, R41.2; also elsewhere on the board
CI4: C42.1, D15.2 (1), R43.1, R44.2; also elsewhere on the board
ECU_GND: C39.2, C40.2, C41.2, C42.2, D15.1 (GND), R39.1, R41.1, R42.1, R44.1; also elsewhere on the board
I3: C39.1, R39.2, R40.2; also elsewhere on the board
I4: C41.1, R42.2, R43.2; also elsewhere on the board

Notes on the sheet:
Symbol Parameter Min Typ Max Unit CIN Pin capacitance - 2 - pF VIH High-level input voltage 0.75×VDD1 - VDD1+0.3 V (‭2,475‬V - 3.6V) VIL Low-level input voltage –0.3 - 0.25×VDD1 V (-0,3 - ‭0,825‬V)
2.6V bei 12V 3.07 bei 14.2V

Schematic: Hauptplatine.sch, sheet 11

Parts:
C47, C48, C49, C50: 100nF; WCAP-CSGP_1206_H0.8
D17: 3.3Vdc; WE-TVS_SOT143-4L
R51, R54: 1K2; R1206
R52, R55: 47K; R1206
R53, R56: 22K; R1206

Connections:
+3V3: D17.4 (VDD); also elsewhere on the board
CI5: C48.1, D17.3 (2), R52.1, R53.2; also elsewhere on the board
CI6: C50.1, D17.2 (1), R55.1, R56.2; also elsewhere on the board
ECU_GND: C47.2, C48.2, C49.2, C50.2, D17.1 (GND), R51.1, R53.1, R54.1, R56.1; also elsewhere on the board
I5: C47.1, R51.2, R52.2; also elsewhere on the board
I6: C49.1, R54.2, R55.2; also elsewhere on the board

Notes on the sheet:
Symbol Parameter Min Typ Max Unit CIN Pin capacitance - 2 - pF VIH High-level input voltage 0.75×VDD1 - VDD1+0.3 V (‭2,475‬V - 3.6V) VIL Low-level input voltage –0.3 - 0.25×VDD1 V (-0,3 - ‭0,825‬V)
2.6V bei 12V 3.07 bei 14.2V

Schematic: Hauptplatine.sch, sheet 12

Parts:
C24, C25, C26, C27: 100nF; WCAP-CSGP_1206_H0.8
D12: 3.3Vdc; WE-TVS_SOT143-4L
R27, R28: 1K2; R1206
R29, R30: 47K; R1206
R31, R32: 22K; R1206

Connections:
+3V3: D12.4 (VDD); also elsewhere on the board
CI7: C27.1, D12.3 (2), R30.1, R32.2; also elsewhere on the board
CI8: C26.1, D12.2 (1), R29.1, R31.2; also elsewhere on the board
ECU_GND: C24.2, C25.2, C26.2, C27.2, D12.1 (GND), R27.1, R28.1, R31.1, R32.1; also elsewhere on the board
I7: C25.1, R28.2, R30.2; also elsewhere on the board
I8: C24.1, R27.2, R29.2; also elsewhere on the board

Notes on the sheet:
Symbol Parameter Min Typ Max Unit CIN Pin capacitance - 2 - pF VIH High-level input voltage 0.75×VDD1 - VDD1+0.3 V (‭2,475‬V - 3.6V) VIL Low-level input voltage –0.3 - 0.25×VDD1 V (-0,3 - ‭0,825‬V)
2.6V bei 12V 3.07 bei 14.2V

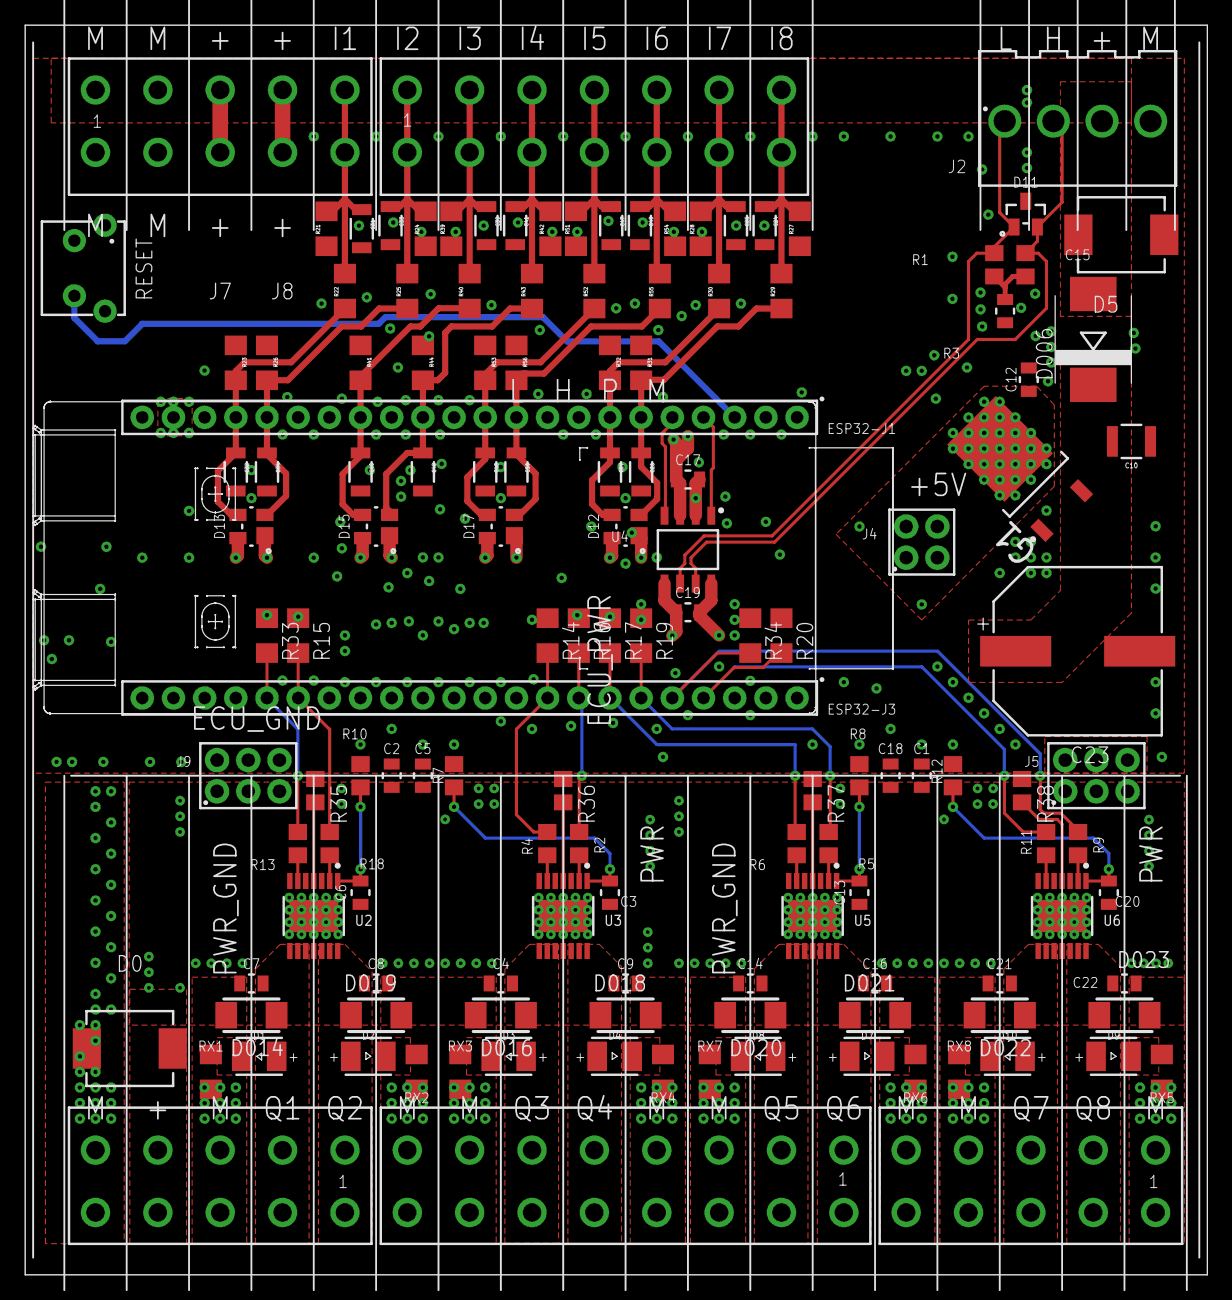
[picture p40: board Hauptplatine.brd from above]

Board: 4 copper layers, 96.3 x 101.8 mm, 138 parts (0 on the bottom side), 69 nets.

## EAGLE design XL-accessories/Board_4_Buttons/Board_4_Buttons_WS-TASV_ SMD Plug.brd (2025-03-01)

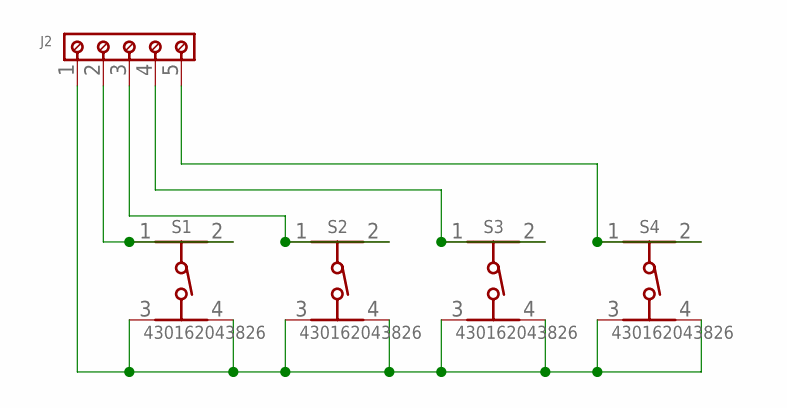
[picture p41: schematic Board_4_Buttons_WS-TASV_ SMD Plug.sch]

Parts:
J2: 691709710305
S1, S2, S3, S4: 430162043826

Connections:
unnamed: J2.1, S1.3 (2), S1.4, S2.3 (2), S2.4, S3.3 (2), S3.4, S4.3 (2), S4.4
unnamed: J2.2, S1.1, S1.2 (3)
unnamed: J2.3, S2.1, S2.2 (3)
unnamed: J2.4, S3.1, S3.2 (3)
unnamed: J2.5, S4.1, S4.2 (3)

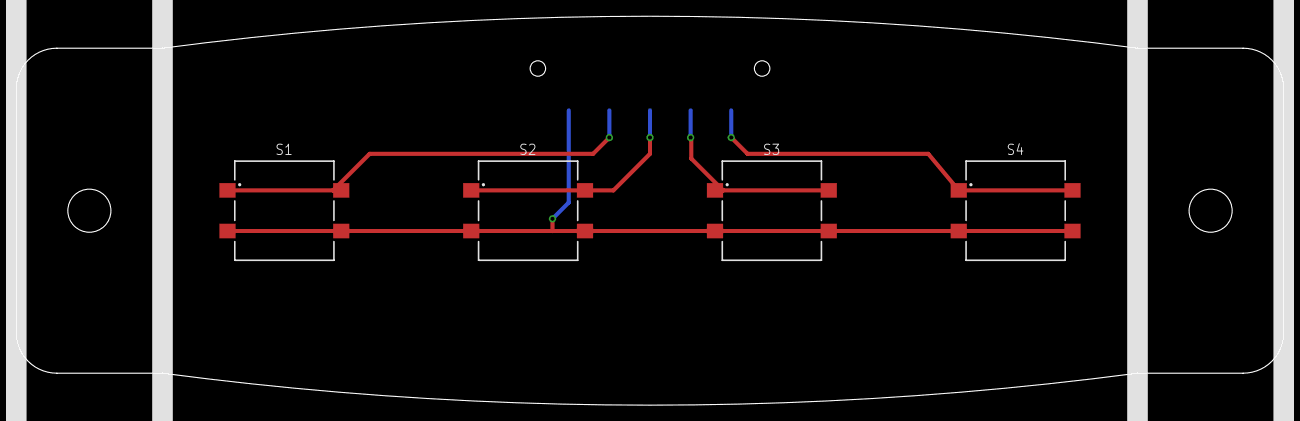
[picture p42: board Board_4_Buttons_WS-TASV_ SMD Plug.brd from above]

Board: 2 copper layers, 156.0 x 47.9 mm, 5 parts (1 on the bottom side), 5 nets.

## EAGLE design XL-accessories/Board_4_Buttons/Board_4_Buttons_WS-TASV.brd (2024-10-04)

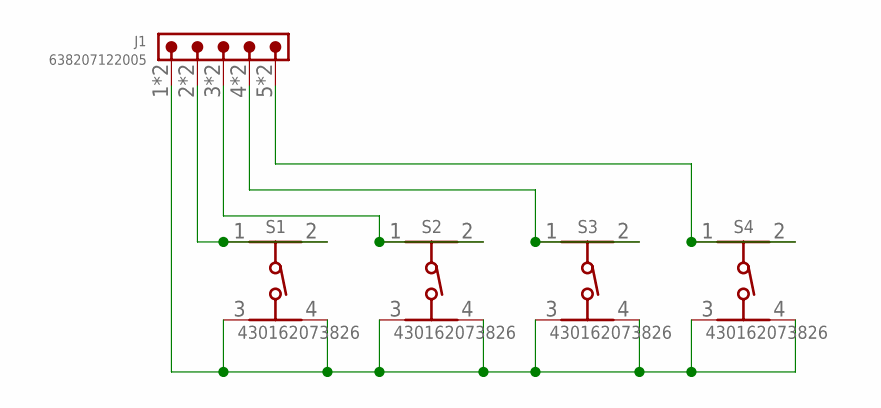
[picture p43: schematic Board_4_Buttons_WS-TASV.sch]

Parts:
J1: 638207122005
S1, S2, S3, S4: 430162073826

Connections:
unnamed: J1.1, J1.A1 (1), S1.3 (2), S1.4, S2.3 (2), S2.4, S3.3 (2), S3.4, S4.3 (2), S4.4
unnamed: J1.2, J1.A2 (2), S1.1, S1.2 (3)
unnamed: J1.3, J1.A3 (3), S2.1, S2.2 (3)
unnamed: J1.4, J1.A4 (4), S3.1, S3.2 (3)
unnamed: J1.5, J1.A5 (5), S4.1, S4.2 (3)


Board: 2 copper layers, 156.0 x 47.9 mm, 5 parts (1 on the bottom side), 5 nets.

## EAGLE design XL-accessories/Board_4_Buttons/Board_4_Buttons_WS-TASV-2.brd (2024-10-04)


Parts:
J1: 691709710305
S1, S2, S3, S4: 430162073826; 4304X60437X6

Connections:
unnamed: J1.1, S1.3 (2), S1.4, S2.3 (2), S2.4, S3.3 (2), S3.4, S4.3 (2), S4.4
unnamed: J1.2, S1.1, S1.2 (3)
unnamed: J1.3, S2.1, S2.2 (3)
unnamed: J1.4, S3.1, S3.2 (3)
unnamed: J1.5, S4.1, S4.2 (3)


Board: 2 copper layers, 156.0 x 47.9 mm, 5 parts (1 on the bottom side), 5 nets.

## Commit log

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2020-08-29 collission avoid.
    [Atomic_V1.0.brd, Atomic_V1.0.sch]
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2021-08-06 correction !
    [Atomic_Stick.brd]
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2021-11-18 was a bad bug about 2 Pins.
    [M5_STACK_STAMP_C3_ISOBUS.brd, M5_STACK_STAMP_C3_ISOBUS.sch]
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2024-02-29 Change grid unit to mm, adjust layer visibility and settings, update Fusion 360 sync status, modify wire connections and text positions.
    [Hutschienenmoped_XL_12V.brd, Hutschienenmoped_XL_12V.dxf, Hutschienenmoped_XL_12V.sch]
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2024-03-24 Add Eagle version and libraries to configuration file
    The commit adds Eagle version "09 06 02" and numerous library URNs to the configuration file.
    [Hutschienenmoped-XL_1ETH.brd, Hutschienenmoped-XL_1ETH.sch, Hutschienenmoped-XL_2ETH.brd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]
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2024-03-24 Update component position in board layout.
    Adjusted coordinates for a component on the board to new location.
    [Hutschienenmoped-XL_2ETH.brd]
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2024-03-24 Adjust wire widths and grid units, optimize for mm instead of mil.
    - Updated wire widths to 0.1 from 0.001
    - Changed grid unit distance to mm from mil
    [Hutschienenmoped-XL_2ETH.brd]
2024-03-24 Update grid settings to display grid lines, add wires for a new component. Remove redundant package elements and attributes.
    [Hutschienenmoped-XL_2ETH.brd, Hutschienenmoped-XL_2ETH.sch]
2024-03-24 Update grid distance in board file and rename connector elements: - Changed grid distance from 6mm to 22.86mm for better alignment. - Renamed connector elements J12, J14 to W1-J2, W1-J1 respectively.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
    [Hutschienenmoped-XL_2ETH.brd, Hutschienenmoped-XL_2ETH.sch]
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2024-03-24 Update connector attributes for W1-J2 and W1-J1 elements. Fix rotation and layer settings.
    [Hutschienenmoped-XL_2ETH.brd]
2024-03-24 Update grid settings, change font display, adjust pad sizes and hole drills, add new package with 10-pin socket header, modify parameter values for pads and vias. Add symbol for 10-pin socket header 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
    [Hutschienenmoped-XL_2ETH.brd, Hutschienenmoped-XL_2ETH.sch]
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2024-03-24 Update package description and pad positions, adjust hole sizes, and modify parameters for better PCB design. Add new contact references, wires, and signals for improved connectivity.
    [Hutschienenmoped-XL_2ETH.brd, Hutschienenmoped-XL_2ETH.sch]
2024-03-24 Update Fusion 360 sync details and add new signal connections. Add text labels for USB, PRG, and PSRAM on the schematic sheet.
    [Hutschienenmoped-XL_2ETH.brd, Hutschienenmoped-XL_2ETH.sch]
2024-03-24 Update layer visibility settings and pad dimensions. Adjusted layer visibility to improve clarity. Increased maximum pad sizes for top and bottom layers from 0.5mm to 1mm for better functionality. Mo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
    [Hutschienenmoped-XL_2ETH.brd, Hutschienenmoped-XL_2ETH.sch]
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2024-03-24 Update grid settings, layer visibility, and parameters. Refine wire connections for improved layout consistency.
    [Hutschienenmoped-XL_2ETH.brd]
2024-03-24 Change grid unit from mil to mm, adjust polygon width, add contact references for elements J13 and J9, update via drill sizes, modify wire connections for various signals.
    [Hutschienenmoped-XL_2ETH.brd, Hutschienenmoped-XL_2ETH.sch]
2024-03-24 Change grid settings to 50mm, hide grid display. Simplify wire connections in the layout for better clarity and organization. Adjust polygon widths for consistency and isolate values. Add vias for im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
    [Hutschienenmoped-XL_2ETH.brd]
2024-03-24 Update grid settings and layer visibility. Adjust attributes of elements C15, D5, R1, R3.
    [Hutschienenmoped-XL_2ETH.brd]
2024-03-24 Update vias and wires coordinates for better routing efficiency.
    - Adjusted via positions for improved connectivity.
    - Modified wire paths to optimize signal flow.
    [Hutschienenmoped-XL_2ETH.brd]
2024-03-24 Add resistors R14 and R15, update wiring connections. - Added resistors R14 and R15 with values of 13K. - Updated wiring connections for resistors R14 and R15 in the schematic and board files.
    [Hutschienenmoped-XL_2ETH.brd, Hutschienenmoped-XL_2ETH.sch]
2024-03-24 Update FusionSync revision IDs and remove variant definitions.
    The FusionSync revision IDs were updated in both the board and schematic files. Additionally, variant definitions for "ECU Type I non terminated" and "b" were removed from both files.
    [Hutschienenmoped-XL_2ETH.brd, Hutschienenmoped-XL_2ETH.sch]
2024-03-24 Add new components and quantities to CSV file. - Include various resistors, capacitors, diodes, headers. - Update existing entries with detailed descriptions.
    [Hutschienenmoped-XL_2ETH.csv]
2024-03-24 Add new Excel file for Hutschienenmoped-XL_2ETH model.
    A new Excel file has been added for the Hutschienenmoped-XL_2ETH model.
    [Hutschienenmoped-XL_2ETH.xlsx]
2024-03-24 Change grid distance to 50 mil, update layer visibility settings. Adjust text and wire placements for clarity. Update package library versions for footprints.
    [Hutschienenmoped-XL_2ETH.brd, Hutschienenmoped-XL_2ETH.sch]
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2024-03-24 NOT correct !
    [Hutschienenmoped_XL_12V.brd, Hutschienenmoped_XL_12V.sch]
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2024-03-24 Update grid settings and Fusion 360 sync details, remove redundant wires and text elements, optimize polygon vertices, clean up vias and wire connections.
    [Hutschienenmoped_XL_12V.brd, Hutschienenmoped_XL_12V.sch]
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2024-10-04 gitflow-feature-stash: prot Add SMA_DO-214AC package, elements D014 to D023 with attributes, and resistors R35 to R38. Update classes Ampere7 and clearance values. Include wire connections for new el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
    [Hutschienenmoped_XL_12V.brd, Hutschienenmoped_XL_12V.sch]
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2025-02-27 Update font setting to not always vector and adjust text position in the layout. Fix FusionSync PCB link status.
    [Riegel links oben B (1).brd]
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

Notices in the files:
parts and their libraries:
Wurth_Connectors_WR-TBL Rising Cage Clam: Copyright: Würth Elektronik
